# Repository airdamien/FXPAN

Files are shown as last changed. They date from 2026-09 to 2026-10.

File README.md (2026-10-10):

# FXPAN

Two Nikon D800 bodies behind one Nikkor-W 180 mm f/5.6. A 50 × 75 mm
beamsplitter sends each body half of the field. The stitch is

**64.80 × 23.9 mm · 2.711:1 · 13248 × 4912 · 65.1 MP**

XPan is 65 × 24 mm at 2.708:1. It is shot from f/5.6 to f/22. The
Nikkor-W covers the stitch wide open. The 44 mm mouths fully clear the
extreme corners from f/8.4; at f/5.6 those corners still pass most of the
light, and the long axis stays clean. The iPhone is the viewfinder and the
stitcher, and it can release both bodies over USB. A Pi Zero and the trigger
board are optional. They pulse both 10-pin remotes together.

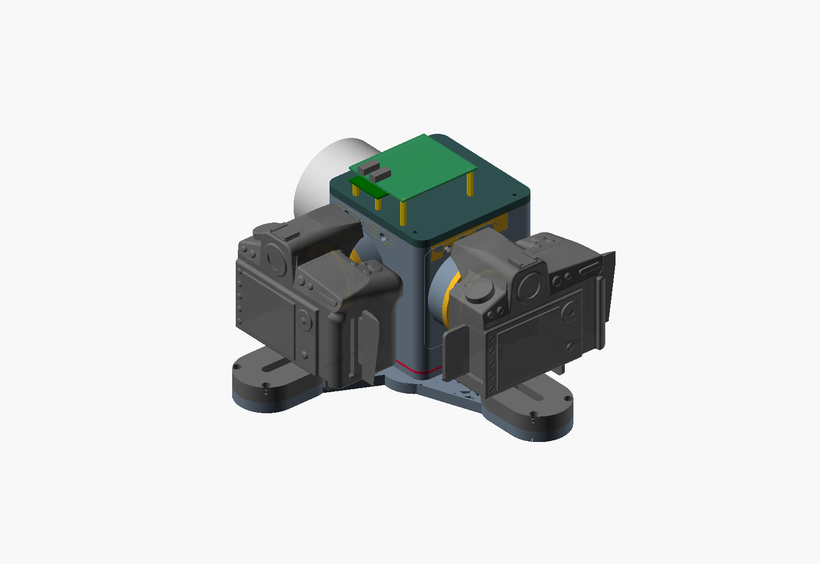
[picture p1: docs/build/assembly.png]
Assembled. Nikkor-W to the left, a D800 on each arm, trigger board on the lid.


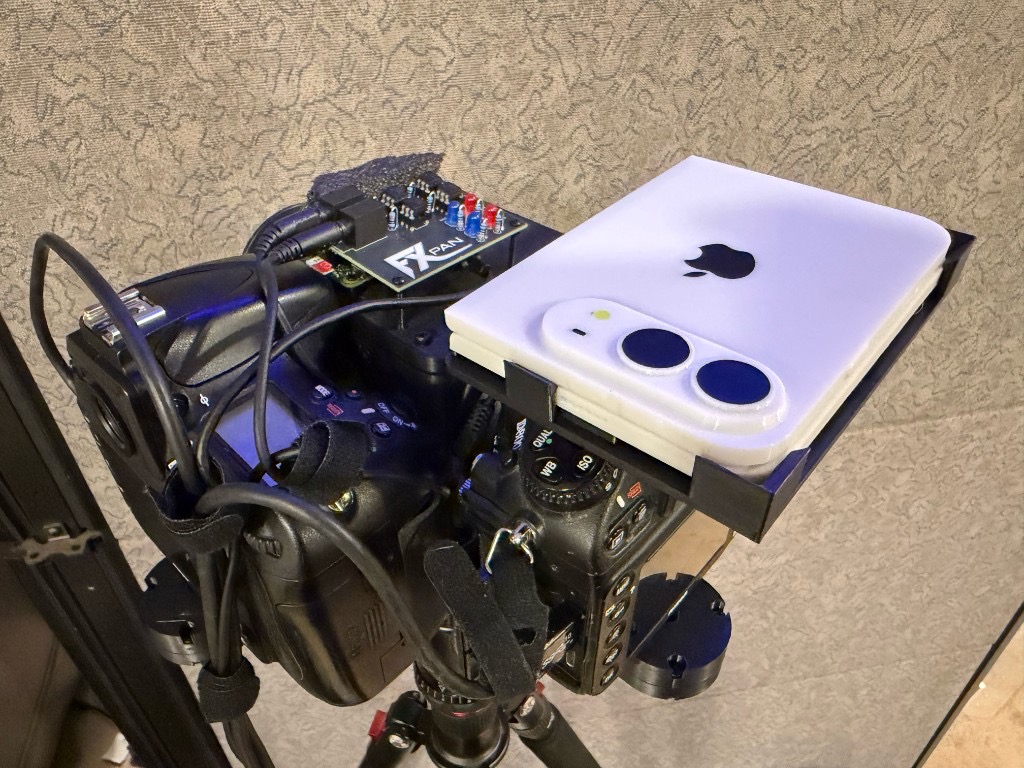
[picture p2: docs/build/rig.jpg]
The rig: two D800s, the trigger board, the iPhone


Buy list, print list, and assembly: [bom.md](bom.md).
The model, the measured focus numbers, and the long alignment notes:
[openscad/fxpan/README.md](openscad/fxpan/README.md).

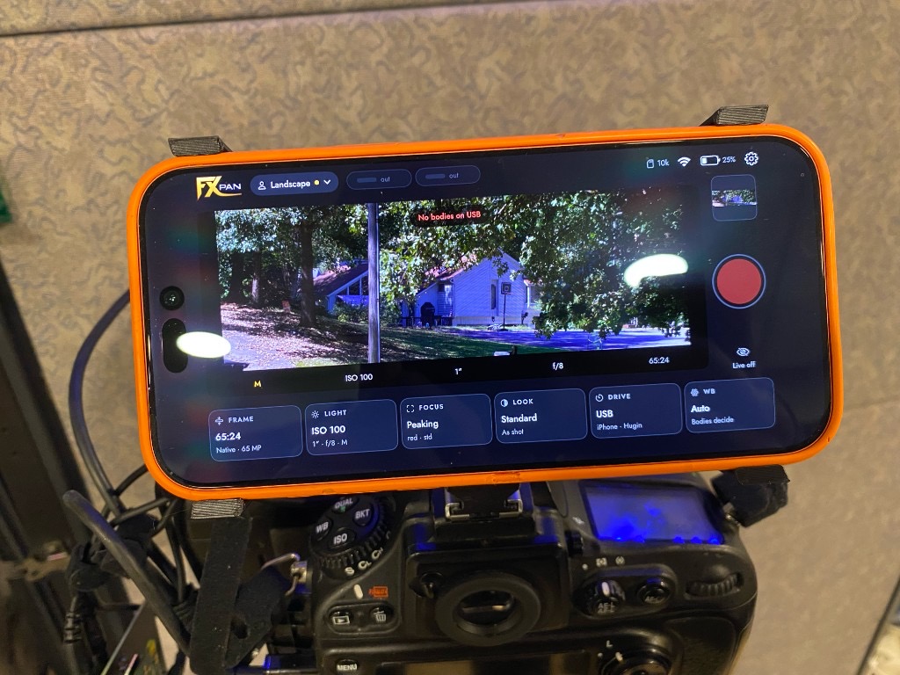
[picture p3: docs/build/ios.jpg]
The phone on the camera.


## On the phone

Landscape on an iPhone 17 Pro Max, in simulate mode.

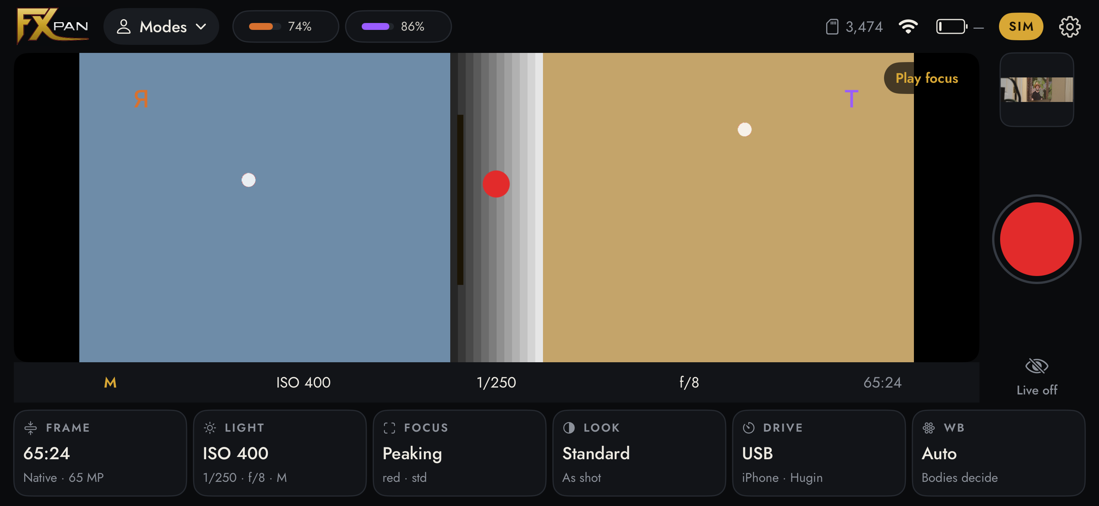
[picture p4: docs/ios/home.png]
Home. The stitch on the left, the shutter on the right, six controls along the bottom.


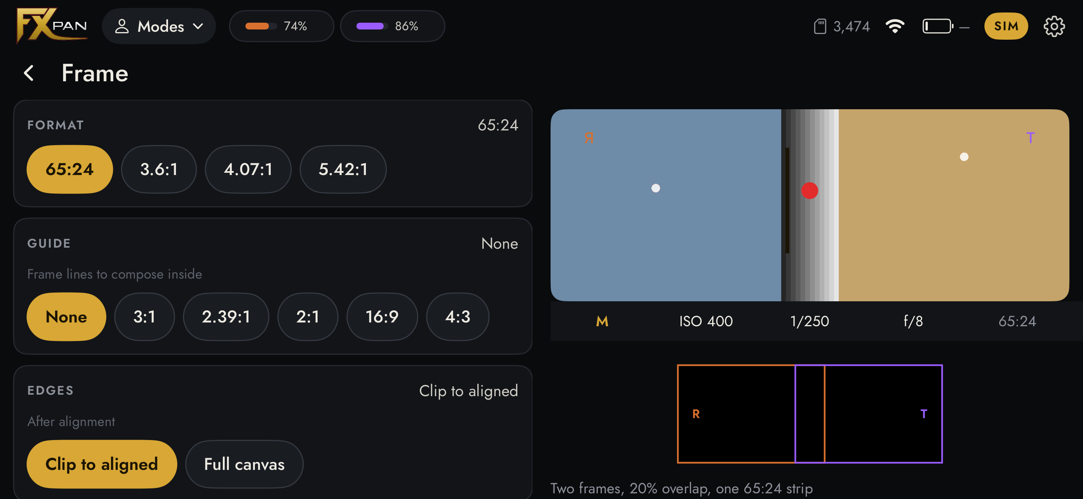
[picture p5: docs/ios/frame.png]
Frame. Format, guide lines, and whether the edges clip to the overlap.


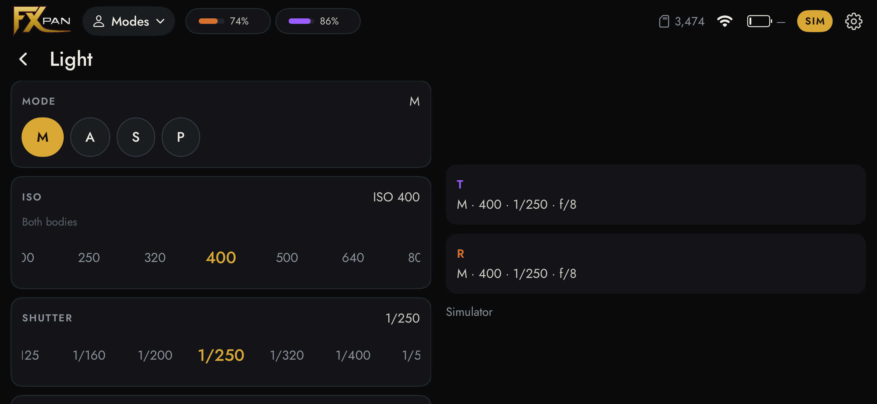
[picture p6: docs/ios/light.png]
Light. Mode, ISO, and shutter for both bodies.


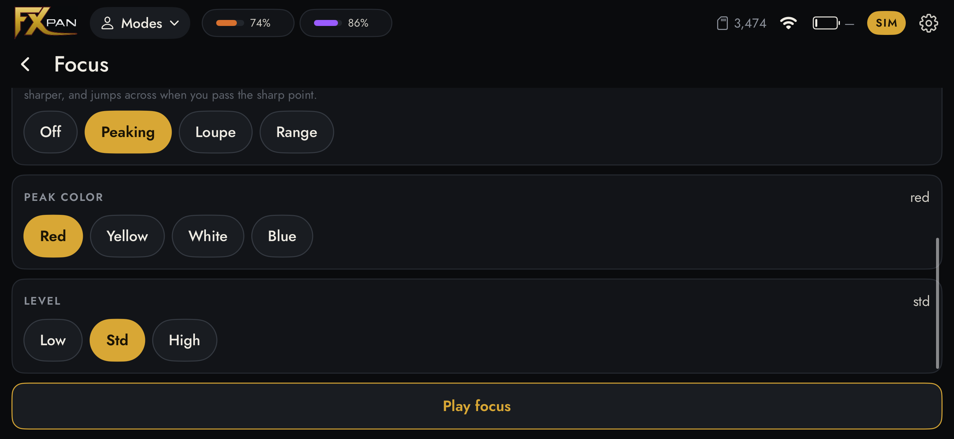
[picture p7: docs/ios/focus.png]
Focus. Peaking, loupe, or range.


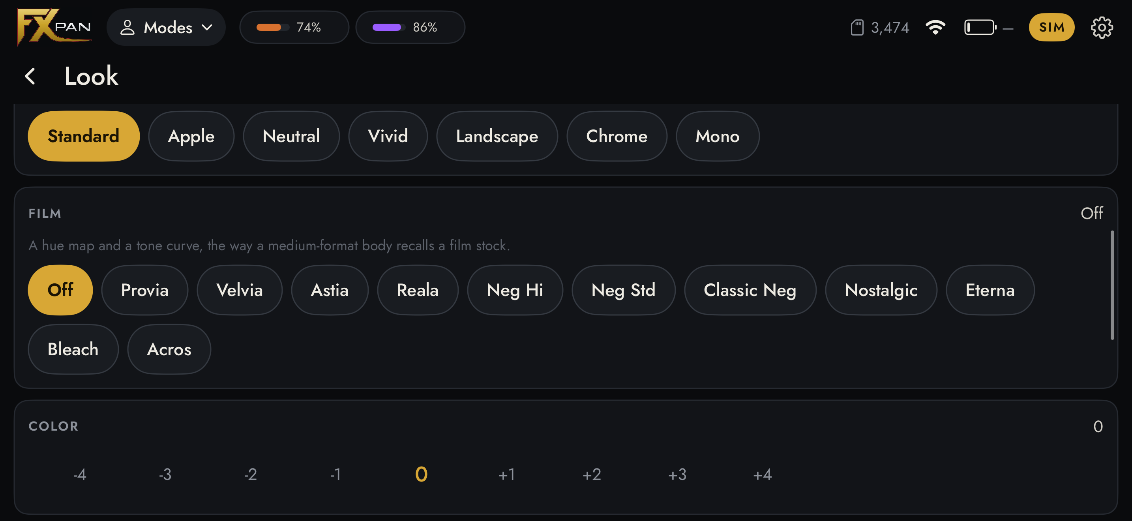
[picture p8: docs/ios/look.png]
Look. The base, the film stocks, and the color step.


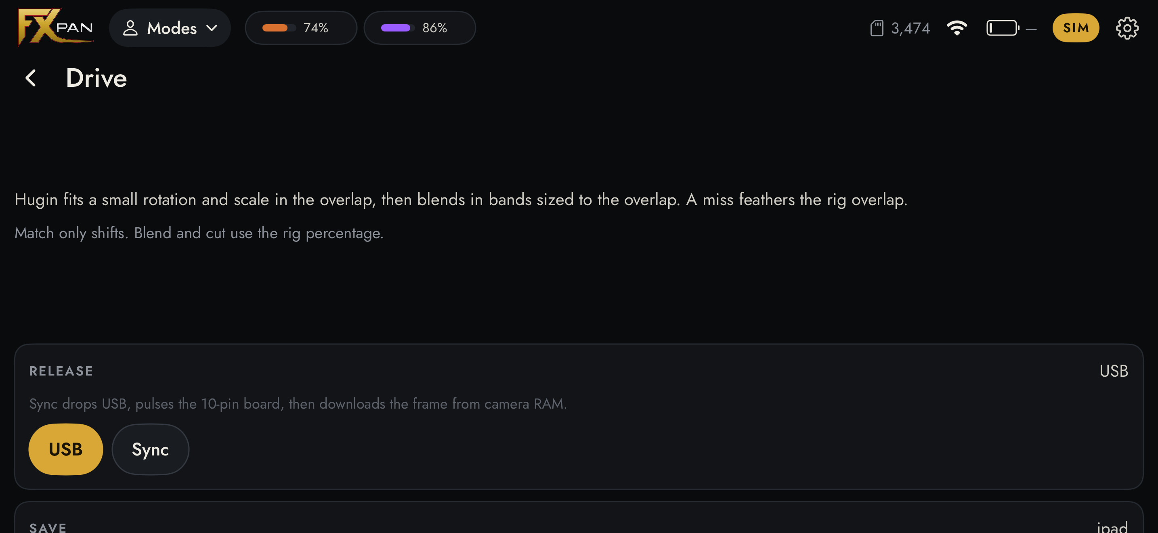
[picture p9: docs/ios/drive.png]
Drive. USB, or the 10-pin sync.


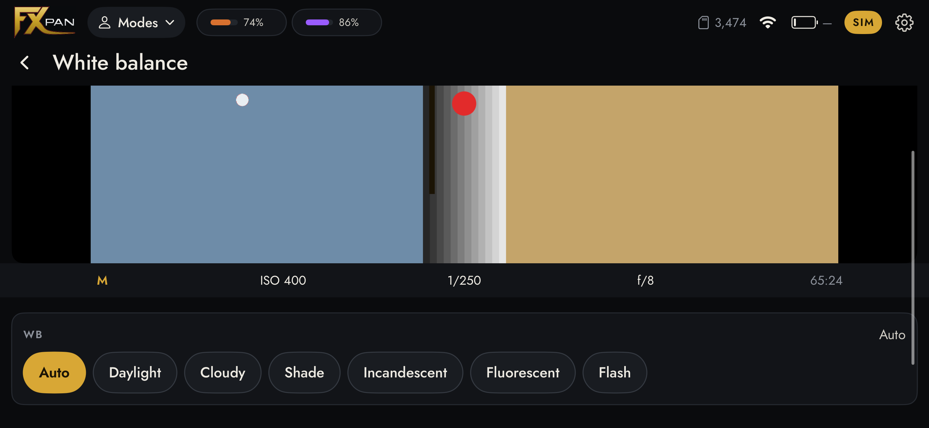
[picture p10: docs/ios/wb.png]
White balance.


Partly folded on an iPhone Duo. The picture and the last shots stay above the hinge. The controls and the shutter sit below it.

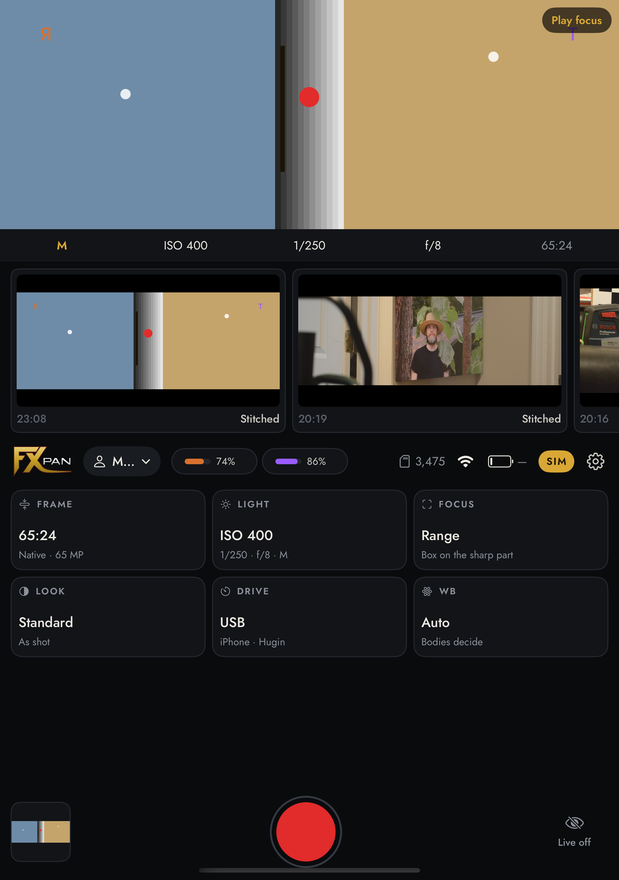
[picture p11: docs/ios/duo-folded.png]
Half open.


## Panoramic video

Drive chooses Still or Video. Video records both D800s, copies both clips
to the phone, lines the frames up, and stitches a panorama movie. The
shutter starts the recording and stops it. Each body writes a MOV on its
card, and that copy stays.

Both bodies are set up together. The record command then goes to both at
once, and the stop does the same. The phone keeps the few milliseconds
between the two starts, matches how the picture moves in each clip, and
drops the leading frames from the body that started first. Stitch again
runs that match and the stitch a second time.

Exposure is manual and shared: ISO, shutter, and aperture. Aperture is
written with live view down, which is when a D800 will take it. The bodies
are back on stills before the next frame.

One pair of frames sets the overlap, the warp, the crop, and the tone.
Every later frame uses that fit, with a multiband blend. A weak overlap
fit uses the rig's feather for the whole clip.

Playback plays the panorama, and each body's clip on its own. Share,
protect, delete, and Stitch again are there.

## A Canon, as a try

System has a Canon switch. It stays off until you turn it on. One body, not the pair, and not the stitch.

The camera's USB connection is photo import / remote control. Live view, the shutter, and the copy use that body. The JPEG shows in the roll. A CR3 is saved beside it. The file stays on the card. Turn the switch off and the Nikon pair is back.

## How it goes together

The plate is in the tray, coating toward the lens, 75 mm across the fold.
The two arms leave the box at a right angle. The base carries both bodies.
The mouths are printed F. The lens is the Nikkor-W.

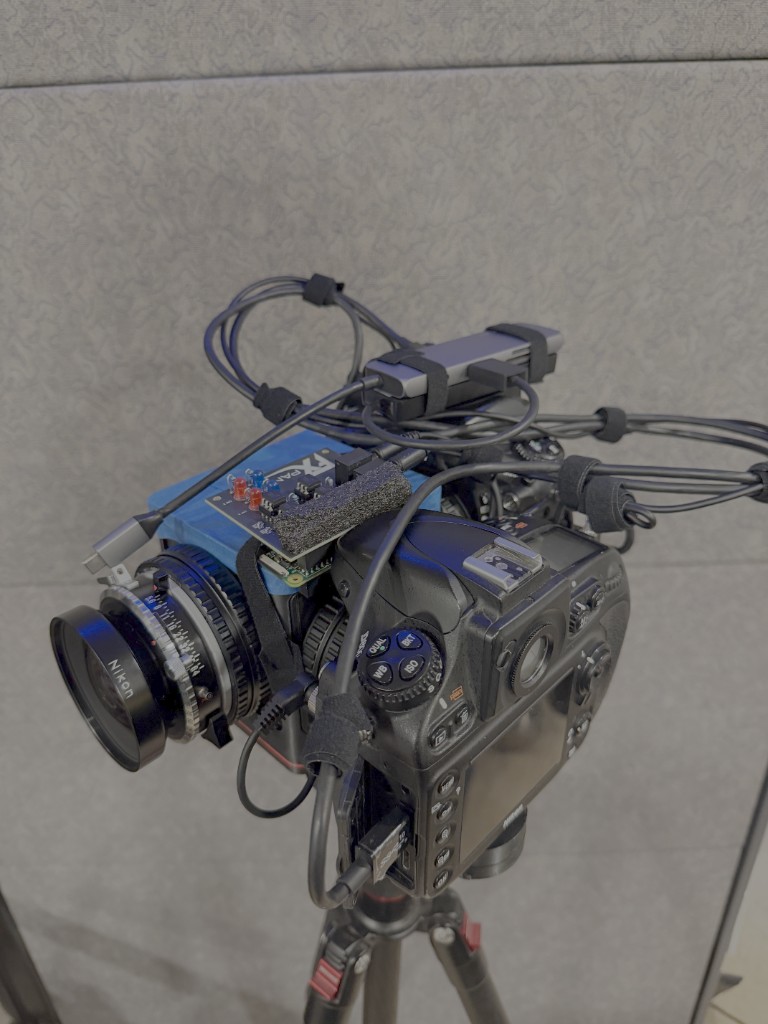
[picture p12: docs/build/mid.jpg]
Mid-build. One body on, the Nikkor-W in the stem, the trigger board on the lid.


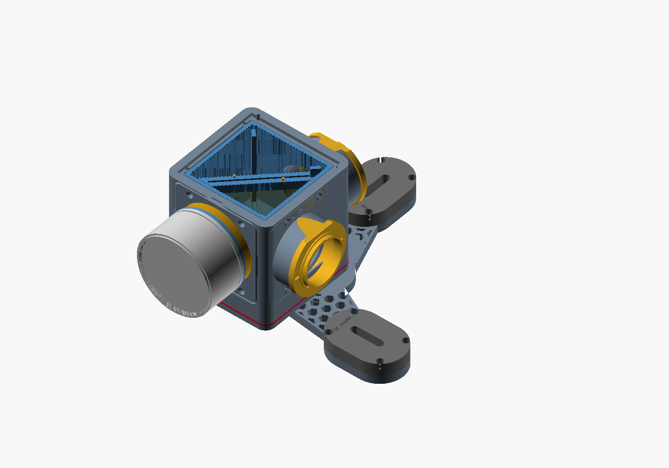
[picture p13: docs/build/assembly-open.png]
Lid off. The blue plate is the 50 × 75 mm splitter.


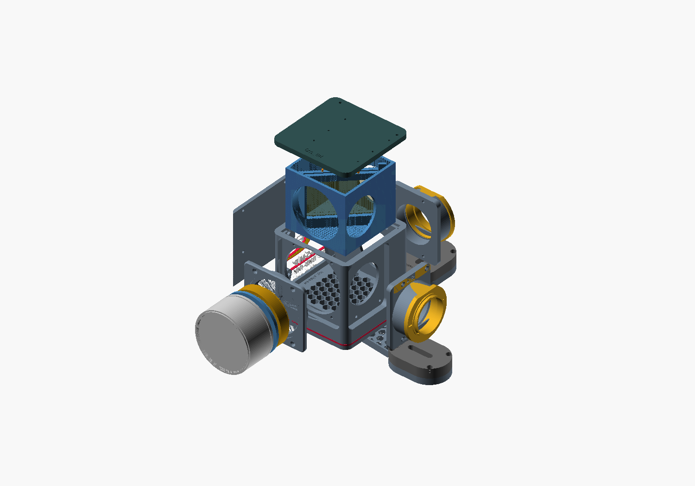
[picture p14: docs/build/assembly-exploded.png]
Pulled apart: lens, stem, arms, tray, lid, base.


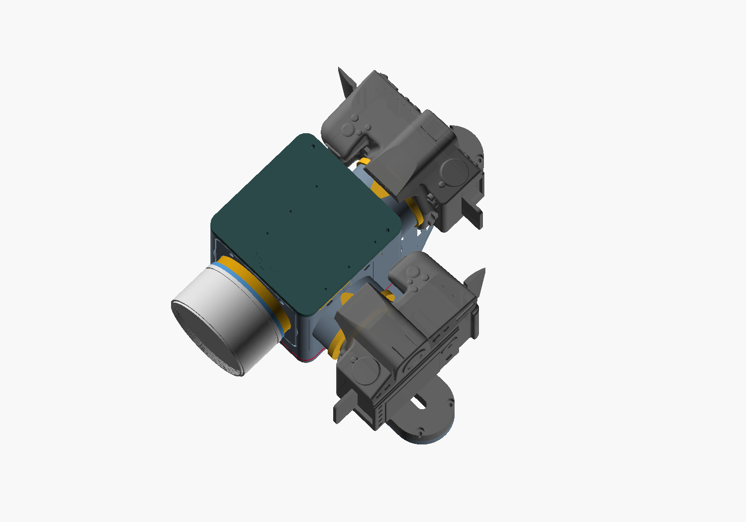
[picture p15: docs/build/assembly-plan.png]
From above. One lens, two bodies.


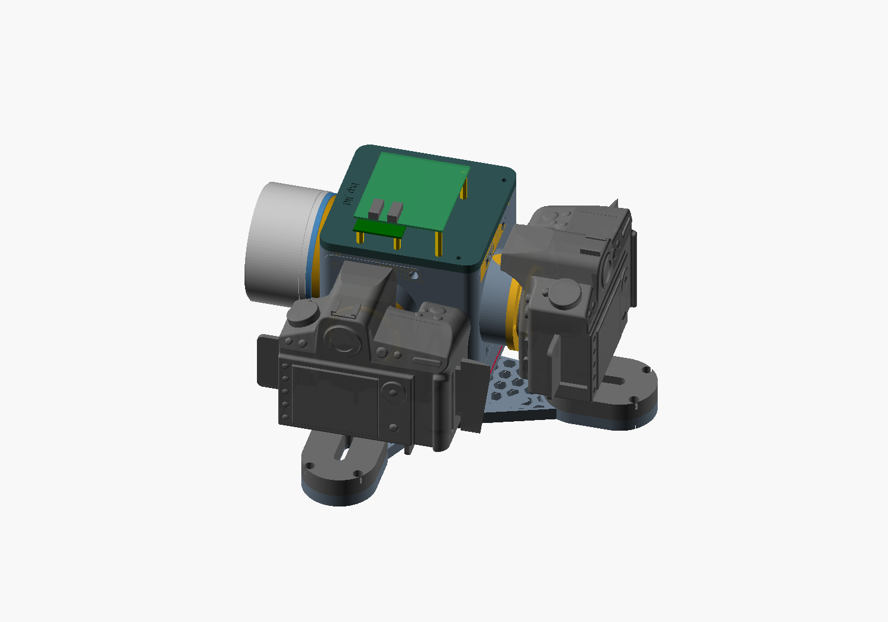
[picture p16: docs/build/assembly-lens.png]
The Nikkor-W and the trigger board, from the lens side.


The board is optional. USB release fires both bodies and brings the frames back. The board is the 10-pin path: blue is focus, red is shutter, one pair for each body.

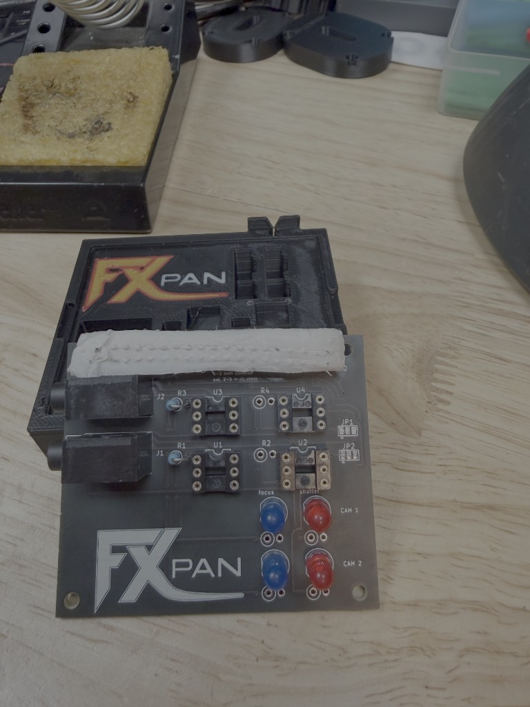
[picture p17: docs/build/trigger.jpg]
The built trigger board. Blue is focus, red is shutter, one pair for each body. USB release does not need it.


## What the two frames become

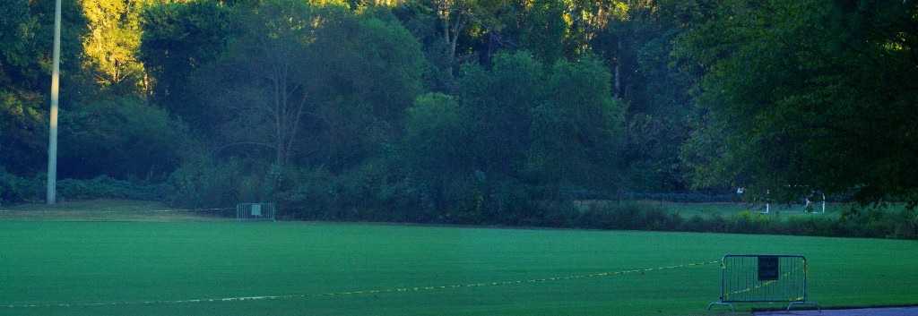
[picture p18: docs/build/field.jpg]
Field, stitched


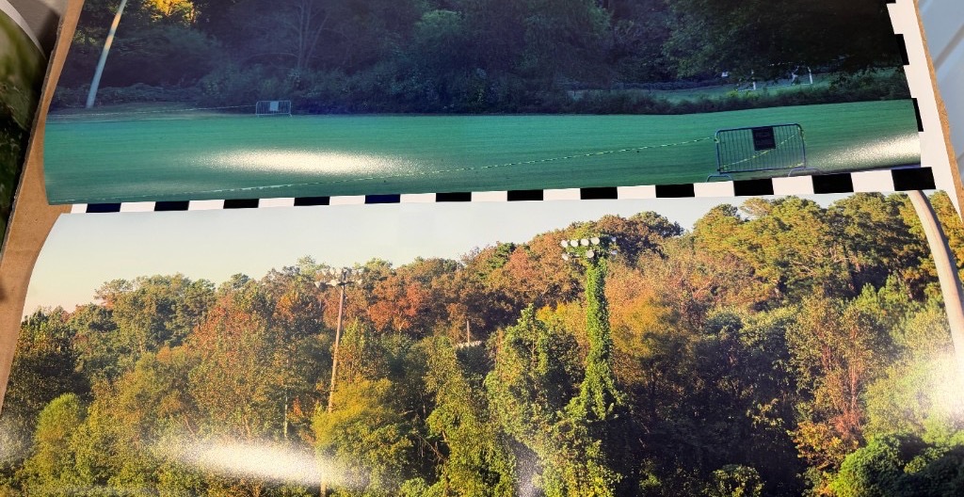
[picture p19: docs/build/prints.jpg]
Prints: the field, and the tree line


## The ray trace

The plate is 75 mm across the fold. At 45° that presents 53 mm, against the
44 mm the stitch needs at f/5.6.

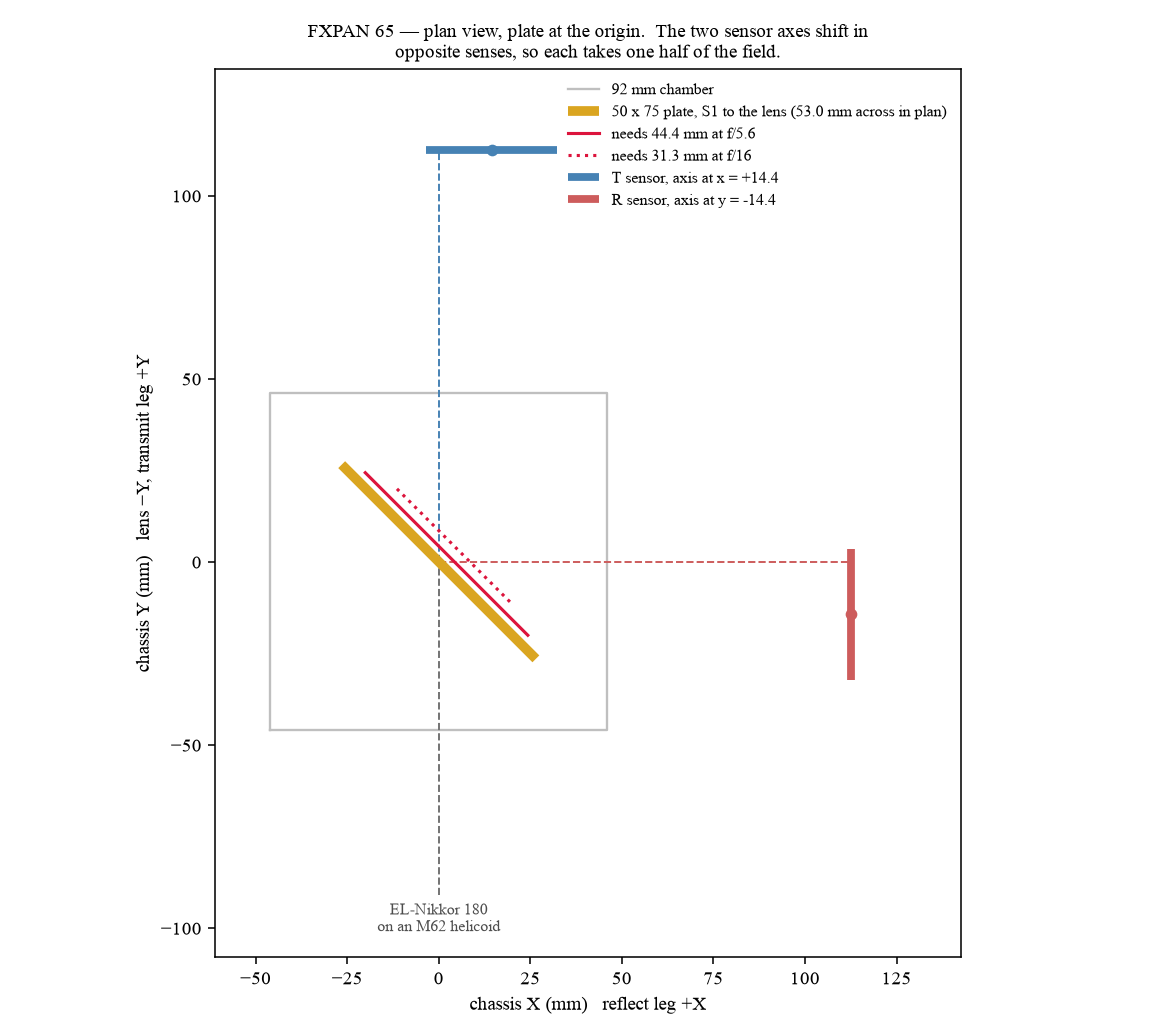
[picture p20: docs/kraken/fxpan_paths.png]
Plan of the fold


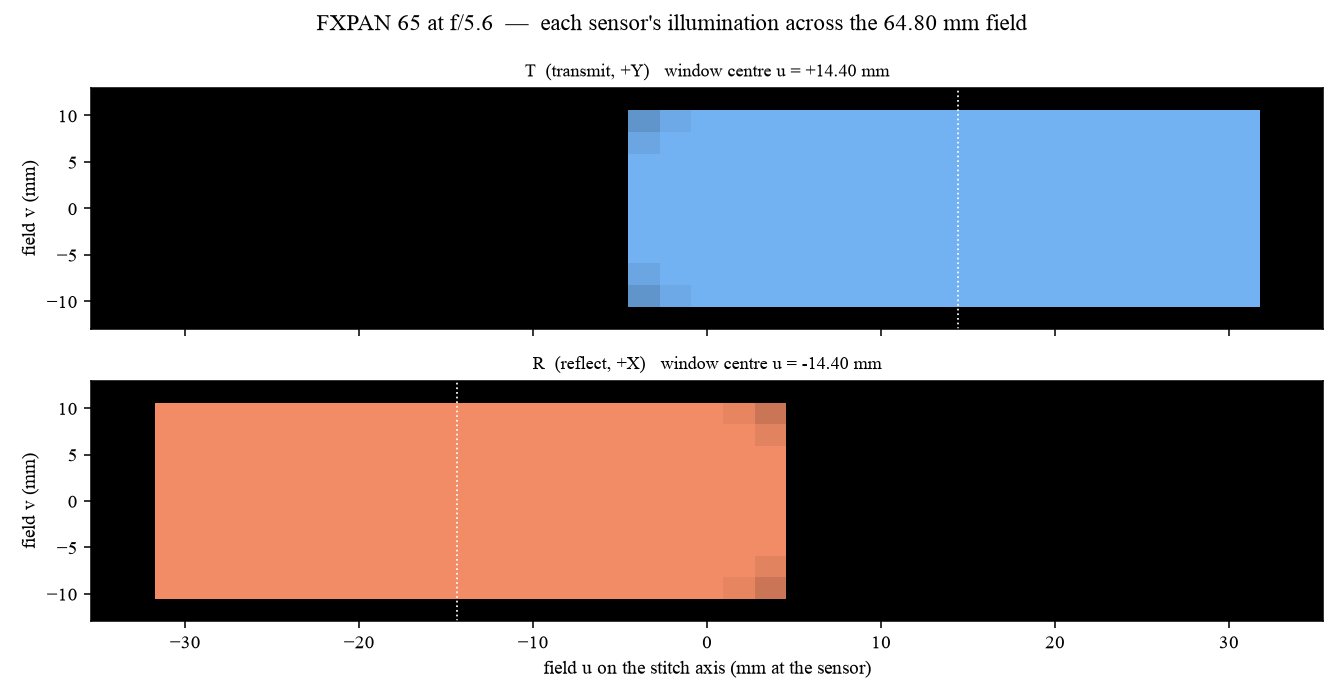
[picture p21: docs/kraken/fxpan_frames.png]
Each sensor at f/5.6


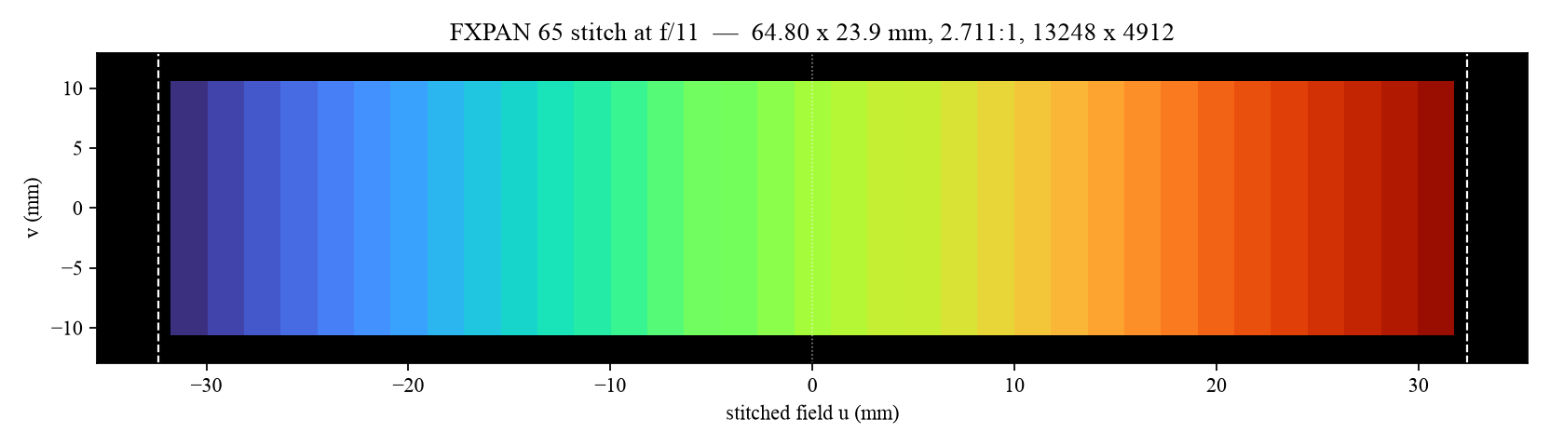
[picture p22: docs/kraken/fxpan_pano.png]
The stitch at f/11


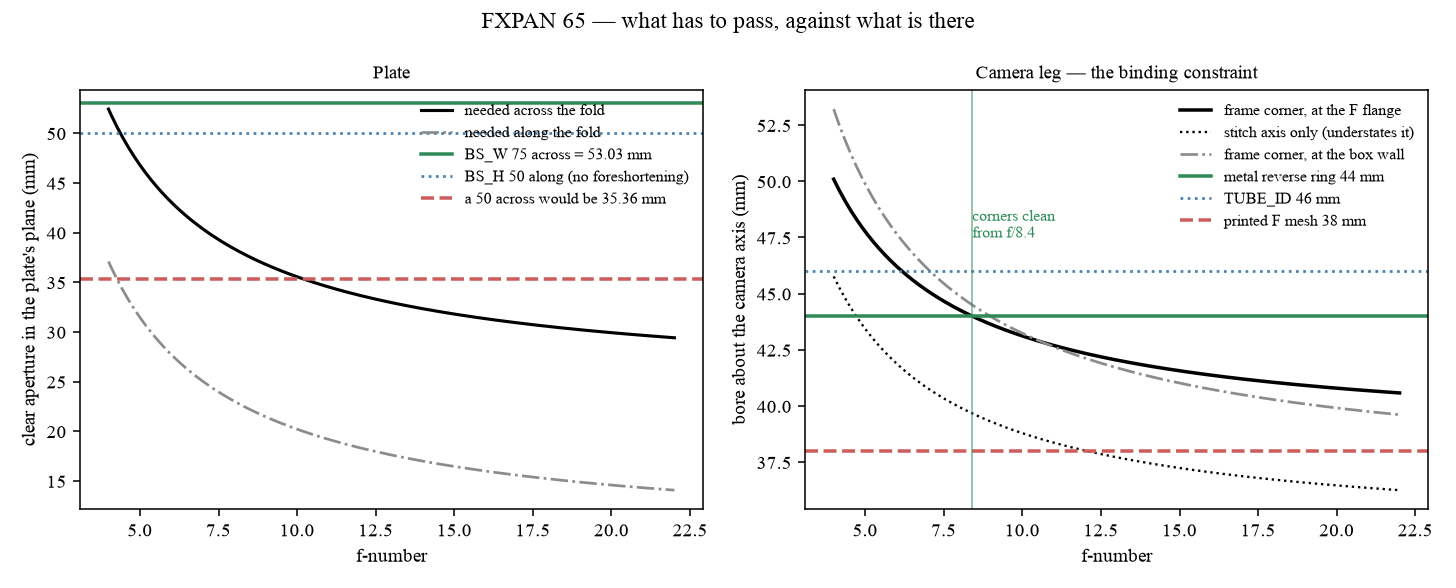
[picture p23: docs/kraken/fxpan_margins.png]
What has to pass, and what is there


A 2× anamorphic on the front of the 180 is drawn, not fitted on this rig.
Spherical is 20.3° at 50 m. 1.5× is 30.1°. 2× is 39.5°.

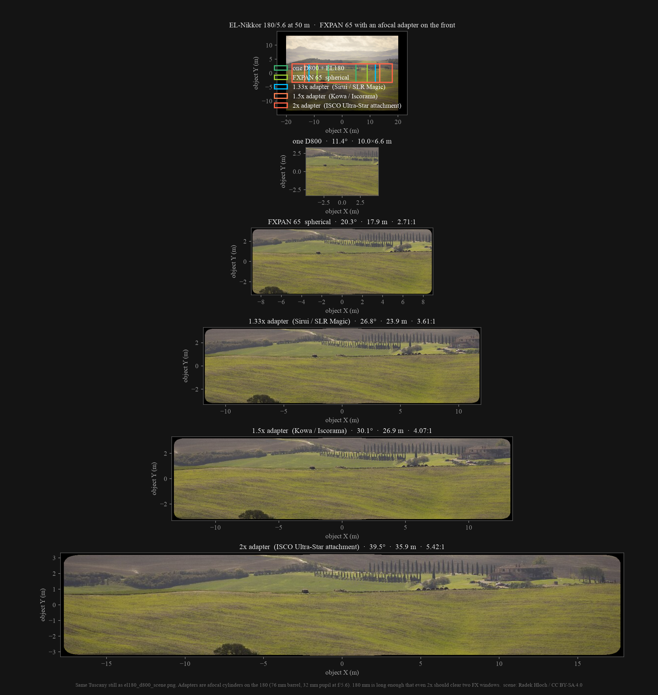
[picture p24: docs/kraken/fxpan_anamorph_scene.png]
Spherical against 1.33×, 1.5×, and 2×


```
python kraken/fxpan_paths.py    # exits non-zero if the body and the numbers disagree
python kraken/fxpan_scene.py    # the countryside above
```

## Where the rest went

The D7000 hybrid, the V, the shifted kits, the 5D and α7 forks, and their
export scripts are in [archive/](archive/EARLIER.md). They are not this camera.

## Credits

The D800s in the assembly pictures are mariusimv's approximate model,
[Thingiverse #4815092](https://www.thingiverse.com/thing:4815092).

The printed F mouths start from Archive-663's Nikon mount,
[CC BY-NC-SA 4.0](https://github.com/Archive-663/lensMounts).

The metric threads are Ryan A. Colyer's `threads.scad`,
[CC0](https://www.thingiverse.com/thing:1686322).

The earlier D7000 ghost and the stand-in lens barrel are José Pedro's
Nikon DSLR,
[Printables #1733741](https://www.printables.com/model/1733741-nikon-dslr-camera-model-3d-printable),
CC BY-NC-SA 4.0.

The monitor case is Wormfingers' HAMTYSAN 10.1 enclosure,
[Printables #1041827](https://www.printables.com/model/1041827-hamtysan-101-touchscreen-enclosure),
CC BY 4.0.

The Pi 4 in those older pictures is a Printables mesh, lined up to
[Raspberry Pi's mechanical drawing](https://datasheets.raspberrypi.com/rpi4/raspberry-pi-4-mechanical-drawing.pdf).

The countryside in the anamorphic figure is
[Radek Hloch, CC BY-SA 4.0](https://commons.wikimedia.org/wiki/File:Landscape_of_Tuscany_3.jpg).

The app is set in Jost, SIL Open Font License 1.1,
[The Jost Project Authors](https://github.com/indestructible-type/Jost).

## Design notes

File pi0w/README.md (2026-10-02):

# Pi Zero W GPIO trigger

The trigger board plugs onto the Zero W. The iPad is the USB host and powers the Zero through the data port. The Zero appears as a USB ethernet gadget. FXPAN will send one line to `10.55.0.1` port `2323`, and the Zero pulses the 10-pin jacks.

A D800 ignores the 10-pin remote while USB is claimed. The iPad has to end live view and close both camera sessions, wait, send `FIRE`, wait for `OK`, then open the sessions again and download.

This directory is the Zero side only. In the iPad app, set Release to Sync. The shutter then sends `FIRE` here.

## Hardware

The Zero W pinout matches the trigger board.

| BCM | Physical pin | Net |
|-----|---|-----|
| 20 | 38 | Focus, J1 and J2 while JP1 pads 1–2 are bridged |
| 21 | 40 | Shutter, J1 and J2 while JP2 pads 1–2 are bridged |
| 26 | 37 | J2 focus, only after JP1 is cut and pads 2–3 are bridged |
| 19 | 35 | J2 shutter, only after JP2 is cut and pads 2–3 are bridged |

If the Zero shows bare holes, solder a 2×20 male header with the pins pointing up. The board’s socket plugs onto that header. The board is Pi 4 sized, so it overhangs the Zero and the four screw holes do not line up. Leave it on the header. Do not force those screws.

Use the micro-USB port labeled **USB**, the data port next to the HDMI jack. The port marked **PWR** is power only. The iPad supplies power on the data port. Cable is USB-C to micro-USB, and it has to carry data.

## Flash

Use Raspberry Pi Imager and **Raspberry Pi OS Lite, 32-bit**. The Zero W is ARMv6. A 64-bit image will not boot.

In Imager’s settings, set the hostname to `fxpan-gpio`, create the user, and enable SSH. Join Wi-Fi for setup. Leave it on until the USB gadget answers. The install used to block Wi-Fi while you were still logged in over it, which dropped the session before the script finished. It does not do that now.

Boot, SSH in, and copy this directory onto the Zero:

```bash
scp -r pi0w fxpan-gpio.local:
ssh fxpan-gpio.local
cd pi0w
sudo ./install.sh
sudo reboot
```

`install.sh` adds `dtoverlay=dwc2,dr_mode=peripheral` and `modules-load=dwc2`, installs the gadget and the shutter service, and leaves Wi-Fi up. On a 512 MB Zero it also adds a swap file so `apt` does not run the board out of memory and reboot it. The stock `dnsmasq` service is masked so it cannot bind Wi-Fi. The gadget DHCP server is a separate unit and only listens on `usb0`.

## After reboot

The USB data port is now a network gadget, address `10.55.0.1/24`. The Zero hands the host `10.55.0.10`–`10.55.0.20` by DHCP. Plug it into a Mac first and check:

```bash
ping 10.55.0.1
nc 10.55.0.1 2323
```

Then type:

```text
PING
FIRE
FIRE 1000
```

`PING` answers `OK`. `FIRE` is the normal release: focus for 100 ms, then shutter for 300 ms. `FIRE 1000` holds the shutter for 1000 ms, which is the bulb path. The hold is capped at 120 seconds. Pins drop before the reply, including when the client hangs up mid-pulse.

```text
OK
OK focus_ms=100 shutter_ms=300
OK focus_ms=100 shutter_ms=1000
```

Then move the same cable to the iPad. The iPad should get a `10.55.0.x` address from the Zero, and Wi-Fi stays up. The lease has no gateway and no DNS, so only `10.55.0.1` goes over the cable. With Release set to Sync, the shutter sends `FIRE` to `10.55.0.1:2323`.

If the iPad already took a lease that named this board as the router, unplug the cable and plug it back in after this config is on the Zero.

## What got installed

| On the Zero | Source |
|---|---|
| `/usr/local/sbin/fxpan-gadget` | `fxpan-gadget.sh` |
| `/usr/local/sbin/fxpan-gpio` | `fxpan-gpio.py` |
| `/etc/systemd/system/fxpan-gadget.service` | `fxpan-gadget.service` |
| `/etc/systemd/system/fxpan-dhcp.service` | `fxpan-dhcp.service` |
| `/etc/systemd/system/fxpan-gpio.service` | `fxpan-gpio.service` |
| `/etc/fxpan/dnsmasq.conf` | `dnsmasq.conf` |
| `/etc/NetworkManager/conf.d/fxpan-usb.conf` | `nm-unmanaged.conf` |
| `dtoverlay=dwc2,dr_mode=peripheral` | appended to `config.txt` |
| `modules-load=dwc2` | appended to `cmdline.txt` |

Logs: `journalctl -u fxpan-gadget -u fxpan-dhcp -u fxpan-gpio`

The socket listens on `10.55.0.1` only, so it is not open on Wi-Fi. There is no password. The link is the USB cable.

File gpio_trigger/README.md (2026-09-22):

# Dual-GPIO Nikon trigger — Pi + 2× synced TRS

Breadboard building block based on [Building Block - Arduino Nano Remote Camera
Trigger](https://www.instructables.com/Building-Block-Arduino-Nano-Remote-Camera-Trigger/)
(Captive Image Photography, 2021): **two 4N35 optocouplers** (focus + shutter),
optical isolation, focus-before-shutter in software.

Adapted for this project:

| Instructables (Nano) | This build (Pi) |
|---|---|
| Arduino 5 V + battery/USB | **Pi 3.3 V GPIO only** — no separate supply, no battery |
| `camFocus` / `camShutter` on D2/D3 | **BCM 20** (focus), **BCM 21** (shutter) |
| One camera output | **Two TRS jacks**, same GPIO timing → both cameras fire together |
| Tactile test switches | `gpio_seq.py` (or `cam/gpio.py` later) |

Replaces the single-channel Corona clip path for D800 10-pin bodies that require
half-press before release.

## What the Instructables circuit does

Each camera line is a **switch to ground**, not a voltage source:

1. **Focus** opto pulls **Ring → Sleeve**.
2. **Shutter** opto pulls **Tip → Sleeve** while focus stays closed.

The Nano never ties its GND to the camera. Same rule here: Pi GND only returns the
opto **LED** current; camera ground is only on the **transistor** side (TRS sleeve).

## Dual synced outputs

One Pi fires **two identical TRS jacks** in parallel — one cable per D800 (no Y-lead
required on the trigger box). Each jack gets its **own** focus + shutter opto so load
and wiring stay independent; both opto LEDs on a channel share one GPIO through
**separate** series resistors (do not daisy-chain one resistor into two LEDs).

```
                         ┌── 330Ω ── 4N35 U1 ── J1 Ring (focus)
  Pi BCM 20 (focus) ─────┤
                         └── 330Ω ── 4N35 U3 ── J2 Ring (focus)

                         ┌── 330Ω ── 4N35 U2 ── J1 Tip (shutter)
  Pi BCM 21 (shutter) ───┤
                         └── 330Ω ── 4N35 U4 ── J2 Tip (shutter)

  J1 Sleeve ── U1 E + U2 E ── (camera A ground)
  J2 Sleeve ── U3 E + U4 E ── (camera B ground)

  Pi GND ── cathodes of all four LED sides (pins 2 on 4N35)
```

GPIO HIGH → LED on → phototransistor on → that TRS contact shorted to sleeve.

## 4N35 pinout (DIP)

```
     (pin 1) LED anode  ─── GPIO via 330Ω
     (pin 2) LED cathode ─── Pi GND
     (pin 3) NC (base)   ─── leave open
     (pin 4) emitter     ─── TRS sleeve (per jack)
     (pin 5) collector   ─── TRS ring or tip
     (pin 6) collector   ─── same as pin 5 (tie together) OR use pin 5 only
```

On **4N35**, pins 5 and 6 are both collector — either works. **PC817** is pin 1 anode,
2 cathode, 3 NC, 4 emitter, 5 collector.

## TRS → Nikon

| TRS | Function | Nikon 10-pin |
|-----|---|---|
| Sleeve | Ground | Pin 6 |
| Ring | Focus / half-press | Pin 9 |
| Tip | Shutter / full-press | Pin 4 |

**Sequence:** Ring→Sleeve, hold ~50–200 ms, Tip→Sleeve, pulse, release Tip, release Ring.

Cheap cables sometimes swap Tip and Ring — swap the two GPIO dupont wires at the Pi,
not the camera grounds.

**Connector:** **3.5 mm TRS** (3-pole stereo: tip / ring / sleeve). Same as the Corona
clip output and standard 3.5→10-pin Nikon cables. Not 2.5 mm, not 4-pole TRRS.

## Pi wiring

| Signal | BCM | Physical pin |
|---|-----|---|
| Focus | 20 | 38 |
| Shutter | 21 | 40 |
| GND | — | 39 (or any Pi GND) |

**Resistors:** Instructables uses ~220 Ω on 5 V Nano. On **3.3 V Pi use 330 Ω** per
opto LED (one resistor per LED, four total). Do not go below ~150 Ω.

**Do not** connect Pi GND to TRS sleeve.

## Software timing (from Instructables logic)

```text
digitalWrite(focus, HIGH);
delay(focusLead);
digitalWrite(shutter, HIGH);
delay(shutterPulse);
digitalWrite(shutter, LOW);
digitalWrite(focus, LOW);
```

Defaults in `gpio_seq.py`: focus lead **100 ms**, shutter pulse **300 ms**.

```bash
cd ~/nikonduals/gpio_trigger
python3 gpio_seq.py
python3 gpio_seq.py --focus 0.15 --shutter 0.3
python3 gpio_seq.py --hold-focus    # half-press only, for cable check
```

## Build steps (mirrors Instructables Step 1)

1. Fit **four 4N35** (or two per jack) and **two 3.5 mm TRS jacks** on perfboard.
2. **Input side:** each LED gets its own 330 Ω from the correct GPIO; all cathodes → Pi GND.
3. **Output side:** U1/U2 emitters → J1 sleeve; U3/U4 emitters → J2 sleeve.
4. U1 collector → J1 ring; U2 collector → J1 tip; U3 → J2 ring; U4 → J2 tip.
5. PCB: solder a **2×20 female socket** and plug the board onto the Pi GPIO header (pin 1 to pin 1). Only pins **38** (focus), **39** (GND), and **40** (shutter) are connected. Perfboard builds can use three dupont wires to those same pins.
6. Run `gpio_seq.py` with USB unplugged or released (D800 ignores 10-pin while USB is claimed).

Optional indicators, grouped on the board and labeled **focus** / **shutter** under **CAM 1** and **CAM 2**. Each is a 5 mm LED plus its own 330 Ω on the Pi side of the optos. **D1** / **D2** are camera 1 focus / shutter (pin 38 / pin 40). **D3** / **D4** are camera 2 focus / shutter: they follow pin 38/40 while JP1/JP2 are bridged, and pin 37/35 after you cut and bridge 2–3. Leave an LED and its resistor off together if you don't want that lamp.

## Enclosure / rig

- Both 3.5 mm jacks sit together on the **pin-1** end of the GPIO socket and face out that edge, away from the Pi's Ethernet port
- **J1** (upper jack) → D800 top (T). **J2** (lower jack) → D800 right (R)
- The 2×20 socket is soldered on the **bottom** and plugs onto the Pi. Square pad is pin 1
- Same electrical event on both jacks within opto + GPIO skew (sub-ms).

Your existing FlashZebra **Y-lead is optional** if this box already has two outputs.

## Schematics & layout

| File | Description |
|---|---|
| [schematic.svg](schematic.svg) | Electrical schematic (Pi → 4× 4N35 → 2× TRS) |
| [layout-perf.svg](layout-perf.svg) | Perfboard + Hammond 1591TBK placement |
| [layout-pcb.svg](layout-pcb.svg) | PCB: both jacks on the pin-1 end |
| [fab/pcbway/](fab/pcbway/) | PCBWay gerber zip |
| [netlist.csv](netlist.csv) | Wire-by-wire connection list |
| [BOARD.md](BOARD.md) | Assembly notes |
| [kicad/](kicad/) | KiCad project — full schematic + placed PCB footprints |

Regenerate: `python3 gen_cad.py`

## Parts list

See [bom.md](bom.md).

## Safety

- 4N35 isolation is mandatory — same rationale as the Instructables article.
- No battery: Pi powers only the opto LEDs; cameras bias their own remote lines.
- Unplug or USB-release before trusting 10-pin fire during bring-up.

## Reference

- [Instructables: Building Block - Arduino Nano Remote Camera Trigger](https://www.instructables.com/Building-Block-Arduino-Nano-Remote-Camera-Trigger/)

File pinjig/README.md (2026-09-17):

# pinjig

Browser tool that sits a color-coded print over a pin header so a HAT or clip can only go on the right pins.

Example: the **Corona Designs SLR shutter clip** on Raspberry Pi header pins **39 (GND)** and **40 (BCM 21)** — same pair `cam/gpio.py` pulses.

```
cd pinjig
python3 -m http.server 8766
# open http://127.0.0.1:8766/
```

Print a **0.5 mm** washer. Every hole is pin-tight (~0.95 mm). **Cap unused** is a shared cavity over neighboring unused pins (walls + roof), not a chimney per pin. Assigned pins stay open for the clip. Each device is a flush inlay in its 2.54 mm cells with a gap, so neighbors do not collide.

Load `body` + device STLs as **parts of one object** (keep original coordinates — do not auto-arrange). Files are binary STL in **millimeters** (`UNITS=mm` in the header). Notch = pin 1.

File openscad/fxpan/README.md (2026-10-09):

# FXPAN 65

The camera as built is a **Nikkor-W 180/5.6** in a Copal No. 1, on `stem_m65`
plus the M65×1 helicoid and `stem_nw_m65`, with printed F-mounts on
`arm_r_wl` / `arm_t_wl`. The bodies bolt to the cradles. The bayonet only
takes the twist. Buy list and assembly order: [../../bom.md](../../bom.md).

Two D800 bodies sit behind a 50 × 75 × 1 mm 50/50 plate at 45°. Each sensor
takes one half of the field and the two frames stitch to

**64.80 × 23.9 mm · 2.711:1 · 13248 × 4912 · 65.1 MP**

XPan is 65 × 24 mm at 2.708:1, so the aspect is within 0.1%.

**Shot from f/5.6 to f/22.** The Nikkor-W covers the stitch wide open.
f/8.4 is the stop where a 44 mm mouth passes the last corner ray. At f/5.6
that corner still gets most of the pupil and the long axis gets all of it,
which is a mild shade, not a dark corner. The printed mouths are bored to
the same 44 mm. The plate is not what limits the frame.

Open [`WATCH_ME.scad`](WATCH_ME.scad) and read the console. It echoes the
optical budget, marks anything that clips, and tells you how many baffle
rings are worth printing at the aperture you picked. To check it, run
[`../../kraken/fxpan_paths.py`](../../kraken/fxpan_paths.py) — it ray traces
the body and exits non-zero if the geometry and the numbers stop agreeing.

| | |
| --- | --- |
| Plan view and the fold | [`fxpan_paths.png`](../../docs/kraken/fxpan_paths.png) |
| Body ghosts against the chassis face | [`fxpan_body_fit.png`](../../docs/fxpan_body_fit.png) |
| Each sensor's falloff at f/5.6 | [`fxpan_frames.png`](../../docs/kraken/fxpan_frames.png) |
| The stitch at f/11 | [`fxpan_pano.png`](../../docs/kraken/fxpan_pano.png) |
| What has to pass vs what is there | [`fxpan_margins.png`](../../docs/kraken/fxpan_margins.png) |

Shares no printed part with the earlier bodies. Everything is stamped
`fxp_*`. [`PLAN.md`](PLAN.md) has the derivations. [`bom.md`](bom.md) is the
longer parts list, including stems this camera does not use.

## Before you print

**Buy the 50 × 75 × 1.0 mm plate, and put the 75 across the fold.** A plate
at 45° presents only `size/√2` in its plane of incidence, and that is the
direction the 64.80 mm stitch has to cross: the frame needs 44.4 mm there at
f/5.6 and 75 mm gives 53.03. Along the fold there is no foreshortening and
nothing to carry but the 23.9 mm sensor height, so 50 mm is already plenty,
and that is the direction that sets chassis height. Fitted the other way
round the stitch crosses 35.36 mm and clips the long axis of the panorama.
The tray slot is keyed. The black dot (S1) faces the lens.

**The arms are printed F, at the registers this rig measured.** `arm_r_wl`
is 23.00 mm, `arm_t_wl` is 22.62 mm, so both bodies peak at the same setting
of the lens helicoid, about 1 mm out from collapsed. The cradles carry the
weight. Reprint `arm_r_wl` if a later pair does not meet; the alignment
section has the three numbers that move.

**The body's front panel has to clear the tube when you twist it on.** Lay a
straight edge across the D800's front and measure back to the bayonet
register. The default `D800_PROUD` is 13 mm. These arms clear by 3.12 mm (T)
and 3.50 mm (R). If a different body measures past that, change
`D800_PROUD` and reprint. The console says when the chassis can no longer
reach infinity.

## Print list

```
./export_fxpan.sh
```

STLs land in `stls/fxpan/`. This camera uses the rows below. PETG or ABS,
not PLA. The mouths and the cookie screws carry the bodies.

**Print `full`, one material.** Flock the chamber. The arms and the stem
should come off the same spool: the two legs have to agree to a fraction of
a millimetre.

| part | quantity | bed orientation |
| --- | --- | --- |
| `chassis` | 1 | floor down. The lens face is relieved to an 83.7 mm circle so the M65 helicoid seats on the cookie. On the logo side a 3 mm post rises from the logo window's sill to 6 mm over the floor, so the tray cannot slide into the window |
| `lid` | 1 | outer face down. Two screw holes, at the +Y corners, match the chassis. Six 2.2 mm blind holes, 5 deep, take the trigger stack's M2.5 standoffs |
| `fxp_tray` | 1 | floor down |
| `stem_m65` | 1 | cookie flange on the bed, boss up. Thread start turned 90° counter-clockwise facing the cookie (`STEM_W_CLOCK`), so the bottomed Nikkor-W has its shutter controls on top |
| `stem_nw_m65` | 1 | Copal board up, male down on a raft |
| `arm_r_wl`, `arm_t_wl` | 1 each | cookie flange on the bed, printed F up. Fixed registers 23.00 (R) and 22.62 (T). No camera helicoids |
| `base` | 1 | flat. Tripod insert and screw heads enter from the bed. 176 × 190 mm. Each camera slot runs along that camera's lens axis |
| `cradle_r`, `cradle_t` | 1 each | flat. 12 mm tall so the body sits on the plinth before the tripod screw is tightened |
| `baffle` | 2 sheets | flat. One arm's rings per sheet, four rings at the f/11 default |

Colour inlays, if you want the badge in filament rather than paint:

| STL | suggested |
| --- | --- |
| `chassis_logo_fx` | gold |
| `chassis_logo_word` | off-white |
| `chassis_logo_outline` | red |
| `chassis_logo_mp` | red (65MP) |
| `chassis_logo_rule` | any accent |
| `chassis_logo_spec` | grey (`NATIVE  13248×4912 · 2.71:1`) |
| `chassis_logo_ana_mp` | gold or a second red (130MP) |
| `chassis_logo_ana_rule` | any accent |
| `chassis_logo_ana` | grey or gold |
| `chassis_logo_stripe` | Nikon pro red |

The plugs overrun the pocket — 0.08 mm into the walls and floor, 0.06 mm
proud of the face — so the slicer resolves each colour. `chassis_logo` is
the lot merged if you would rather paint one part. The stripe is a 1.6 mm
groove 5 mm up from the floor.

**The cookies go down flat.** R6 corners, a 1.2 mm chamfer on the outer
edge, and the outer face clipped to the chassis profile, all of that on the
top. The bed face is the full flat plate. No supports. Each cookie is a
rectangle centred on its bore: **77.8 × 62 for an arm, 77.8 × 74 for the
stem**.

## Assembly

1. **Inserts.** Press a 1/4-20 insert into the `base` tripod pad from the
   underside, and one into the chassis floor pad.
2. **Flock** the chamber, the tray's inner faces, both arm bores, and both
   printed F throats. The tray's ribs and the arms' baffle ribs do most of
   the work. The throat has no liner on purpose; a liner there vignettes.
3. **Baffle rings**, if you printed them. One set per arm, pushed down the
   bore from the camera mouth: `fxp_bf1` first and deepest. Each ring is
   sized to its station, so they must not be shuffled. Four at the f/11
   default, five at f/16, none at f/5.6. Reprint the set if you change
   `FSTOP`.
4. **Plate into the tray.** The black dot faces the lens. The plate is
   **75 mm across, 50 mm up**. The slot is keyed for both. Two 2 mm holes on
   the cheeks take a scrap of 1.75 mm filament so the plate cannot lift.

   **Centring ribs.** Opposite ribs leave 1.10 mm for the 1.0 mm glass, so
   it sits on the slot centre. Off-centre glass moves R's focus and rolls
   the reflected image. Press it straight down. If it will not go, scrape
   the same amount off each rib.

5. **Lid nuts, then the tray.** Push an M3 nut into each of the two slots
   under the rim in the +Y corners, until it stops on the screw axis. Then
   the tray goes in, floor down, and its wall closes both slots. The
   retention posts go up into the lid.
6. **Cookies into their rebates.** Four M3 × 12 countersunk per cookie. The
   screws are the only thing holding a cookie in. The arm cookies read
   **▲ R FXP** and **▲ T FXP**; the chassis carries the same mark beside
   each pocket. The stem cookie is stamped `fxp_stem`.
7. **Lid** with two M3 × 20 into the +Y corner nuts. Edges flush with the
   chassis. The trigger stack goes on top, jacks toward R. Bottom up it is
   the Zero W with its header in from underneath, then the trigger board on
   the header. Four 10 mm M2.5 male-female standoffs into the inner four
   blind holes.
8. **Base.** Chassis onto the origin pad with a 1/4-20 thumbscrew. Each
   cradle gets four M3 × 16, heads in the plinth, nuts under the base.
9. **Bodies.** Start the 1/4-20 × 25 up through the slot and leave it loose.
   Bayonet the body onto the printed F, then tighten the screw where the
   body landed. Do not pull the body onto the mount with the screw. The
   plinth takes the weight. The bayonet takes the twist.
10. **Lens.** M65 helicoid into `stem_m65` until its body sits on the cookie.
    `stem_nw_m65` into the front. The helicoid body is 82.67 mm across, wider
    than the cookie's 80 mm rebate, which is why the chassis face is opened
    to 83.7 mm. Copal controls on top. Both bodies need a card before a
    synced release.

Before the bodies go on, check `D800_AXIS_BASE` (lens axis above the
baseplate, default 52.0 mm) and `D800_TRIPOD_IN` (along the base, default
44 mm) against your own cameras, then reprint `base` and the cradles if
they differ. The chassis skirt is solved from `D800_AXIS_BASE`. If it is
wrong, both cameras sit off the optical axis by the same amount.

## Alignment

Focus, then roll, then the overlap. These numbers are from this rig.

**Focus.** The field test with the lens seated straight in `stem_m65` put R's
camera-side focus at the end of its travel and T past it, so focus moved to
the M65 on the lens and the arms were shortened to meet it. The lens helicoid
lifts the lens 16.58 mm. T's arm is 22.62 mm. On the first prints the lens
helicoid (cookie face to lens face) peaked T at 17.81 and R at 20.38, so R
was reprinted 2.57 mm longer, at 23.00, and both peak together.

1. Collapse the helicoid, then open it until a distant target peaks on T.
   That is about a millimetre.
2. Check R on the Focus screen at the same setting.
3. If R peaks somewhere else, the difference in helicoid height is how far
   R's arm moves. Set `W_LENS_FOCUS_T` and `W_LENS_FOCUS_R` to the two
   heights, `W_WL_PRINTED_R` to the R arm you measured, and reprint
   `arm_r_wl`.

**Roll.** Shoot a level horizon on both. The seam is horizontal, so relative
roll is a wedge. `STEM_W_CLOCK` is 90°, which puts the Copal controls on
top. Body roll is the printed F. Set `F_MOUNT_CLOCK` and reprint that arm
if a body comes up on its side.

**Field.** Shoot something with detail across the frame and stitch it on the
phone. Overlap starts at 20%. Far from that means a cookie is in the wrong
port.

## Apertures

Stopping down shrinks the bundle, so the body does not start vignetting
again on the way to f/22. The corners are the place to read it: a
36 × 23.9 mm window's corner sits 21.6 mm from centre.

| f-stop | plate across the fold (53.03) | plate along it (50) | 44 mm bore | traced corner |
| --- | --- | --- | --- | --- |
| 5.6 | 44.4 mm · +19.5% | 29.1 mm · +72% | 46.8 mm · clips | 0.836 |
| 8 | 38.4 mm · +38.2% | 23.0 mm · +117% | 44.3 mm · clips | 0.951 |
| 11 | 34.5 mm · +53.6% | 19.2 mm · +161% | 42.7 mm · clears | 1.000 |
| 16 | 31.3 mm · +69.3% | 16.0 mm · +213% | 41.4 mm · clears | 1.000 |

The plate is never the constraint. The long axis of the panorama is clean at
every stop, including f/5.6. Only the corners shade, and they clear as the
lens stops down. The along-the-fold column is why the plate is 50 mm there
and not 75: that margin was never going to be spent, and buying it cost
25 mm of chassis height.

Set `FSTOP` in the customizer to see any aperture. Falloff maps:
[`fxpan_frames.png`](../../docs/kraken/fxpan_frames.png) and
[`fxpan_margins.png`](../../docs/kraken/fxpan_margins.png).

## What this body is not

It is a **20.4° horizontal** field. 65 mm of frame at 180 mm compresses
distant landscape. The aspect matches XPan. The angle of view does not.
Going wider means a shorter lens, and the path has to equal the focal
length, so that is a new body.

The two 50 mm first-surface mirrors are not used here. Coplanar folds cannot
make the two bodies parallel. They stay with the V body.

## Other parts the model still exports

`./export_fxpan.sh` also writes the earlier stems and mouths. They are not
on this camera. The longer list is [bom.md](bom.md). The derivations are in
[PLAN.md](PLAN.md).

| part | what it was |
| --- | --- |
| `stem`, `stem_el180_inf`, `el180_adapter`, `m65_ring` | EL-Nikkor 180/5.6N on an M62 helicoid. A different lens and a different flange. |
| `arm_r`, `arm_t` | M52 × 0.75 female for a metal 52 mm F reverse ring. `ringgauge` fits that thread. |
| `arm_r_f`, `arm_t_f`, `arm_r_fw`, `arm_t_fw`, `arm_r_focus` | Earlier printed-F lengths, before the measured `wl` registers. |
| `arm_r_hw`, `arm_t_hw` | Bought M52-female / M42-male camera helicoids and a metal F ring, if focus is on the cameras instead of the lens. |
| `stem_nw_direct` | Nikkor-W straight into `stem_m65`, no lens helicoid. The male is 0.8 mm fatter so it threads snug. This is the nose the field test was shot on, before focus moved to the M65. |
| `shims` | 0.2 / 0.5 / 1.0 mm, for a reverse-ring mouth. The `wl` arms are fixed; a miss there is a reprinted `arm_r_wl`. |

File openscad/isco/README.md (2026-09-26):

# ISCO / EL-Nikkor 180/5.6N

Measured models for the taking lens and the ISCO Ultra-Star HD Cinemascope
attachment used on the FXPAN 65 anamorphic build.

Open [`WATCH_ME.scad`](WATCH_ME.scad). Solids to include elsewhere:

- [`el_nikkor_180n.scad`](el_nikkor_180n.scad)
- [`isco_ultrastar_attachment.scad`](isco_ultrastar_attachment.scad)

Exported envelopes live under [`../../stls/isco/`](../../stls/isco/).

**Clamps** that mount the ISCO on the taking lens (EL-Nikkor M62 or
Nikkor-W Ø73 land): [`clamps.md`](clamps.md) and [`bom.md`](bom.md).

## EL-Nikkor 180/5.6N

Origin is the seating face, the back of the Ø76 body where the M62 thread
starts. +Z is the front of the lens. −Z runs through the thread toward the
focal plane.

| | mm | |
| --- | ---: | --- |
| Barrel | 76 | straight down to the mount thread |
| Rear barrel | 60 | continues through the mount thread |
| Mount thread | M62×1 × 8 | starts at the seating face |
| Past the thread | 9.2 | this lens, Ø60 |
| Front rim | 53.1 | ahead of the seating face |

See the existing notes in this file's git history for register and optical
stations. `SHOW_GLASS` draws pupils and vertices; they are not in the STL.

## ISCO Ultra-Star HD Cinemascope attachment

2× afocal front adapter (the gold/orange cylinder from the HD Plus turret).
Origin is the **rear face** — the plane that faces the taking lens / clamp.
+Z is the front, toward the subject.

| | mm | source |
| --- | ---: | --- |
| Rear thread OD | **67.0** | measured |
| Rear tube OD | **70.6** | measured — US turret; RafCamera **71 mm** clamp |
| Front tube OD | 90.0 | KuSeRa / community — **caliper** |
| Input barrel | **90** | front, light in |
| Overall | **~165** | barrel rear face to front rim |
| Thread past the face | **5** | Ø67, measured; pitch not measured |
| Rear face to first step | **70** | the Ø70.6 clamp land |

The photos are a stepped barrel, not a cone: black Ø67 rear ring, long
Ø70.6 gold tube, two focus-scale collars, a knurl, then the front lip.
Those in-between diameters are read off the photos. Caliper them if a
clamp or a collar has to land on one.

Clamp onto the **70.6 mm rear tube**, not the thread. Printed clamps:
[`clamps.md`](clamps.md). FXPAN anamorphic options:
[`../fxpan/bom.md`](../fxpan/bom.md).

### Still to measure

The `L_*` stack in `isco_ultrastar_attachment.scad` sums to `L_OAL`.
Replace a length or a diameter when you caliper that land.

### Stack preview

`PART=stack` puts the attachment rear face at the EL-180 front rim
(`z = 53.1`). Set `CLAMP_GAP` if a collar sits between them.

Export:

```bash
./export_stls.sh --isco el_nikkor_180n isco_ultrastar isco_clamp isco_clamp_nw isco_stand
```

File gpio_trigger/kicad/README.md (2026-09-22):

# KiCad project

1. Open `gpio_trigger.kicad_pro` in KiCad 9.
2. Schematic and PCB are generated by `python3 ../gen_cad.py` — parts placed, traces routed, bottom GND pour filled.
3. Both 3.5 mm jacks are on the pin-1 end of the header (away from the Pi Ethernet jack). Solder the 2×20 socket on the bottom.
4. Fabrication zip: `../fab/pcbway/gpio_trigger-pcbway.zip`.

Reference drawings: `../schematic.svg`, `../layout-pcb.svg`, `../layout-perf.svg`.

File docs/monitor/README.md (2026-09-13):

# HAMTYSAN 10.1″ HCIK101V.CC

[Amazon B0B9M5SCG4](https://www.amazon.com/dp/B0B9M5SCG4) — 10.1″ IPS capacitive, **1024×600**, HDMI + micro-USB (5 V / 2 A, touch). No rear case. Four backside holes. OpenSCAD ghost: [`openscad/monitor/`](../../openscad/monitor/WATCH_ME.scad).

HAMTYSAN does not publish a STEP. The numbers below are the OEM outline plus the same 1024×600 glass / HDMI+CTP family.

## Published (this unit)

| | |
|---|---|
| P/N | HCIK101V.CC (Heng Cheng / WETECH / HAMTYSAN) |
| Outline | **235 × 143 × 7.3 mm** (UK listing 235×143×7; Heng Cheng CTP stack **10.4**) |
| Active area | **222.72 × 125.28 mm** |
| Pixel pitch | 0.2175 × 0.2088 mm |
| Brightness | 200–250 cd/m² (OEM vs listing) |
| Contrast | 800:1 |
| Touch | 5-point capacitive, USB HID, driver-free |
| Input | HDMI (accepts up to 1920×1080, panel is 1024×600) |
| DDC/CI | Yes — VCP 0x10 backlight on HDMI-A-2 (`/dev/i2c-21`). This scaler’s scale is inverted; SET **Screen** maps 100% to brightest. No `/sys/class/backlight`. |
| Power | 5 V × 2 A on the micro-USB |
| Weight | ~770 g boxed (Ubuy) |

Thingiverse case for this ASIN measured the **board + jacks at 20 mm** deep and the glass about **235 × 145**. Use 20 mm behind the glass until you caliper yours.

## Drawings in this folder

| File | What it is |
|---|---|
| [waveshare-10.1-panel.pdf](waveshare-10.1-panel.pdf) | Waveshare 10.1″ 1024×600 **glass** (235×143×5.10, AA 222.72×125.28, side M2 holes). Same outline family, **not** the HDMI board. |
| [AM-1024600-101E.pdf](AM-1024600-101E.pdf) | Amson 10.1″ 1024×600 LVDS module, same AA / outline. Page 16 is the outline. |
| [MDT1010AC-HDMI.pdf](MDT1010AC-HDMI.pdf) | Midas **HDMI + capacitive** sibling, 235×143×**14.70**. Page 9 is the only hole drawing in this class (corner locators, ~3.7 / 4.9 mm insets). Jacks and PCB will not match HAMTYSAN exactly. |

Heng Cheng table: [sz-htc product list](https://www.sz-htc.com/products_list/p-120-20.html) (HCIK101V.CC). Same outline on [Himfr](https://www.himfr.com/product-uuetkz-1gyxd6-10-1-inch-hdmi-lcd-displays-1024-600.html).

## Lid mount (Wormfingers case)

The Pi already sits on the 90 mm lid (HAT holes, USB toward −X). The 10.1″ case cannot bolt through that footprint.

[`display_mount.scad`](../../openscad/monitor/display_mount.scad) is a bridge: four feet in the free ±Y strips, 28 mm posts over the Pi, top plate with **AMPS 38×30.5** (the car-arm pattern Wormfingers built around) and a **48 mm square** (clone case-back spacing). Notch on −X for HDMI / micro-USB down to the Pi.

Lid gets four **12 mm bosses** (not through-holes — chamber stays dark). Drop an M3 nut in each boss. `display_mount` bolts down with 4× M3×10. Print the [Wormfingers enclosure](https://www.printables.com/model/1041827-hamtysan-101-touchscreen-enclosure) (4× M3×25 sandwich) and bolt its back / wall plate to the AMPS or 48 mm holes. Measure before you commit — their wall mount is a slide; the 3MF lets you resize holes.

Print `lid` outer-face up. Print `display_mount` feet down. `./export_stls.sh --hybrid lid display_mount`

Customizer: `SHOW_MONITOR=1` on the hybrid watch file.

## Printed cases (measure first)

Hole pitch **varies by batch**. Printables says so on the driver-board box.

- [Wormfingers enclosure](https://www.printables.com/model/1041827-hamtysan-101-touchscreen-enclosure) — **this is the case the lid mount is built for**, 4× M3×25 + nuts
- [prusader3D HDMI board box](https://www.printables.com/model/1118987-hdmi-driver-board-enclosure-for-wetech-hcik101vcc) — WETECH HCIK101V.CC PCB only
- [scottneumann Thingiverse #6621767](https://www.thingiverse.com/thing:6621767) — OpenSCAD case, 235×145×20

## What to caliper when it arrives

1. Glass W×H×T (expect 235×143×7–10).
2. Four hole centers (and whether they are M2 side-bezel or M3 through the back).
3. Driver-board outline and which edge HDMI / micro-USB sit on.
4. Max depth including the HDMI plug.

`openscad/monitor/params.scad` `HOLE_INSET_*` is a 5 mm placeholder until those numbers exist.

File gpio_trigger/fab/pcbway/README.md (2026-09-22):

# gpio_trigger — PCBWay upload

Upload **gpio_trigger-pcbway.zip**. It contains the Gerbers and the Excellon drill file.

| Setting | Value |
|---|---|
| Layers | 2 |
| Thickness | 1.6 mm |
| Material | FR-4 |
| Copper | 1 oz |
| Surface | Lead-free HASL |
| Mask | Green |
| Silk | White |
| Outline | Edge_Cuts.gm1, 65.2 × 55.45 mm rectangle |

Both 3.5 mm jacks are on the pin-1 end of the 40-pin socket. Solder that socket on the bottom so the board plugs onto the Pi, square pad to pin 1. That end of the header is the end away from the Pi Ethernet jack.

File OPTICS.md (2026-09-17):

# Optical path budget — Nikon Dual T

## Register math

| Segment | Symbol | Default (mm) |
|---|---|---|
| Helicoid/lens register → knife edge | `D_LENS_TO_KNIFE` | 55 |
| Knife edge → camera F-mount face | `D_KNIFE_TO_MOUNT` | 72 |
| Fold subtotal | `PATH_FOLD` | 127 |
| Inside each D7000 (mount → sensor) | `FLANGE_F` | **46.5** (fixed) |
| **Total flange → sensor** | `PATH_TOTAL` | **173.5** |

The taking lens must form infinity at **`PATH_TOTAL`**, not at 46.5 mm. That is why the stem is an **M42/M39 focusing helicoid + enlarger/LF lens**, not an F-Nikkor.

Edit distances in [`openscad/params.scad`](openscad/params.scad). Keep **L and R arms identical** except for shim stacks.

## Field split (panorama)

- One-piece **V cartridge** joins at the **middle** (knife at origin); arms run toward the blank **back wall** (+Y).
- Coatings face **out from the V**. Cartridge stays inside the chamber; floor pockets locate it; lid forks slot over two posts (`SHOW_LID=1`).
- Right blade → +X camera; left blade → −X camera.
- **Stitch overlap** (`OVERLAP_FRAC`, default **0.20**): arm cookies stay **flat** on the cube faces; each tube is toed toward the lens by `arm_toe()` so the camera looks across the knife. Each glass is shifted inward by `overlap_cross()/2` so there is coating on that line of sight. That is ~4.7 mm / ~1000 px on a D7000. A hard V still cannot put the *same* full-brightness rays on both sensors — the extra strip is the crossed-glass + pupil-split seam, not a 50/50 cube. Stitch is **1.6×** one DX (~37.8 mm / 12.4°). Countryside: [`docs/kraken/el135_v_scene.png`](docs/kraken/el135_v_scene.png) · vs hybrid: [`docs/kraken/el135_v_hybrid.png`](docs/kraken/el135_v_hybrid.png). Tune `OVERLAP_FRAC` in [`openscad/params.scad`](openscad/params.scad).

## Equal-path rule

L and R geometric paths must match within **~0.1 mm**. Use printed shim rings (`SHIM_STEPS`) between arm tube and F-mount until both live-views are sharp on a **distant** chart without refocusing the helicoid between bodies.

## Alignment procedure

1. Flock or matte-black the chamber interior; install FSM glass coating-side toward the light.
2. Mount both D7000s; MC-DC2 Y-remote for sync.
3. Helicoid → infinity on a distant target using **one** body.
4. If the other body is soft, add/remove shims on that arm only; recheck.
5. Tip/tilt set-screws on mirror trays until the seam is centered and vertical.
6. Shoot overlap chart; stitch; note vignetting — stop down or swap to larger-circle lens if needed.

## Why not a 50/50 plate beamsplitter

The panorama T uses a **hard V** because it splits the *field*. Each camera gets a different half of the taking lens’s image (plus a crossed-seam overlap) so you can stitch a wider frame. A [50×50 mm 50R/50T plate](https://www.edmundoptics.com/p/50-x-50mm-50r50t-plate-beamsplitter/4985/) (Edmund #43-359) splits *amplitude*: both bodies see the **same** full frame at ~half the light. That is a different camera — dual-ISO / dual-exposure / redundant record — not a panorama.

Other reasons the V stayed:

- One 45° plate reflects to **+X** and transmits to **+Y**. It cannot feed two opposite (±X) cameras without a second fold.
- Each body loses a stop. The V does not.
- Transmit goes through 1 mm float at 45° (~0.3 mm extra OPL). The two arms are no longer the same length.
- #43-359 is **uncoated on S2** — ghosts. The matching AR-backed 50×50 is TECHSPEC [**#45-854**](https://www.edmundoptics.com/p/50-x-50mm-50r50t-vis-plate-beamsplitter/6281/) (~$263, S2 Ravg ≤1% 400–700 nm) but it is **3 mm** thick, so it does not fit the 1 mm tray. Dielectric 50/50 at 45° is also not 50/50 for both polarizations.

The amplitude-split fork is [`openscad/bsplit/`](openscad/bsplit/WATCH_ME.scad): lens −Y, reflect +X, transmit +Y. The T tube is shortened by `bs_t_comp()`. Open that file, not `WATCH_ME.scad`. Export with `./export_stls.sh --bsplit`.

## Hybrid (pano L: toed DX + one 50/50 plate)

A knife in the converging beam splits the **pupil**, not the picture — both bodies still see one DX frame. The panorama is each camera looking at a **different half** of a wider taking-lens image.

`sensor_shift() = SENSOR_W/2 × (1 − OVERLAP_FRAC)` ≈ **9.4 mm**. Each arm is toed by `field_toe()` so its DX window is that offset. Stitch width is `SENSOR_W × (2 − OVERLAP_FRAC)` ≈ **42.5 mm / 1.8×** one frame. The taking lens must cover that (~45 mm diagonal).

One uncut 50×50 plate at the origin (same seat as bsplit): reflect → +X, transmit → +Y. Both unique halves are ~1 stop down.

Taking lens: **EL-Nikkor 135 mm f/5.6** (L39, 4×5 coverage, ~$80–150 used). On `PATH_TOTAL=173.5` it focuses at **~608 mm** (m≈0.29). Stitch is ~149 mm of object / 42.5 mm on the sensors (~1.7× one DX). The 50/2.8 you have is close-up only (~73 mm). Infinity on this chassis is an **EL-Nikkor / Componon / Rodagon 180** (helicoid out ~6.5 mm; **+7.2 mm** at 50 m so path is **180.7 mm**). The 135 cannot get there — the 90 mm box plus the D7000 register already exceed 135 mm. 180 at 50 m is the same ~13.4° stitch on **~12 m** of object. See [`docs/kraken/el135_frames.png`](docs/kraken/el135_frames.png), [`docs/kraken/el135_pano.png`](docs/kraken/el135_pano.png), [`docs/kraken/el180_frames.png`](docs/kraken/el180_frames.png), and [`docs/kraken/el180_scene.png`](docs/kraken/el180_scene.png).

Open [`openscad/hybrid/WATCH_ME.scad`](openscad/hybrid/WATCH_ME.scad). Verify with [`kraken/hybrid_paths.py`](kraken/hybrid_paths.py) (`ratio` must be ≥ 1.6). Export with `./export_stls.sh --hybrid`.

## Hybrid shift (pano L: shifted DX, no tube toe)

Toeing each tube by `field_toe` (~4.6°) tilts the sensors relative to the taking-lens image plane. Image-side sag to the DX edge is ~0.9 mm vs ~0.22 mm depth of focus at f/5.6 — Scheimpflug. This fork keeps `field_toe() = 0` and **translates** the R/T bores by `sensor_shift()` (~9.4 mm) so each tube stays centered on its chip. Cookies and M3s stay on the 90 mm face centers. Same 42.5 mm stitch, same 50/50 plate, same `PATH_TOTAL`. Inner 1.6 mm of box/tube/lid walls export as `*_inner.stl` for PETG; `*_outer.stl` is the PCTG shell.

Open [`openscad/hybrid_shift/WATCH_ME.scad`](openscad/hybrid_shift/WATCH_ME.scad). Export with `./export_stls.sh --hybrid-shift`.

## Hybrid shadowgraph (same-image DX + one 50/50 plate)

Same L and plate, but `field_toe() = 0`: both bodies see the same DX frame. T is the conjugate tube (`▲ T shadowgraph`). R is the longer razor-slot tube — 0.6 mm extra (~7.4 mm object-side defocus), `▲ R shadowgraph`. Not a stitch. Bright card at ~0.61 m. Export with `./export_stls.sh --shadowgraph`. Setup, what works, and the Kraken plates: [README — Shadowgraph](README.md#shadowgraph).

## EF hybrid (pano L: toed 5D Mark III + one 50/50 plate)

Same L and the same uncut 50×50 plate. Bodies are Canon **5D Mark III** (36×24 mm, EF, **44.0 mm** register). `sensor_shift()` ≈ **14.4 mm**, stitch ≈ **64.8 mm / 1.8×** one FF frame. `PATH_TOTAL` ≈ **171 mm**. Tube mouth is **58×0.75** for an EF reversing ring, or `ARM_MOUNT=1` for a printed male EF. Open [`openscad/EFhybrid/WATCH_ME.scad`](openscad/EFhybrid/WATCH_ME.scad). Export with `./export_stls.sh --efhybrid`. Countryside compare: [`docs/kraken/el135_d7000_5d3.png`](docs/kraken/el135_d7000_5d3.png) (D7000 stitch ~14° / 8.9k px vs 5D Mk III ~21.5° / 10.4k px).

## E hybrid (pano L: toed α7 + one 50/50 plate)

Same L, Sony **α7** (35.8×23.9 mm, E, **18.0 mm** register). `PATH_TOTAL` ≈ **145 mm**, so the 135/5.6 focuses at **~2 m** (not 0.61 m). Stitch ≈ **64.4 mm / 1.8×** one FF frame, ~**25°**. Open [`openscad/Ehybrid/WATCH_ME.scad`](openscad/Ehybrid/WATCH_ME.scad). Export with `./export_stls.sh --ehybrid`. Countryside: [`docs/kraken/el135_d7000_a7.png`](docs/kraken/el135_d7000_a7.png).

## What will not work

- Native F-mount Nikkor on the stem for infinity (path already spent 46.5 mm inside each body). The F 50 kit is a 1.6 mm `stem_f50` cookie that *is* the female-F back (no 3 mm stack) plus 54 mm / 2 mm-cookie camera tubes (`arm_*_s`). A 50/1.8 is still close-up (~75 mm, ~1.9×). Do not put those tubes on the 135 / 180.
- El-Nikkor **50 mm** f/2.8 on this path (close-up only). Print `elnikkor_adapter` (L39×26 TPI) and use the **135 mm f/5.6** for a ~0.6 m subject. Infinity needs path ≈ f: that is a **180 mm** enlarger lens on this box (see [bom.md](bom.md)), not a shorter 135 stem.
- Second-surface (household) mirrors — ghost images.
- Fixed mirrors with no shims — one side will miss focus (see Hackaday A7 T-rig).

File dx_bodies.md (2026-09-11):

# DX bodies for this build

Drop-in **F-mount DX** only — same 46.5 mm register, same ~23.5×15.6 mm window, so the printed arms / toe / Kraken stitch still match. The taking-lens iris stays on the enlarger; AF and the OVF do not matter. What does: **pixels on the stitch**, **no AA filter**, **high ISO** (hybrid 50/50 is −1 stop), **MC-DC2** (keep the Y-lead), **USB PTP** for `cam/web.py` live view, and a screen you can still see when the body is on +X / +Y.

Nikon DX **never went past 24.2 MP**. The ceiling is the 2013 D7100/D7200 / D5300-family chip (6000×4000). After that Nikon *dropped* to **20.9 MP** (D500, D7500, every Z DX including Z50 II) for readout and high ISO. The 26 / 32 / 40 MP APS-C numbers are Canon, Sony, and Fuji — not Nikon. A Z7/Z8 DX *crop* is ~19 MP off a 45.7 MP FX sensor, not a native DX body.

Prices are **2026 US used-body guesses** (private sale / mid KEH), not mint-boxed. Buy two that match (same model, similar shutter count).

## F-mount, cheapest first

| Body | Used $ | Pair ×2 | Sensor | Pitch | AA | Native ISO | Remote | Why it is better here |
|---|---|---|---|---|----|---|---|---|
| **D5200** | $150 | **$300** | 24.1 MP · 6000×4000 | 3.9 µm | yes | 100–6400 | MC-DC2 | +49% pixels vs D7000; flip screen for chassis LV. Same ISO ceiling, worse build. |
| **D7000** | $180 | **$360** | 16.2 MP · 4928×3264 | 4.8 µm | yes | 100–6400 | MC-DC2 | What you have. Dual SD, weather, gphoto2. The stitch is ~8.9k px wide. |
| **D5300** | $190 | **$380** | 24.2 MP · 6000×4000 | 3.9 µm | **no** | 100–12800 | MC-DC2 | First cheap **no-AA** 24 MP. Enlarger glass can use the extra acuity. Flip screen. |
| **D5500** | $240 | **$480** | 24.2 MP · 6000×4000 | 3.9 µm | **no** | 100–25600 | MC-DC2 | Same 24 MP / no AA, touch flip screen, lighter. |
| **D7100** | $270 | **$540** | 24.1 MP · 6000×4000 | 3.9 µm | **no** | 100–6400 | MC-DC2 | D7000-shaped: weather, dual SD, grip. 24 MP no AA. Best “same chassis feel” upgrade. |
| **D5600** | $280 | **$560** | 24.2 MP · 6000×4000 | 3.9 µm | **no** | 100–25600 | MC-DC2 | Same sensor family as D5500. SnapBridge is unused here. |
| **D7200** | $400 | **$800** | 24.2 MP · 6000×4000 | 3.9 µm | **no** | 100–25600 | MC-DC2 | 24 MP no AA **and** two extra ISO stops vs D7000. Dual SD. The value pick if the pair budget is ~$800. |
| **D7500** | $550 | **$1,100** | 20.9 MP · 5568×3712 | 4.2 µm | yes | 100–51200 | MC-DC2 | D500 sensor: fewer pixels than a D7200, much cleaner at the ISO the 50/50 forces. USB 3, 4K, tilt. One SD slot. |
| **D500** | $800 | **$1,600** | 20.9 MP · 5568×3712 | 4.2 µm | yes | 100–51200 | **10-pin** | Same 20.9 MP / high-ISO win. Pro body, USB 3. **New remote** (not MC-DC2). Bigger / heavier on the arms. |

Skip **D3xxx** (D3300–D3500): 24 MP, but no MC-DC2 — the Y-lead you already have will not fire them. Skip **D300 / D300S / D90**: fewer pixels than the D7000.

## What the extra resolution does

Hybrid stitch width is `SENSOR_W × (2 − OVERLAP_FRAC)` ≈ **42.5 mm** at the default 0.20 overlap ([`openscad/hybrid/params.scad`](openscad/hybrid/params.scad)).

| Body | Stitch px (wide) | vs D7000 |
|---|---|---|
| D7000 16.2 MP | ~8.9k | — |
| D7500 / D500 20.9 MP | ~10.1k | +13% |
| D5300–D7200 24.2 MP | ~10.8k | +22% |

The 135/5.6 circle already covers that 42.5 mm. 24 MP no-AA is the resolution upgrade; D7500/D500 is the **light-starved** upgrade (hybrid plate). On the hard-V pano both sensors get full brightness, so 24 MP wins.

Field is the same DX window. Compare native photosites on that stitch: [`docs/kraken/el135_d7200.png`](docs/kraken/el135_d7200.png).

## Same path, not the same plug: Z DX + FTZ

FTZ keeps F-register **46.5 mm**, so the optical path does not change. The stack hangs farther behind each arm. Sensor is the 20.9 MP D500 chip (not 24 MP). Live view is native (no mirror). Need **two FTZ** (~$150–200 used each) on top of the pair.

| Body | Used $ | Pair ×2 | + 2× FTZ | Sensor | Why |
|---|---|---|---|---|-----|
| **Z30** | $400 | **$800** | ~$1,100 | 20.9 MP · 5568×3712 | Cheap Z DX, no EVF, USB-C. Fine as a pair of rear screens. |
| **Z50** | $550 | **$1,100** | ~$1,400 | 20.9 MP | EVF + better LV than any F-mount PTP preview. |
| **Zfc** | $650 | **$1,300** | ~$1,600 | 20.9 MP | Same chip, worse grip on a box. |
| **Z50 II** | $850 | **$1,700** | ~$2,000 | 20.9 MP | EXPEED 7, USB-C, best tether of the DX Zs. Still 20.9 MP. |

## Practical pick

- **Cheap stitch upgrade:** two **D5300** (~$380). 24 MP, no AA, flip screen, MC-DC2.
- **Same-body-as-now upgrade:** two **D7100** (~$540) or two **D7200** (~$800) if you want the ISO as well.
- **Hybrid 50/50:** two **D7500** (~$1,100) — spend the money on high ISO, not megapixels.
- Keep the D7000s until the chassis is proven. The mount does not care.

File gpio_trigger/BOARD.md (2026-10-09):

# Board assembly

## Files

| File | Purpose |
|---|---|
| [schematic.svg](schematic.svg) | Full electrical schematic |
| [layout-perf.svg](layout-perf.svg) | Perfboard + Hammond 1591TBK placement |
| [layout-pcb.svg](layout-pcb.svg) | PCB: both jacks on the pin-1 end, socket on the bottom |
| [netlist.csv](netlist.csv) | Connection list for wiring / KiCad |
| [kicad/](kicad/) | KiCad schematic + placed footprints |

Regenerate everything: `python3 gen_cad.py`

## PCB

The built trigger board. Blue is focus, red is shutter, one pair for each body. USB release does not need it.

The board is optional. USB release on the phone fires both bodies and downloads the frames. This board is the 10-pin path, when both shutters should open from the remotes.

The KiCad board is routed and stays inside the Raspberry Pi 4 outline. Both TRS jacks face out the **pin-1** end, away from Ethernet, with the plug mouth at that edge so a chassis wall can meet them. The right edge stops short of the USB and Ethernet jacks. Four 2.7 mm holes (H1–H4) match the Pi’s M2.5 standoffs. Solder the 2×20 female socket on the **bottom**. Pin 1 (square pad) meets Pi pin 1. Gerbers are in `fab/pcbway/`.

JP1 (focus) and JP2 (shutter) ship with pads 1–2 bridged, so both cameras follow pin 38 and pin 40. To drive camera B on its own pins, cut that bridge and solder pad 2 to pad 3. J1 stays on pin 38 / pin 40.

## Perfboard build (alternate)

1. **Board:** 50×70 mm veroboard, 2.54 mm pitch ([BOM](bom.md)).
2. **Enclosure:** drill one **6 mm** hole on each side wall — **J1** plug exits the right side, **J2** the left side (see `layout-perf.svg`).
3. **Mount** perfboard on standoffs; jacks on panel, wired to board edge.
4. **Orientation:** Input (resistors + LED side of 4N35) faces **left** toward Pi harness; output (transistor side) faces **right** toward jacks.
5. **Solder order:** jacks and 4N35 sockets first, resistors, then bus wires (focus, shutter, GND).

## 4N35 orientation

```
      ┌─────────┐
  1 ──┤ ●     ● ├── 6  (collector, tie to 5 or use 5 only)
  2 ──┤       ● ├── 5  → ring or tip
  3 ──┤       ● ├── 4  → sleeve (per jack)
      └─────────┘
   cathode ↑ anode
```

Pin 1 faces **left** (toward resistors) on the layout drawing.

## Pi connection

The PCB uses a **2×20 female socket** and plugs onto the Pi's 40-pin GPIO header.

| Pi physical pin | BCM | Net |
|---|-----|-----|
| 35 | 19 | J2 shutter, only if JP2 pad 2–3 is bridged |
| 37 | 26 | J2 focus, only if JP1 pad 2–3 is bridged |
| 38 | 20 | FOCUS (J1, and J2 while JP1 pads 1–2 are bridged) |
| 39 | — | GND (opto LED cathodes and optional indicator LEDs only) |
| 40 | 21 | SHUTTER (J1, and J2 while JP2 pads 1–2 are bridged) |

Pin 1 of the socket is the square pad and must meet pin 1 on the Pi.

## Optional trigger LEDs

Four 5 mm LEDs, each with its own 330 Ω, on the **Pi side** of the optos. **D1** / **R5** is camera 1 focus (pin 38). **D2** / **R6** is camera 1 shutter (pin 40). **D3** / **R7** is camera 2 focus and **D4** / **R8** is camera 2 shutter: they follow pin 38/40 while the jumpers are bridged, and pin 37/35 after you cut and bridge 2–3. Marked DNP in the schematic. Leave an LED and its resistor off together to omit that lamp. Do not put these LEDs on the camera side of the 4N35.

## Test

```bash
python3 gpio_seq.py --hold-focus   # meter: ring→sleeve on both jacks
python3 gpio_seq.py                # full sequence
```

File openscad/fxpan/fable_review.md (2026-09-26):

# FXPAN 65 — design review (Fable, 2026-09-26)

Configuration reviewed: **two D800 on printed F-mount tubes** (`arm_r_fw` /
`arm_t_fw`, `ARM_MOUNT = 1`) behind the **Nikkor-W 180 mm f/5.6 in Copal 1**
on the M62 helicoid (`STEM = 2`: `stem_w` + `stem_nw180`), chassis at
`5281288`. Printer: Bambu Lab H2C, 0.4 mm nozzle, PETG (or ASA/ABS; the H2C
chamber heats to 65 °C so either is fine).

Everything below was checked against the code, not the README. The numbers
come from `WATCH_ME.scad`'s own functions, evaluated with OpenSCAD
2026.06.12 (`-D ARM_MOUNT=1 -D STEM=2`), plus a few things the diagnostics
do not currently print. Where I estimate a camera dimension I say so; the
D800 mesh in the preview is known to be rough and I did not trust it.

Contents

1. Verdict
2. Numbers as built
3. Blocking issues (fix before printing a chassis)
4. Functional improvements
5. Printability on the H2C at 0.4 mm
6. Nice to have
7. Measure-first checklist
8. Documentation drift
9. How to verify each fix

---

## 1. Verdict

**The optics and the path are self-consistent for the Nikkor-W build.**
The lens flange lands at 178.8 mm from the sensor with the helicoid at
17.5 mm, the T leg is shortened for the glass, the plate has 50 % margin
across the fold at f/11, and the tube bore is never the limit. The chassis,
tray, lid, base and cookies are a coherent, printable set of parts. As a
proof of concept it will form two images that stitch.

**It will not deliver the advertised f/8–f/11, 65 MP result with printed
F-mount tubes**, and there are three mechanical problems that will stop the
first build regardless of mount:

| # | Issue | Severity |
| --- | --- | --- |
| A | Printed F mouth is 40 mm; the frame corners are only clean from **f/30** | blocks the optical goal |
| B | Camera R's grip almost certainly hits camera T's front corner (both bodies upright) | blocks assembly |
| C | Base camera pads are 8 mm off for the W arms; the 1/4-20 sits at the end of its slot | blocks assembly |
| D | Nikkor-W infinity has 0.5 mm of helicoid margin and the nose leaves 2 mm of thread for the Copal ring | likely no infinity |

A and B are the ones to think about before anything else. A is a limit of
putting a 14.4 mm shifted full-frame bundle through a printed F barrel —
the fix is a different mouth. B is a property of two upright D800 bodies at
90° with registers 71.5 mm from the fold; the fix is buying separation with
the Nikkor-W's extra 20.3 mm of path, which the current W design spends on
a helicoid stack instead.

---

## 2. Numbers as built (`ARM_MOUNT=1`, `STEM=2`)

```
BOX_XY 92, BOX_Z 83, outer 100 × 100 × 103.5, plinth 20.5
ARM_TUBE 8, W_ARM_EXTRA 8, F_FMOUNT_STACK 3
reflect_tube_len 21.0, transmit_tube_len 20.697 (T shorter by bs_t_comp 0.303)
register from plate: d_plate_to_mount + arm_extra = 63.5 + 8 = 71.5
sensor from plate: 71.5 + 46.5 = 118.0
Nikkor-W flange: nw_flange_z 14.8 (stem frame) → plate→flange 60.8
PATH = 60.8 + 118.0 = 178.8 = NW_FFD          ✓ infinity at helicoid 17.5 of 17–31
nose rise (helicoid front → Copal flange) 3.3 mm, NW_BOARD 3.0
standoff skin→register: 21.5 mm with W arms (13.5 mm without)
base_cam_d 107.5  vs  register 71.5 + D800_TRIPOD_IN 44 = 115.5   ✗ 8 mm short
mouth: printed F lip 40 mm → corner-to-corner clean from f/30.3
need_bore at the flange: f/8 44.28, f/11 42.69, f/16 41.37, f/22 40.58, f/∞ 38.47
floor honeycomb: cells z −60 … −35.1, chamber floor −35.5 (cells open into the chamber under the tray)
logo cookie: −X skin, z −53.8 … 41.5 (95.3 × 100 × 4 mm), 4× M3 CSK
```

The diagnostics echo **does not know about `STEM=2` or the W arms**: it
reports the EL-Nikkor path (158.5) and the non-W standoff (13.5 mm, 0.5 mm
to twist the body on). See §4.6.

---

## 3. Blocking issues

### 3.A — The printed F mouth vignettes the frame corners until f/30

`mouth_clear()` returns `F_STL_THROAT = 40` for `printed_f()`. The corner
of a 36 × 23.9 frame shifted 14.4 mm needs, at the flange,

```
need_bore(N, 46.5) = 38.47 + 46.5 / N      (mm; from params.scad need_bore())
```

so the aperture at which a given mouth passes the whole frame is
`N = 46.5 / (D − 38.47)`:

| mouth clear D | corners clean from | note |
| --- | --- | --- |
| 40.0 (Archive-663 lip as shipped, `F_STL_THROAT`) | **f/30** | what `arm_*_fw` prints today |
| 41.0 | f/18 | 1.25 mm barrel wall left if the barrel OD is 43.5 |
| 41.5 | f/15 | 1.0 mm wall |
| 42.0 | f/13 | probably what a real metal reverse ring measures |
| 43.5 | f/9.2 | what README/PLAN claim for the printed mouth; not what the code does |
| 44.0 (`F_THROAT`, camera-side throat) | f/8.4 | no lens-side part can be this — it has to have a wall |

Rough corner illumination with the 40 mm lip (circular-cap estimate, extreme
corner only): ~0.67 at f/8, ~0.73 at f/11, ~0.82 at f/16, ~0.92 at f/22.
That is hard mechanical vignetting with a steep edge, not the gentle
cos⁴ roll-off a flat-field correction handles gracefully.

At the apertures where the 40 mm lip is clean, diffraction on a 4.88 µm
pixel has already taken the 65 MP away: Airy diameter 2.2 px at f/8,
3.0 px at f/11, 4.4 px at f/16, 6 px at f/22.

**Fix options, in order of preference**

1. **Use the metal reverse rings (`ARM_MOUNT = 0`) and caliper their clear
   aperture.** Put the measured value into `F_THROAT` (it is currently
   assumed equal to the camera throat, 44.0, which is not physically
   possible for a lens-side part). Expect ~42 → f/13. This is the
   configuration the whole body was designed around.
2. **If printed F is a must:** re-bore the Archive-663 lip. In
   `fxp_f_mount.scad`, `f_mount_stl_raw()` is imported whole; add a
   `difference()` with a cylinder of `F_STL_THROAT_BORED` (41.0–41.5) over
   the lip's height only. Keep ≥1.0 mm of wall under the bayonet barrel
   (the comment in that file says the barrel is 43.5; verify by measuring
   the mesh, not by reading the comment). Set `F_STL_THROAT` to the bored
   value so `mouth_fstop()` tells the truth. This is an f/15–f/18 body.
3. **Longer term:** replace the mesh with a parametric F bayonet whose
   barrel is 43.8 OD / 42.0 ID with no lip. Then printed and metal mouths
   are equivalent (~f/13).

Also: with an integral printed bayonet there is **no shim interface**. The
`shims` part only works between the arm mouth and a reverse ring. If the
two printed legs disagree in register by 0.2 mm (easy at 0.16 mm layers),
the only fix is a reprint. Add `ARM_TRIM_R` / `ARM_TRIM_T` customizer
numbers that add to `reflect_tube_len()` / `transmit_tube_len()` so a
0.2 mm correction is one parameter, not a redesign.

### 3.B — Camera R's grip collides with camera T's front-left corner

Both bodies are upright (`body_roll_r = 90`, `body_roll_t = 180`, both
landscape, horizontal seam). R sits on +X facing −X; its right-hand grip is
therefore on **+Y**, toward camera T. T sits on +Y facing −Y; its grip is on
−X, away from R. The shift senses are forced by the fold (`cam_axis`: R
shifted −Y, T shifted +X), so R's axis is at world Y = −14.4 and T's front
panel is at world Y = 71.5 − (front-panel proud).

The ghost box in the model (`ghost_body_at`) is a symmetric 146 mm cube
centred on the tube axis; the two ghosts touch exactly at Y = 58.5/58.6.
The D800 is not symmetric about its mount. **Estimate** (measure this):
axis → non-grip edge ≈ 60 mm, axis → grip edge ≈ 86 mm, grip protrudes
≈ 15–20 mm past the flange, non-grip front panel ≈ 8–13 mm past it.

```
R grip edge, world Y:   −14.4 + 86  = 71.6
T front-left corner, Y:  71.5 − 13  = 58.5   (71.5 − 8 = 63.5 if the non-grip panel is shallower)
                                     → 8–13 mm of interference
R grip front, world X:   71.5 − 20  = 51.5
T non-grip edge, X:      14.4 + 60  = 74.4   → the overlap is real in X as well
```

Collision iff (axis → grip edge) > 72.9 mm with `D800_PROUD = 13`. Any
D800 I know of exceeds that. The EL-Nikkor build is worse (register at
63.5, T front at ~50.5).

Things that do **not** fix it: swapping shift senses (R would shift toward
T), rolling R upside down (the cradle holds the body by its tripod socket),
shrinking `BOX_XY` (path-locked).

**Fix:** move T's front panel past R's grip edge. T's front moves 1:1 with
the register distance; R's grip edge does not move. You need the register
at ≈ 71.5 + (71.6 − 58.5) ≈ **85 mm from the plate**, i.e. about 13 mm
more standoff on both legs. The Nikkor-W has exactly 20.3 mm more flange
focal distance than the EL-Nikkor, and the current W design spends 12.3 of
it on the lens side (helicoid + 3.3 mm nose) and 8 on the arms. Spend it
the other way round:

- `W_ARM_EXTRA` → 18–20 (params.scad line ~185). Standoff becomes
  31.5–33.5 mm, T's front lands at 76.5–78.5 mm, clear of a 71.6 mm grip
  edge by 5–7 mm.
- The lens side then has 0.3–2.3 mm left, which does not fit a 17 mm
  helicoid. Two ways out:
  - **Fixed-infinity W nose**: an M62 male screwed straight into `stem_w`
    (thread −6 … 2), board face at `flange_z(NW_FFD) − W_ARM_EXTRA`, no
    helicoid. Focus with the **camera helicoid arms** (`arm_r_hw` /
    `arm_t_hw`, M52 female / M42 male 17–31 units); they put the register
    at the same station (`cam_heli_register_z`) so they cost no path. This
    also gives each leg independent focus, which you want anyway (§4.1).
  - Or keep the lens helicoid and take `W_ARM_EXTRA` as high as the nose
    allows (≈ 12 with a 2 mm board and infinity at helicoid 17.5). That
    buys 4 mm, not 13; it only works if the measured grip edge comes in
    under ~77 mm. Measure before choosing.
- Add a **real asymmetric ghost**: replace the cube in `ghost_body_at()`
  with two boxes (grip block and body block) parameterised by
  `D800_GRIP_HALF`, `D800_BODY_HALF`, `D800_GRIP_PROUD`, `D800_PANEL_PROUD`,
  rolled the same way as the real body, and echo the R-grip-vs-T-front gap
  in `diagnostics()`. Do not use `d800_body.stl` for this.

Also check the 10-pin remote and PC-sync terminals: they are on the **front,
non-grip side** of the D800 (~40 mm from the axis). For both cameras that
lands ~4 mm outside the chassis face edge with the plug body straddling the
R9 corner. Use a right-angle or slim 10-pin plug, or verify with the plug in
hand before printing.

### 3.C — Base pads ignore `W_ARM_EXTRA`

`base_cam_d()` (WATCH_ME.scad ~1639) is `d_plate_to_mount() +
d800_tripod_in()` = 107.5. With W arms the register is at 71.5, so the
tripod socket wants to be at 115.5. `BASE_SLOT_L = 18` gives ±9 mm, so the
screw sits 1 mm from the end of the slot with no float left — and the slot
exists precisely so the screw follows the bayonet in.

```scad
function base_cam_d() = d_plate_to_mount() + arm_extra() + d800_tripod_in();
```

Also carry `arm_extra()` into `base_r_xy()`/`base_t_xy()` (they read
`base_cam_d()` so they follow), and re-export `base`, `cradle_r`,
`cradle_t` for the W build. Add `arm_extra()` to the tripod-socket centre of
mass too (`base_tripod_xy()` uses the pad positions, so it follows).

### 3.D — Nikkor-W infinity margin and the Copal ring

`heli_at_infinity()` is **17.5 mm** on a 17–31 helicoid: **0.5 mm** past
the collapsed stop (`HELI_SHORT`). That number is the EL-Nikkor path. The
W build inherits it. `nw_flange_z()` subtracts `W_ARM_EXTRA` and the W
arms add the same 8 mm, so the flange stays at 178.8 mm **at that same
17.5 mm mark**. A bought helicoid whose collapsed length is 17.6 mm
cannot reach infinity. Shims only add path.

**Do not drop `W_ARM_EXTRA` to buy margin.** Arms and nose move together:

```
nw_rise() = flange_z(NW_FFD) − W_ARM_EXTRA − (−WALL + heli_at_infinity())
          = 11.3 − W_ARM_EXTRA
```

`W_ARM_EXTRA` 8 → 6 lengthens the nose by 2 mm and shortens the arms by
2 mm. Path stays 178.8 mm. Infinity stays at helicoid 17.5. `NW_BOARD`
does not move the flange either: the Copal face is the far end of
`nw_rise()`, and the board is only how much of that length stays solid.

The nose is the only place left to steal margin, and there is almost
none. Rise is **3.3 mm** with a **3.0 mm** board. Shorten the nose
*without* shortening the arms (break the cancel: keep `W_ARM_EXTRA`,
reduce `nw_rise()` only) and each millimetre moves infinity 1 mm into
the travel. A 2.0 mm board leaves about 1.3 mm to give, so infinity
lands near **18.8 mm**, not 19.5. That also pulls the lens 1.3 mm closer
to the cameras, which is the opposite of §3.B.

The clean margin is the §3.B fixed nose plus the camera helicoids. Then
infinity is a printed length, and each body has 14 mm of travel.

**Copal ring.** The neck behind the flange is 5.1 mm. The M39×0.75
thread is the first **4 mm** of that (`NW_THREAD`). The Ø54 cell starts
at 5.1 mm. Board and ring share that 5.1 mm:

| board | thread left (4 − board) | room for the ring before the Ø54 cell |
| --- | --- | --- |
| 3.0 (now) | **1.0 mm** | 2.1 mm |
| 2.0 | 2.0 mm | 3.1 mm |

A ~2.5 mm ring on a 3 mm board runs into the cell before it clamps, and
it only has 1 mm of thread. Use `NW_BOARD = 2.0` and confirm the real
ring is ≤ 3 mm thick and ≤ `NW_CLEAR` 56 mm across. That change is for
the ring. It does not fix infinity.

**Rear cell and the bought helicoid.** The Ø54 cell reaches 22.3 mm
behind the flange: through the nose, through the helicoid, and **1.5 mm
past the stem inner face** (z = −6) into the chamber. Measure before
printing `stem_w`:

- clear inside diameter ≥ 55 mm, or the cell stops in the helicoid
- body OD ≤ `heli_pass_d()` = 70 mm, or it cannot sit in the recess and
  lands on the skin ~2 mm further out, which deletes infinity

M62 17–31 bodies are often 72–78 mm. `HELI_NUT_OD` / `heli_pass_d()` are
the knobs; the clamp screws cap the pass at about 75 mm.

---

## 4. Functional improvements

### 4.1 Per-leg focus

Two legs, one lens helicoid: the legs have to agree in register to within
the depth of focus (0.3 mm at f/8) with no adjustment other than shims —
and with printed F there is no shim interface (§3.A). The camera helicoid
arms (`arm_*_hw` + `fmount_h_*`) give each leg 14 mm of travel. That
removes the need for the lens helicoid entirely on the W build and lets
§3.B spend the path on body clearance. Recommend making `arm_*_hw` the W
default and documenting `stem_w` + fixed nose as the W stem.

### 4.2 Field stop for the Nikkor-W

The Nikkor-W covers 70° (Ø253 mm image circle at f/22). The chassis passes
it through a Ø74.8 hole into a 92 mm chamber whose walls are 40 mm from the
axis. Everything outside the 65 × 24 field lights up the chamber, the tray
ribs, and the back of the plate, and comes back as veiling flare on both
sensors. The EL-Nikkor has the same problem to a lesser degree (5×7
coverage).

The bundle the sensors actually need at the stem inner face (158 mm from
the sensor with W arms, P ≈ 180):

| f-stop | across the fold (X) | along it (Z) |
| --- | --- | --- |
| 5.6 | 36.1 mm | 31.2 mm |
| 8 | 27.6 mm | 22.6 mm |
| 11 | 22.3 mm | 17.3 mm |

The W's rear cell protrudes 1.5 mm past the stem inner face, so the stop
cannot sit in the stem's Ø61.2 relief. Put it on the **inside face of the
tray's −Y wall** (`fxp_tray.scad`, `chamber_ports()` lens window,
currently a Ø61.2 round): for `STEM = 2` make that window a rounded
rectangle ≈ **41 × 35 mm (X × Z)** in a 1.5 mm plate at Y ≈ −36 (station
≈ 153 mm; bundle there 37 × 31 at f/5.6). Flock it. Keep the round window
for the EL-Nikkor, whose barrel passes through.

### 4.3 Beamsplitter polarization and colour

A 45° plate 50/50 is polarization dependent: Rs and Rp typically differ by
10–20 % for a "50/50 average of s and p" coating. Skylight at 90° from the
sun and water/glass reflections are strongly polarized, so **R and T will
differ in brightness by up to a stop in exactly the places a landscape
panorama has sky** — a scene-dependent seam that no flat-field or gain
fixes. The 7.2 mm overlap gives `cam/pano.py` something to blend across,
but blending hides, it does not remove.

- Pull the s/p curves for Edmund #37201 and put the worst-case split in
  `bom.md`.
- If it is bad, look at Edmund's **non-polarizing** plate beamsplitters
  (they exist in 50 × 50 and larger; check for 50 × 75 × 1 or accept the
  f/11 50 mm fallback already documented).
- Test early: shoot a polarized sky through the finished body and look at
  the seam before flocking anything.

Related: the 50/50 split costs each camera one stop (f/11 marked ≈ T/16 per
sensor), and the ±10 % over 400–700 nm becomes a colour cast difference
between halves. Shoot a grey card once, store per-camera channel gains in
`pano.py`.

### 4.4 The D800 mirror box is not in the ray trace

`kraken/fxpan_paths.py` stops at the flange. Behind it the D800 has a
rectangular mirror-box throat, a mirror at 45°, and the sensor's own
rectangular light shield, all designed for an on-axis pupil. The shifted
bundle enters up to ~11° off-axis at the far corner and its centroid is
displaced ~4 mm toward the shift at the flange plane. Before printing
anything final, mount one D800 on one printed arm and cookie (no chassis
needed, just hold it in front of the lens on a rail) and shoot a flat wall
at f/8 and f/11; look for straight-edged shading on the shifted side.

### 4.5 Light-tightness of the −X wall

The −X wall over the chamber is the 4 mm cookie (`PORT_PATCH_T`). Behind
it `logo_frame_window()` removes the old 6 mm wall: about **76 × 89 mm**
through the nut rail (`win_y` 76, z −50.8 … 38.5), and 79 mm wide from the
chamber floor up. The tray’s −X wall (3.4 mm, outer face 0.4 mm in from
the chamber) is what still stands between that opening and the plate.
This is veiling glare, not a hole onto the glass.

The pockets are the part that glows. `fxpan_inlay` cuts
`MARK_DEPTH + 0.10` = **2.5 mm**, so **1.5 mm** of cookie remains behind
every glyph. `MARK_DEPTH = 2.4` was chosen when this pocket was in a
10 mm wall (“1.2 mm plugs came out as skins”). That wall is gone. Do not
set `MARK_DEPTH` to 1.2 to fix the cookie: the plinth stripe uses the
same number.

Give the cookie its own depth, about **1.0–1.2 mm**, and leave
`MARK_DEPTH` on the stripe. Paint the pockets, or print the colour as the
outer layers of a dark cookie in the slicer. Do not export 1.2 mm
`chassis_logo_*` parts and print them loose — that is the skin-plug
failure the 2.4 mm depth was meant to avoid. White and gold filament
will pipe light through 1.5 mm of “black” PETG; a flashlight on the
finished cookie is the test. Felt on the cookie’s inside face, over the
window, covers the letter backs.

The 0.3 mm cookie-edge gap is not a path into that window. The rebate is
the skin plus 0.35 mm (`at_logo_face_cuts`), and the window is inset
about 3 mm from the cookie’s top and bottom and about 12 mm from each
side. The rim slot is blind. The open route is through the letter
plastic into the cavity, then over the tray: the tray wall and the
window both stop at z = 38.5, so the cavity meets the lid gap. Felt or
a dark cookie closes that. A perimeter gasket does not.

### 4.6 Diagnostics do not cover the W build

`diagnostics()` echoes the EL path, the non-W standoff (13.5 mm, "0.5 mm
to twist it on" — the README says 16/3), and nothing about the nose or the
W infinity margin. Add, gated on `nw_stem()`:

```
NW path: plate→flange (BOX_XY/2 + nw_flange_z()) + plate→mount (d_plate_to_mount() + arm_extra()) + 46.5 = … vs NW_FFD
NW infinity at helicoid heli_at_infinity() of EL180_HELI_MIN..MAX, margin heli_at_infinity() − EL180_HELI_MIN
nose rise nw_rise(), board NW_BOARD, neck left for the Copal ring 5.1 − NW_BOARD
standoff with arm_extra(): patch_t() + mount_standoff() + arm_extra() − skin_z()   vs d800_proud()
base pad vs register: base_cam_d() − (d_plate_to_mount() + arm_extra() + d800_tripod_in())   (must be 0)
R grip edge vs T front (from §3.B ghost parameters)
```

And make `body fit:` use `arm_extra()`.

### 4.7 Non-CPU lens on the D800

The printed F bayonet has no CPU contacts and no AI ridge. Both bodies must
be in **M** (or A with "Non-CPU lens data" set to 180 mm f/5.6). Confirm
the Archive-663 mesh has the lock-pin notch; without it the body can rotate
on the mount and roll alignment walks.

---

## 5. Printability — H2C, 0.4 mm nozzle

General: PETG or ASA, 0.16 mm layers for everything with a thread or a
register (arms, stems, nose), 0.20 mm for chassis/lid/tray/base. Walls
0.42 mm line width, ≥3 perimeters on the arms. Chamber heat on for ASA.

### 5.1 Chassis (`chassis`, floor down, 100 × 100 × 103.5)

- **Three round wall holes need support or a redesign.** The camera pass
  holes are Ø47 (`TUBE_ID + 1`) and the stem hole Ø74.8, printed as
  vertical-wall circles: the crown is a horizontal bridge. On the Ø47 holes
  a 1 mm droop lands **in the optical path** (the arm bore is Ø46, so the
  margin is 0.5 mm). Options: paint supports inside all three holes (they
  are hidden behind cookies), or open the pass holes to `TUBE_ID + 4` —
  the cookies cover them and the rebate is blind — or give them a pointed
  arch top. The tray's Ø46.6 windows have the same crown but the sag is at
  the top (along the fold), where the bundle has 20 mm of margin; harmless
  optically, still worth a support.
- **Honeycomb floor.** `FLOOR_HEX_WALL = 1.0` is two perimeters over a
  25 mm tall web — prints, but set "detect thin walls" on or use 1.2.
  `FLOOR_HEX_SKIN = 2.0` on the bed: at 0.2 mm layers Bambu's default
  3 bottom + 3 top shell layers is 0.6 + 0.6 mm of solid, so the middle
  0.8 mm of that skin is sparse infill under every cell. Set bottom shell
  layers to 10 for the chassis, or raise the skin to 2.4 and set 6/6.
- **Tripod insert wall is ~1 mm.** `floor_hex_cut()` fills cells with
  `norm([x, y]) < TRIPOD_INSERT_D/2 + hx` (8.67 mm). The six neighbouring
  cells sit at 9.0 mm and stay hollow; the closest hex edge is 5.0 mm from
  the axis against a 4.05 mm insert radius, so a heat-set insert goes in
  with ~1 mm of PETG around it (`TRIPOD_KEEP` intended 1.2 *above* it, not
  beside it). Change the test to `norm([x, y]) < TRIPOD_INSERT_D / 2 + hx
  + 2.5` — that fills exactly the centre plus its six neighbours and leaves
  the next ring hollow.
- The honeycomb opens into the chamber floor by 0.4 mm and the tray covers
  it. Fine, but say so in the README; it will surprise whoever slices it.
- Lid nut pockets and port nut traps are fed from the chamber side — good,
  no supports. The blind cookie rebates are 6.85 mm bridges — fine.
- Logo frame gussets are 45° — fine.

### 5.2 Arms with printed F (`arm_r_fw`, `arm_t_fw`)

- `cookie_print_flat()` chamfers one long edge at 45° on the chassis side
  so the part can be laid on that face and printed at 45°, layers running
  diagonally through the plate. That works and needs no support, but the
  README still says "flange on the bed, camera mouth up". Pick one and
  document it. **My recommendation: print flat, cookie down**, because the
  register distance is then a pure Z dimension (±0.05 mm) rather than a
  45° mix; the chamfer becomes a 45° overhang, which prints. Paint supports
  under the Ø62 collar (2 mm × 90° step over the Ø58 tube) and under the
  bayonet tabs.
- The chamfer leaves a knife edge along one side of the outer face; expect
  chipping. Consider stopping the chamfer 0.8 mm short of the outer face.
- Bayonet: 0.12–0.16 mm layers, slow outer wall, no elephant foot
  compensation surprises — the tabs are ~1.5 mm and the lock notch is
  small. Test-fit on a body before printing the second arm.
- The rear peg (`F_PEG_OD 52`, bore 44, 10.5 mm deep) merges into the tube
  wall cleanly.

### 5.3 Stems (`stem_w`, `stem_nw180`)

- `stem_w` has an M62×1 female (−6 … 2) under a Ø70 pocket (2 … 6). Printed
  skin-down that pocket floor is a 4.7 mm-wide horizontal ring overhang
  over the thread. Either print at the intended 45° (`stem_bed_chamfer`
  face on the bed — the code's plan), or print skin-down and support the
  ring, or chamfer the pocket floor 45° from Ø70 to Ø61. Female threads at
  45° print acceptably at `EL180_M62_TOL = 0.45`.
- `stem_nw180`: print **board face down** (Ø72 disc on the bed, M62 male
  up). Thread-down would leave a 5 mm × 90° disc overhang. The Ø41.8 board
  hole narrowing to Ø56 is an upward step, no support.
- M62×1 male: 0.12 mm layers, `tip_height`/lead-in already there.

### 5.4 Logo cookie (`logo_cookie`, 100 × 95 × 4)

Flat, outer face up so the inlays are top surfaces (import
`chassis_logo_*.stl` as parts of the same object in Bambu Studio — they are
generated in the same world frame). Brim; PETG will want to lift a plate
this size. The 45° bottom chamfer is on the bed side — a 45° overhang,
fine.

### 5.5 Fits at 0.4 mm

| feature | value | comment |
| --- | --- | --- |
| `PORT_SCREW_D` 3.2 | M3 clearance | prints ~3.0–3.1; use 3.4 for a true clearance hole |
| `PORT_NUT_AF` 5.7 | M3 nut trap | 5.5 nominal nut, prints tight; 5.8–5.9 |
| `PORT_SLOT_CLEAR` 0.6 | cookie in rebate | fine |
| `TRIPOD_INSERT_D` 8.1 | 1/4-20 heat-set | fine for CNC Kitchen short |
| `EL180_M62_TOL` 0.45 | M62×1 | fine |
| `CAM_HELI_TOL` 0.30 | M42/M52×1 | fine, verify with `cam_helicoid` gauge first |
| `LOGO_FIT` / `LOGO_PROUD` 0.08 / 0.06 | inlay interference | correct, keep |

### 5.6 Print order

1. `ringgauge` only if you go metal ring (recommended).
2. `cam_helicoid` gauge if you go camera helicoids.
3. One `arm_*_fw` (or `_hw`) + one cookie; test-fit a D800 and shoot the
   flat-field test in §4.4.
4. `stem_nw180` / fixed nose; test-fit the Copal ring.
5. Only then chassis, tray, lid, base, cradles.

---

## 6. Nice to have

- **Asymmetric D800 ghost** driven by four measured numbers (§3.B) and a
  collision echo. This is the single most valuable model improvement.
- **`ARM_TRIM_R/T`** register trims (§3.A).
- **Field stop** on the tray for the W (§4.2).
- **Thermal note**: 180 mm of PETG at ~6×10⁻⁵/K moves 0.2 mm over 20 °C —
  about the depth of focus at f/5.6. Camera helicoids make this a
  non-issue; a fixed build should refocus after the body warms.
- **Cable release / shutter**: leave the Copal on T (or B with a locking
  release) and fire both D800s from the 10-pin Y-lead. Note it in the
  README so nobody tries to sync three shutters.
- **Anamorphic**: unchanged; the ISCO hangs off the chassis 1/4-20 not the
  nose, as `bom.md` already says.
- Make `export_fxpan.sh`'s header stop saying "75×75×1" and "F_BORE 43.5".

---

## 7. Measure-first checklist (D800 in hand)

| what | where it goes | why |
| --- | --- | --- |
| axis → grip edge, axis → non-grip edge | new ghost params | §3.B collision |
| grip front and non-grip panel front, both past the flange | `D800_PROUD` → split into two | §3.B; standoff echo |
| lens axis above the baseplate | `D800_AXIS_BASE` | cradle height, both legs on axis |
| axis → tripod socket along the base | `D800_TRIPOD_IN` | base slot centre |
| 10-pin terminal position and plug length | — | corner clearance |
| reverse ring clear aperture (if metal) | `F_THROAT` | §3.A honest f-stop |
| M62 helicoid: collapsed length, body OD, clear ID | `EL180_HELI_MIN`, `HELI_NUT_OD`/`heli_pass_d`, new `EL180_HELI_ID` | §3.D |
| Copal 1 ring OD and thickness | `NW_CLEAR`, `NW_BOARD` | §3.D |
| Nikkor-W barrel OD at the clamp land (73?) | `NW_D_TUBE` | ISCO clamp |

---

## 8. Documentation drift (README / PLAN / bom vs code)

| doc says | code does |
| --- | --- |
| PATH 179.5–193.5, infinity at helicoid 17.5 against 180 | `EL_FFD = 158.5`; PATH 158–172; seats recessed |
| standoff 16 mm, 3 mm to twist on | 13.5 mm, 0.5 mm (non-W); 21.5 mm (W) |
| printed F 43.5 mm / f/9.2 | `F_STL_THROAT = 40`, f/30; mesh not bored |
| "cookies flange on the bed, camera mouth up" | printed-F cookies have a 45° bed face (`cookie_print_flat`) |
| stem "cookie flange on the bed, M62 boss up" | `stem_bed_chamfer` intends a 45° print |
| badge inlays in the chassis wall, 10 mm wall, 7 mm behind the pocket | badge on a 4 mm screw-in cookie, 1.5 mm behind the pocket, open frame behind |
| chassis floor "solid slab" (code comment) | honeycomb open to the chamber |
| `export_fxpan.sh`: 75×75 plate, F_BORE 43.5 | 50×75, F_BORE 44 |
| bom: "M62 helicoid … do not substitute a longer one" | true, and also do not accept a wider one (§3.D) |
| Nikkor-W not mentioned in README/PLAN at all | `STEM=2`, `stem_w`, `stem_nw180`, `arm_*_w/fw/hw`, `W_ARM_EXTRA` |

---

## 9. How to verify each fix

```sh
O=/Applications/OpenSCAD.app/Contents/MacOS/OpenSCAD
cd openscad/fxpan

# Echo the W build's numbers (after adding the §4.6 echoes)
$O -o /tmp/x.echo -D 'PART="shims"' -D ARM_MOUNT=1 -D STEM=2 WATCH_ME.scad; cat /tmp/x.echo

# Top view with the (new) asymmetric ghosts — look at the +X+Y corner
$O --preview -o /tmp/top.png --projection=o --imgsize=1600,1600 \
   --camera=40,40,0,0,0,0,560 -D ARM_MOUNT=1 -D STEM=2 -D SHOW_GHOSTS=1 -D SHOW_LID=0 WATCH_ME.scad

# Base pad vs register: must print 0 after the §3.C fix
#   echo(base_cam_d() - (d_plate_to_mount() + arm_extra() + d800_tripod_in()));

# Mouth f-stop after re-boring or setting F_THROAT from a measured ring
#   look for "mouth: ... corner-to-corner from f/…" in the echo

# Ray trace still agrees (update FSTOP claims in fxpan_paths.py if F_THROAT changes)
python ../../kraken/fxpan_paths.py

# Export just the W parts
./export_fxpan.sh stem_w stem_nw180 arm_r_fw arm_t_fw base cradle_r cradle_t
```

Acceptance for "will it work": a D800 twists onto each arm with the other
body in place (§3.B), the 1/4-20 sits mid-slot (§3.C), the Copal ring runs
down ≥ 2.5 mm of thread (§3.D), the echo says infinity margin ≥ 1.5 mm, and
a flat wall at f/11 shows no straight-edged corner shading on either sensor
(§3.A, §4.4).

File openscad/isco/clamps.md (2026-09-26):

# ISCO clamps

Printed (or CNC) collars that hang the ISCO Ultra-Star HD Cinemascope
attachment on the taking lens. There are three variants:

| Clamp | Taking lens | STL | SendCutSend STEP |
| --- | --- | --- | --- |
| **M62** | EL-Nikkor 180/5.6N (external M62 on the front barrel) | [`isco_clamp.stl`](../../stls/isco/isco_clamp.stl) | [`sendcutsend/isco_clamp.step`](sendcutsend/isco_clamp.step) |
| **Nikkor-W** | Nikkor-W 180/5.6 in Copal No. 1 (Ø73 barrel land) | [`isco_clamp_nw.stl`](../../stls/isco/isco_clamp_nw.stl) | [`sendcutsend/isco_clamp_nw.step`](sendcutsend/isco_clamp_nw.step) |
| **EF 100L** | Canon EF 100mm f/2.8L Macro IS USM (female 67 mm filter) | [`isco_clamp_ef100.stl`](../../stls/isco/isco_clamp_ef100.stl) | — |

Parts list and fasteners: [`bom.md`](bom.md).

Source: [`isco_mount.scad`](isco_mount.scad). Preview in
[`WATCH_ME.scad`](WATCH_ME.scad) — set `PART` to **M62 clamp**,
**Nikkor-W clamp**, **Nikkor-W + ISCO**, **EF 100L clamp**,
**EF 100L + ISCO**, or **Full assembly section**.

## What each clamp does

Both clamps grip the ISCO attachment on its **Ø70.6 mm rear tube**, not on
the Ø67 rear thread. A shoulder inside the front pocket stops that face.
The Ø67 thread sits in a deeper pocket on the lens side of the shoulder and
cannot reach the taking lens.

### M62 clamp (`isco_clamp`)

One piece for the EL-Nikkor:

1. **Female M62×1** (9 mm engagement) screws onto the lens's external
   front thread and seats on the Ø76 shoulder behind it. The bore through
   the seat flange is the same **Ø62** as the thread, so there is no
   smaller step for the male to bottom on.
2. **Split collar** (ID 71 mm) closes on the ISCO's Ø70.6 land.
3. **Two M3 screws** through the ears pinch the ISCO collar only — the slot
   does not cut the M62 thread.

### EF 100L clamp (`isco_clamp_ef100`)

Male **M67×0.75**, 3.5 mm, screws into the Canon's filter thread and
seats on the front rim. Hood ET-73 comes off first. A **Ø64** barrel
carries the thread; the light hole through it is **Ø56**. The ISCO collar in front is the same pocket as the
M62 clamp. Four M3×4×5 inserts, two screws on the ISCO collar.

### Nikkor-W clamp (`isco_clamp_nw`)

One piece for the Nikkor-W 180/5.6:

1. **Rear collar** (ID 73.4 mm) grips the Ø73 barrel land. A **0.9 mm lip**
   drops into the 1.1 mm groove at the shutter junction so the clamp cannot
   slide along the barrel.
2. **M67 filter bore** stays open through the front flange so the taking
   beam is not blocked.
3. **Front collar** (same ISCO pocket as the M62 clamp) grips the Ø70.6
   land and stops the attachment shoulder.
4. **Four M3 screws** — two on the lens collar, two on the ISCO collar.

The W clamp is longer (~64 mm vs ~38 mm) because the ISCO pocket sits
forward of the Nikkor-W's front rim, not on the lens thread.

## Assembly

### EL-Nikkor + ISCO

```
[180 barrel] ← M62 female ← [isco_clamp] → ISCO Ø70.6 land ← [attachment]
```

1. Thread the clamp's M62 female onto the 180's external front thread until
   the back face seats on the Ø76 shoulder.
2. Slide the ISCO attachment in from the front. The Ø67 rear thread nests
   in the pocket; the Ø70.6 face stops on the shoulder.
3. Rotate the attachment for horizontal (theatre focus is forgiving).
4. Tighten both M3 screws into the heat-set inserts.

### Nikkor-W + ISCO

```
[Nikkor-W Ø73 land] ← rear collar ← [isco_clamp_nw] → ISCO Ø70.6 ← [attachment]
```

1. Seat the clamp on the Ø73 land with the lip in the groove
   (`z = NW_SHUTTER + NW_GROOVE` in the model).
2. Tighten the two **rear** M3 screws (lens collar).
3. Install the ISCO attachment as above.
4. Tighten the two **front** M3 screws (ISCO collar).

Preview with `PART = "nw"` in `WATCH_ME.scad`.

## Print

| Part | Orientation | Notes |
| --- | --- | --- |
| `isco_clamp` | M62 bore vertical, ears up | **M3 × 4 × 5 mm** inserts press in from the **+Y** ear face. The clamp bore is **through**; screw heads sit on the −Y face. |
| `isco_clamp_nw` | Lens end down, ears up | Same insert and through-bore rule. The lip goes toward the lens. |

**Material:** PETG, ABS, or PCTG. Not PLA — you are pinching a kilo of
glass on a split collar.

**Infill:** 40%+ on the collar walls; the ears see the screw load.

**Threads:** the STLs model M62 as a helix for preview. A real printed M62
female is unreliable at this scale — chase the bore or use the metal STEP
from SendCutSend and tap M62×1 yourself.

## CNC (SendCutSend)

Upload the STEP from [`sendcutsend/`](sendcutsend/). Bores are plain
cylinders (no helix). Regenerate the Nikkor-W file after model changes:

```bash
/tmp/cqvenv/bin/python openscad/isco/sendcutsend/export_nw_clamp.py
```

The EL clamp STEP was exported the same way (see git history). Instant
quotes on SendCutSend are for flat sheet; these parts change thickness, so
expect a custom quote.

| Part | Bounding box | Volume |
| --- | --- | ---: |
| `isco_clamp.step` | 115 × 84 × 38 mm | ~45 cm³ |
| `isco_clamp_nw.step` | 117 × 84 × 64 mm | ~100 cm³ |

## Bench stand

[`isco_stand.stl`](../../stls/isco/isco_stand.stl) is optional — a cradle
under the Ø90 ISCO barrel at **70 mm** axis height (FXPAN optical axis).
One **1/4-20 × 6.4 mm** heat-set insert in the foot, opening downward.
Preview with `PART = "stand"` or **Full assembly**.

## FXPAN body

On the FXPAN 65 chassis, preview the EL stack with `PART = "isco"` in
[`../fxpan/WATCH_ME.scad`](../fxpan/WATCH_ME.scad). The Nikkor-W stack uses
the helicoid nose on the stem, not this clamp on the taking lens — the W
clamp is for bench testing or a fixed lensboard mount outside the body.

## Export

```bash
./export_stls.sh --isco isco_clamp isco_clamp_nw isco_stand
```

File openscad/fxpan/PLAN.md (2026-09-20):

# FXPAN 65 — design plan

Read this before changing anything in `openscad/fxpan/`. It records the
numbers, where each one comes from, and which ones you are not free to move.
The body is a clean sheet: it shares no printed part with `hybrid_shift/`,
`hybrid/` or `v/`, and its bore is deliberately wider than theirs.

**What it is.** Two D800 bodies behind one EL-Nikkor 180/5.6N and a
50 × 75 × 1 mm 50/50 plate beamsplitter at 45°. Each sensor takes one half
of the field; the two frames stitch to **64.80 × 23.9 mm, 2.711:1,
13248 × 4912 = 65.1 MP**. XPan is 65 × 24 mm and 2.708:1, so the aspect is
within 0.1%. Horizontal field is **20.4°** — read the honest limits below
before you get excited about that.

The frame is corner-to-corner clean from **f/8.4**, limited by the 44 mm
Nikon F throat. Verify it yourself with `kraken/fxpan_paths.py`, which ray
traces the thing and exits non-zero if the geometry stops agreeing with
`params.scad`.

## The constraints that set everything

Every number in `params.scad` falls out of these pulling against each other.
The first four are optical and mechanical and are load-bearing; 5 and 6 are
things the build got wrong and how. If you change one, re-derive the others.

### 1. The plate has to pass the whole frame

A plate tilted 45° presents only `size/√2` across its plane of incidence.
`cam/pano.py` requires landscape sensors with a horizontal seam, so the wide
stitch axis is forced onto exactly that foreshortened dimension — there is no
orientation trick available.

The exit pupil sits at the lens, `EL_FOCAL` from the sensor. At a station `d`
ahead of the sensor, a field half-width `ym` fills

```
ym·(P−d)/P + (P/2N)·(d/P)          P = EL_FOCAL = 180, N = f-number
```

That is largest at the sensor and smallest at the lens, so **the plate wants
to be as far forward as it will go, and stopping down only ever helps.** With
the plate at `d = 112.5 mm`:

| f-stop | across the fold (`ym` = 32.4) | `BS_W` = 75 → 53.03 | `BS_W` = 50 → 35.36 | along the fold (`ym` = 11.95) | `BS_H` = 50 |
| --- | --- | --- | --- | --- | --- |
| 5.6 | 44.39 mm | +19.5% | clips | 29.05 mm | +72.1% |
| 8 | 38.36 mm | +38.2% | clips | 23.03 mm | +117.1% |
| 11 | 34.53 mm | +53.6% | +2.4% | 19.19 mm | +160.6% |
| 16 | 31.33 mm | +69.3% | +12.9% | 15.99 mm | +212.7% |

So: **75 mm across the fold, clean from f/3.9. 50 mm there only works from
f/11.** This is the whole reason the body is not just a rebore of
`hybrid_shift`.

### 1a. But only one of the plate's two directions is doing that job

The foreshortening is in the plane of incidence and nowhere else. Across the
fold the plate carries the 64.80 mm stitch through a √2 squeeze; along it
there is no squeeze and nothing to carry but the 23.9 mm sensor height, which
wants 29.05 mm at f/5.6. A square plate therefore buys margin in the one
direction that never needed any — and pays for it in chassis height, because
`BOX_Z` is set by the along-the-fold dimension and nothing else.

`BS_SIZE` is split into **`BS_W` = 75 across and `BS_H` = 50 along**, which is
Edmund **#37201**, a stock part. `BOX_Z` follows `BS_H` and falls from 108 to
**83**, which is 25 mm of chamber that was holding a 4.5× margin on the easy
axis. It buys nothing in the path budget — `BOX_XY` is the direction that
costs path — but it is 25 mm less print, and the tray, lid and chamber all
shrink with it.

Two consequences worth knowing before you move either number:

- **`BOX_Z` no longer sets how high the cameras sit.** It used to be close
  enough to the right height that the cradles could be read off it. See the
  load path section: the datum is now `d800_axis_base()`, and
  `chassis_plinth()` makes up the difference.
- **`bs_in_plane()` reads `BS_W`, `frame_top_z()` reads `BS_H`.** They are not
  interchangeable. If you fit a plate the other way round, the stitch crosses
  50/√2 = 35.36 mm and clips until f/11 while the chamber grows 25 mm. The
  tray slot is keyed to the right orientation, but the slot will not stop you
  putting a square plate in sideways.

### 2. The F throat has to pass the frame corners, and mostly can't

This is the constraint that actually limits the body, and the one that is
easiest to get wrong — I got it wrong first time round and the ray trace
caught it.

A bore is round, so what matters is **distance from the bore axis**, and the
corner of a 36 × 23.9 mm window is 21.6 mm from its centre against the 18 mm
the stitch axis alone suggests. Working the bore along the stitch axis
understates it by 3.4 to 4.3 mm. So `need_bore()` is evaluated at the corner:

```
c  = corner·(P−b)/P + shift·(b/P)        corner = (18, 11.95)
r  = |c| + (P/2N)·(b/P)
```

At the F flange (`b = 46.5`) that gives **46.77 mm at f/5.6**, against the
**44.0 mm** a real Nikon F throat provides. So:

| f-stop | corner needs | 44 mm throat | traced corner illumination |
| --- | --- | --- | --- |
| 5.6 | 46.77 mm | clips | 0.836 |
| 8 | 44.28 mm | clips | 0.951 |
| 11 | 42.69 mm | clears | 1.000 |
| 16 | 41.37 mm | clears | 1.000 |

**The frame is fully lit from f/8.4.** Wide of that the corners lose light
while the stitch axis stays perfectly clean, so it shows up as corner
shading, not as a broken stitch.

Three things follow. The first two are mount physics; the third is which mesh you print:

- **44 mm is a ceiling, not a choice.** `F_BORE` is set to 44.0 so the printed
  part is flush with the ring and the bought ring is the sole limit. It used
  to be 43.5, which cost a third of a stop for nothing.
- **An unshifted D800 needs 40.35 mm there at f/5.6.** The F throat only ever
  had 3.65 mm of margin; a 14.4 mm shift spends essentially all of it. This is
  a property of putting a shifted full-frame bundle through an F mount, not of
  this design.
- **The printed bayonet is 43.5 mm, not 44.** Archive-663 `f-mount_archive663.stl`
  (male lens-rear) is bored to the modelled bayonet ID. That is clean from
  **f/9.2**. The old scanned `f-mount_raw.stl` was 38.0 mm and never cleared
  the 38.47 mm corner term. Metal reverse ring stays the f/8.4 ceiling.

The only way to buy f/5.6 back is to shrink the shift to 8.29 mm, which drops
the stitch to 52.6 mm and 2.20:1 — it stops being an XPan frame. Not worth it.

### 3. The path has to land on 180 mm

`PATH` is lens flange to sensor along the fold, and it has to reach the
EL-Nikkor's flange focal distance for infinity. It is

```
PATH = BOX_XY + 2·PORT_PATCH_T + ARM_TUBE + F_REV_STACK + FLANGE_F
       + EL180_M62_LEN + (helicoid − EL180_HELI_MALE)
```

Note `BOX_XY` appears once but spans both legs — **every millimetre of
chassis costs two millimetres of budget.** That is the trap. Two earlier
attempts died here:

- **A cube chassis does not fit.** A cube tall enough to stand a 75 mm plate
  on its diagonal is 111 mm, which makes `PATH ≥ 207 mm`. Infinity is then
  unreachable at any helicoid setting. This is why `BOX_Z` and `BOX_XY` are
  separate: `BOX_Z` (83) carries `BS_H`, `BOX_XY` (92) comes out of the
  path budget and only has to clear the shifted port windows. The two are
  still separate now that `BS_H` is 50 and they happen to be close — do not
  re-merge them, because `BS_W` can go back up without touching the path and
  `BOX_XY` cannot move without re-solving infinity.
- **A 20 mm M62 nut does not fit.** `hybrid_shift` puts a 20 mm female nut on
  its stem. 20 mm of nut plus 17 mm of collapsed helicoid is 37 mm on the lens
  side and blows the budget on its own. The stem here is an **8 mm female boss
  on the cookie and nothing else**; the bought helicoid's male bottoms
  straight onto it.

Result: `BOX_XY = 92` gives **PATH 179.5 … 193.5 mm**, so 180 mm lands at
17.5 mm of the helicoid's 17–31 mm travel.

| helicoid | PATH | subject |
| --- | --- | --- |
| 17.5 mm | 180.0 mm | infinity |
| 20 mm | 182.5 mm | 13.1 m |
| 24 mm | 186.5 mm | 5.2 m |
| 31 mm | 193.5 mm | 2.6 m |

`BOX_XY` is rounded **down** to a whole mm on purpose. Shims can only add
length, so a chassis 1 mm too large can never reach infinity, while one 1 mm
too small is fixed with a 1.0 mm shim.

### 4. The camera has to be able to physically go on

A D800 is not flat at its flange. Its front panel stands `D800_PROUD` ≈ 13 mm
past the bayonet's register face, and the body goes on by pushing that panel
toward the chassis and twisting to lock. So the F register has to stand off
the chassis face by at least that much, and the body is 146 × 123 mm against
a 100 mm chassis face, so there is **nowhere to relieve locally** — the whole
face has to be behind the line.

Everything between the chassis face and the register is arm tube and reverse
ring, and the chassis half-width cancels out of both sides:

```
standoff = ARM_TUBE + F_REV_STACK − (shell outboard of the cookie)
```

`BOX_XY` does not appear. That is worth stating plainly, because the instinct
is to shrink the chassis and it does nothing: shrinking `BOX_XY` frees path
budget, which is only useful because it lets `ARM_TUBE` grow by the same
amount. The first cut of this body had `ARM_TUBE = 5`, a 4 mm retaining wall
outboard of each cookie, and therefore **9 mm of standoff** — a D800 would
have hit the chassis 4 mm before the bayonet seated. For comparison,
`hybrid_shift`'s long variant, which has actually been built, has 19 mm.

Two changes, neither of which touches an optical number:

- **The outboard retaining wall is gone** (`chassis_shell_t()` is now just
  `patch_t()`). On the camera faces that wall was precisely what the front
  panel landed on. The cookie is stopped inboard by the chamber wall it sits
  against, all the way round by its rebate, and outboard by four countersunk
  M3s — a better joint than the wall was, and worth 4 mm.
- **`ARM_TUBE` is solved from the camera rather than picked**, and `BOX_XY`
  takes what the path budget has left. 5 mm becomes 8 mm, 95 becomes 92, and
  `PATH` is unchanged at 179.5 mm because the two trade 1:1.

That gives **16 mm of standoff against 13 mm of camera**, 3 mm to twist it on.
The lever is nearly spent: the floor on `BOX_XY` is 91.4 mm, where the shifted
port bore starts to break into the adjacent chamber wall, so `ARM_TUBE` cannot
go much past 9 without the helicoid running out of travel. If your bodies
measure more than 16 mm proud, `WATCH_ME.scad` will tell you infinity has gone
out of range rather than quietly building something that cannot focus.

### 5. A 0.75 mm pitch female thread has to be truncated

The reverse-ring mouths on the earlier bodies never took a ring: too loose to
start, would not run down. That is a profile fault, not a clearance fault.

`lib/threads.scad` cuts a sharp full-height V unless `tooth_height` says
otherwise. At P = 0.75 that is 0.650 mm of radial depth, against the 0.406 mm
a real M52 × 0.75 female has. The printed crests stand a quarter of a
millimetre proud, into the ring's thread *roots*. The ring then rides on those
crests rather than its flanks — line contact on a knife edge — so it rocks,
starts crooked and never bites. It feels like a bore that is too big, which
is why it was read that way for so long.

`F_REV_TOOTH = 0.52` truncates the crest back to the real minor and
`F_REV_CLEAR` puts the clearance on the major where it belongs, plus a 0.9 mm
lead-in at the mouth. `F_REV_CLEAR` is the only number a builder should have
to touch, and `PART = ringgauge` exists so they can find it in ten minutes
instead of in a three-hour arm print.

The lock was working against the thread too. An M3 nut wants 2.8 mm of radial
depth; the wall over the M52 female is `(TUBE_OD − F_REV_MAJOR)/2` = 3.0 mm.
A pocket sunk into that wall has to come out the far side, and the original one
did — a 5.7 mm window straight through the thread, twice, over 7 of the 8 mm of
engagement. Two gaps for the ring to jump on every turn.

So the nut goes **outboard** of the thread, in a lug, and only the 3.2 mm screw
crosses it. `rev_lock_r_out()` is `F_COLLAR_OD / 2` — the reverse ring's own
OD — because that is the only clearance statement that can be made about the
camera's front panel without measuring it: whatever the lug is, it is never
proud of the metal ring that already has to live in that gap. Strength comes
from `REV_LOCK_FLARE` widening each lug down onto the cookie instead of from
standing it further out, which also makes it overhang-free printed arm-up.

`REV_LOCK_HOME = 180` with `REV_LOCK_SPREAD = 90` puts the pair at **135° and
225°** from camera-up, square about the azimuth directly opposite it. Two
azimuths are already spoken for, and on both faces they sit the same way
round: `TUBE_FLASH_KEEP` rakes the OD back at camera-up for the pentaprism
nose, and the cookie runs out of plate at the shift azimuth, which is +90°
from camera-up on R and on T alike. The old pair sat at camera-up itself and
120° off it, so the first screw of the two had 1.4 mm of raked wall to work
with; these two have 0.93 mm of wall left over a full-depth thread and full
tube section behind them.

An earlier pass had them at 190° and 260°, which is also clear of both claims
but is not symmetric about anything. That was fine while the cookie was a
90 mm square with room to spare on every side. It is not fine now the plate is
sized off its features: a lug swung toward the shift azimuth is plate the
cookie has to grow to cover, in the direction it is already widest. Sitting
the pair square about 180° costs the same in both directions and nothing
across — see section 6.

`rev_lock_ok()` also replaced a test for a whole `F_REV_LEN` of tube. What the
lock needs is room for the nut slot to floor above the cookie face, and the T
arm is `bs_t_comp()` shorter than the R arm for the glass path — 7.697 against
8 — so it lost both screws to a 0.3 mm rounding and had nothing holding its
ring's clock at all.
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

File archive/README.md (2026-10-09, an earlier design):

# Archive

Kits that are not the Nikkor-W FXPAN.

| | |
| --- | --- |
| [EARLIER.md](EARLIER.md) | The D7000 hybrid, the V, the shift kits, the 5D, the α7, and the shadowgraph. Pictures and the old buy list. |
| [bom.md](bom.md) | Buy list for those bodies. |
| [OPTICS.md](OPTICS.md) | Path budget for the 173.5 mm D7000 box. |
| [openscad/](openscad/) | Their models. |
| [stls/](stls/) | Their print files. |
| [export/](export/) | `export_hybrid.sh`, `export_hybrid_shift.sh`, `export_hybrid_shift_fx.sh`, `export_shadowgraph.sh`, `export_efhybrid.sh`, `export_ehybrid.sh`. |

From the repo root, `./export_stls.sh --hybrid` still builds the D7000 hybrid.
The current camera is `./export_fxpan.sh`.

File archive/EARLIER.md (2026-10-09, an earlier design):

# Earlier bodies

These are the kits from before the Nikkor-W FXPAN: the D7000 hybrid and V, the shifted D800, the 5D and α7 forks, and the shadowgraph. The camera as built is the [FXPAN](../README.md). OpenSCAD for these kits is in `openscad/` here, print files in `stls/`, and the export wrappers in `export/`. Commands such as `./export_stls.sh --hybrid` still run from the repo root.

---

One taking lens. Two bodies. A **1.8×** stitch.

Each camera is aimed at a different half of a wider image (20% overlap). The taking lens is an enlarger/LF optic on an M42 helicoid — never a native-mount still lens. Path is `fold + register`. Math: [OPTICS.md](OPTICS.md). Buy list and assembly: [bom.md](bom.md).

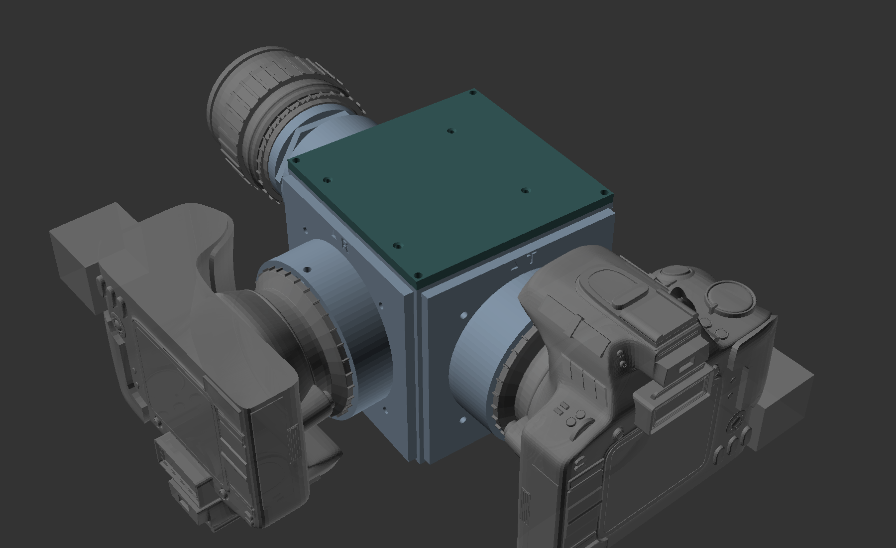
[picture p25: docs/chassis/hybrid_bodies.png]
Hybrid L with two D7000s


Hybrid L — D7000s on **▲ R** (+X) and **▲ T** (+Y), both **upright**. Stem is the EL-Nikkor. Bodies are preview ghosts; the print is the box, tubes, and `brace`. Tripod goes in the brace, not the box.

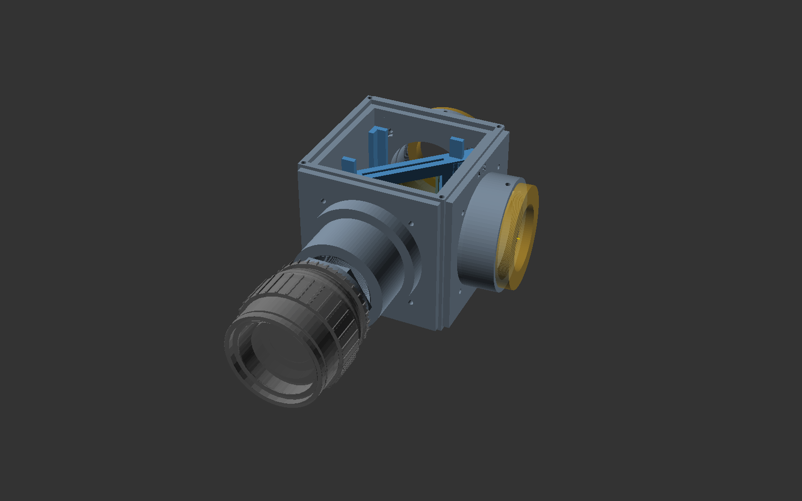
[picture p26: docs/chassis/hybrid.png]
Hybrid L, lid off

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

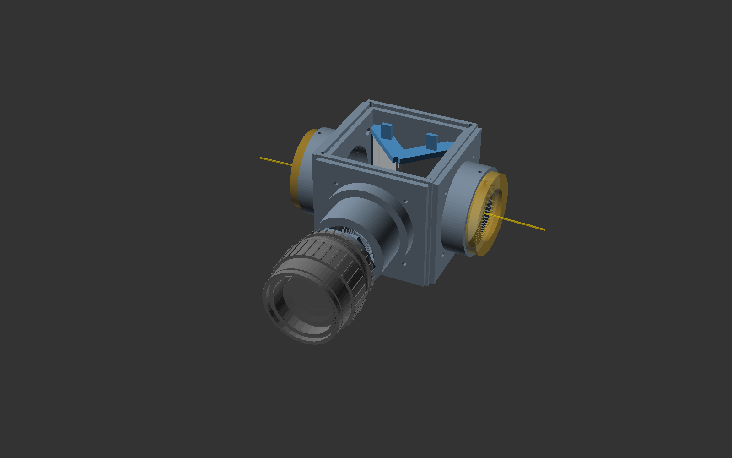
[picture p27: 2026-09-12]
docs/chassis/v.png

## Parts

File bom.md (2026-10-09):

# Bill of materials — FXPAN, Nikkor-W

This is the camera as built. Two D800 bodies, upright, behind a Nikkor-W
180 mm f/5.6 in a Copal No. 1. Focus is the M65 helicoid on the lens, not a
helicoid on each camera. The iPhone runs the app. The Pi Zero only fires
the shutters.

Rig

| | |
| --- | --- |
| Frame | 64.80 × 23.9 mm, 2.711:1, 13248 × 4912, 65.1 MP |
| Overlap | 20% |
| Taking lens | Nikkor-W 180/5.6, flange distance 178.8 mm on this stack |
| Plate | Edmund 50 × 75 × 1.0 mm, **75 across the fold** |
| Aperture | f/5.6 to f/22. The lens covers the stitch wide open. Extreme corners are fully lit from f/8.4; at f/5.6 they still pass most of the light |
| Viewfinder | iPhone, FXPAN app |
| Release | USB is enough. The trigger board is optional and pulses both 10-pin remotes together. Either way the frames come off USB from camera RAM |

Drawings and the measured arm lengths: [openscad/fxpan/README.md](openscad/fxpan/README.md).
Why the plate is this rectangle: [openscad/fxpan/PLAN.md](openscad/fxpan/PLAN.md).
Export: `./export_fxpan.sh`.

Earlier bodies, including the EL-Nikkor D7000 kits, are in
[archive/](archive/EARLIER.md).

## Optics

| Qty | Item | Why |
| --- | --- | --- |
| 1 | **Nikkor-W 180 mm f/5.6**, Copal No. 1 | The taking lens. 5×7 coverage, so the 64.80 mm stitch is inside the circle. Rear thread is the Copal ring, not M62. Used, search `nikkor-w 180mm f/5.6`. |
| 1 | **Pixco M65×1 helicoid, 17–31 mm** | Focus. Male into `stem_m65`, `stem_nw_m65` into the front. Infinity is about 1 mm out from collapsed. [Pixco 17–31](https://www.amazon.com/Pixco-Adjustable-Focusing-Helicoid-Shooting/dp/B01N1GOL39). |
| 1 | **Edmund #37201**, stock 35-947. 50 × 75 × **1.0 mm** 50R/50T, S2 broadband AR | 75 mm goes **across the fold**. At 45° that presents 53.03 mm; the frame needs 44.39 mm at f/5.6. The black dot is S1 and faces the lens. Do not cut it. [Edmund #37201](https://www.edmundoptics.com/p/50-x-75mm-50-50rt-vis-plate-beamsplitter/37201/). |
| 0 | Edmund **#17536**, the 50 × 75 × **3 mm** plate | Same page, same price, wrong thickness. It will not enter the slot, and the tilt astigmatism needs f/16. Check the thickness on the box. |

The EL-Nikkor 180/5.6N and its M62 helicoid are a different stem
(`stem` + `stem_el180_inf`). They are not on this camera. Their parts stay
listed in [openscad/fxpan/bom.md](openscad/fxpan/bom.md).

## Cameras, phone, sync

| Qty | Item | Why |
| --- | --- | --- |
| 2 | **Nikon D800**, no lens | 36 × 23.9 mm, 46.5 mm register. Both sit upright. |
| 2 | **Memory card**, CF or SD, any size that the body accepts | A D800 with Slot empty release lock set will ignore the 10-pin when the slot is empty. USB capture still works with no card, because that command writes to camera RAM directly. The 10-pin does not. Put a card in each body. The app still downloads the new frame from RAM. |
| 1 | **iPhone** running FXPAN | Live view, exposure, USB or 10-pin release, and the stitch. The screen replaces the Pi touch display. Build and install from [ios/](ios/). |
| 1 | Printed phone tray | [openscad/phone/WATCH_ME.scad](openscad/phone/WATCH_ME.scad). `./export_stls.sh --phone` writes `stls/phone/`. The 17 Pro Max cradle is `pm17_cradle` + `pm17_shoe`, one M3×16 and a nut. |
| 1 | **USB hub** the phone can see both bodies through | One session per D800. The phone has to drop both sessions before the 10-pin will fire, then open them again to download. |
| 1 | **Raspberry Pi Zero W** | USB gadget at 10.55.0.1. The phone sends `FIRE` to port 2323. Setup: [pi0w/README.md](pi0w/README.md). |
| 1 | **FXPAN trigger board** on the Zero's header | Four 4N35 optocouplers, two 3.5 mm jacks. Parts and the PCBWay zip: [gpio_trigger/bom.md](gpio_trigger/bom.md). |
| 2 | **3.5 mm TRS male to Nikon 10-pin male** | One per body. 3-pole, not TRRS. [Keabroir](https://www.amazon.com/dp/B0CYHL1B7F). |

The app

The app's Drive screen is where Release is set. **Sync** closes USB, pulses
the board (100 ms focus, then 300 ms shutter), and downloads both frames
from camera RAM. **USB** fires over PTP and does not use the 10-pin.

## Print

`./export_fxpan.sh` writes `stls/fxpan/`. This build uses these parts.
PETG or ABS, not PLA. The mouths and the cookie screws carry the bodies.

| Part | Qty | On the bed |
| --- | --- | --- |
| `chassis` | 1 | floor down. The lens face is opened to an 83.7 mm circle so the M65 helicoid can sit on the cookie. |
| `lid` | 1 | outer face down. Two M3 holes at the +Y corners. Six blind M2.5 holes on top take the Zero's standoffs. |
| `fxp_tray` | 1 | floor down. |
| `stem_m65` | 1 | cookie on the bed, boss up. Thread start is clocked so the Copal controls come out on top. |
| `stem_nw_m65` | 1 | Copal board up, male down on a raft. |
| `arm_r_wl`, `arm_t_wl` | 1 each | cookie on the bed, printed F up. Fixed registers 23.00 mm (R) and 22.62 mm (T), so both bodies peak at the same helicoid setting. |
| `base` | 1 | flat. Tripod insert and screw heads from the bed. |
| `cradle_r`, `cradle_t` | 1 each | flat. |
| `baffle` | 2 sheets | flat. One arm's rings per sheet. |

Logo inlays are optional. They drop into the chassis pocket as separate
filaments: gold FX, off-white PAN, red outline and 65MP, grey spec line.
The file names are `chassis_logo_*` in `stls/fxpan/`.

## Hardware

| Qty | Item |
| --- | --- |
| 12 | M3×12 countersunk, and 12 M3 nuts. Four per cookie, into the wall traps. |
| 2 | M3×20, and 2 M3 nuts. Lid to the chassis, +Y corners. Nuts go in before the tray. |
| 8 | M3×16, and 8 M3 nuts. Four per cradle, heads in the plinth, nuts under the base. |
| 2 | 1/4-20 heat-set insert, 6.4 mm long. One in the base, one in the chassis floor. Iron them in from the bed face. [CNC Kitchen 1/4-20×6.4](https://cnckitchenus.store/products/heat-set-insert-1-4-20x6-4-camera-thread-short-version-20-pieces). |
| 1 | 1/4-20 knurled thumbscrew. Chassis onto the base. |
| 2 | 1/4-20 × 25 mm. Up through the base and the cradle into each body. Check the socket depth before you tighten. |
| 1 | 1/4-20 tripod screw, into the base insert. The tripod is not in the chassis. |
| 4 | M2.5 × 10 mm male-female standoffs. Zero to the lid, header tails toward the lid. |
| 1 | Flocking, or flat black paint, in the chamber, the tray, both bores, and both F throats. The throats are unlined on purpose. A liner there vignettes. |

`arm_r_wl` and `arm_t_wl` are printed F-mounts. The cradles carry the
weight. The bayonet only takes the twist.

## Assembly

Lid off, plate in the tray.

The same parts pulled apart.

1. Heat-set the 1/4-20 insert into the base, and the other into the chassis floor, both from the bed face.
2. Flock the chamber, the tray, both bores, and both F throats.
3. Push the baffle rings in from the camera mouth, `fxp_bf1` first. They are numbered. Do not shuffle them. Reprint the set if you change `FSTOP`.
4. Plate into the tray. **Black dot toward the lens. 75 mm horizontal, 50 mm up.** The other way round, the stitch crosses 35 mm of glass and clips until f/11. Press it straight down between the centring ribs. A scrap of 1.75 mm filament through each 2 mm hole on the cheeks keeps it from lifting.
5. M3 nuts into the two lid slots, then the tray. The tray closes the slots.
6. Cookies into their pockets. **▲ R** with the R mark on the chassis, **▲ T** with T. Four M3×12 countersunk each. The stem cookie is stamped `fxp_stem`.
7. Lid on with two M3×20. The trigger stack sits on top, jacks toward R. Zero underneath, board on the 2×20 header, four standoffs into the lid.
8. Chassis onto the base with the thumbscrew. Cradles on with four M3×16 each.
9. Bodies. Start each 1/4-20 × 25 through the slot and leave it loose. Bayonet the body, then tighten the screw where the body landed. Do not pull the body onto the mount with the screw.
10. Lens. M65 helicoid into `stem_m65` until the body sits on the cookie. `stem_nw_m65` into the helicoid. Copal controls on top.

Both bodies need a card before the first synced release.

## Alignment

Focus, then roll, then the overlap. The numbers below are from this rig,
not from the drawing.

**Focus.** Collapse the M65 helicoid. Open it until a distant edge peaks on
T. That is about a millimetre. Check R on the Focus screen at that same
setting. The arms were reprinted so the two peaks meet: T at 17.81 mm of
helicoid (cookie face to lens face) and R at 20.38 mm on the first prints,
so R's arm is 23.00 mm and T's is 22.62 mm. If a later print does not meet,
the difference in helicoid height is how far to move R's arm. Set
`W_LENS_FOCUS_T`, `W_LENS_FOCUS_R`, and `W_WL_PRINTED_R`, and reprint
`arm_r_wl`.

**Roll.** A level horizon on both. The seam is horizontal, so relative roll
is a wedge. `STEM_W_CLOCK` is 90°, which puts the Copal controls on top.
Body roll is the printed F clock. `F_MOUNT_CLOCK` if a body comes up on its
side.

**Field.** Shoot something with detail across the frame and stitch it. The
app's overlap starts at 20%. Match will find the real overlap. Far from 20%
means a cookie is in the wrong port.

The measured arm lengths and the reprint numbers are in the
[FXPAN README](openscad/fxpan/README.md#alignment).

## What the simulation says

Fold

Frames at f/5.6. The corners fall off. The long axis does not.

Stitch at f/11

Margins

How wide a front anamorphic would make the same lens

`python kraken/fxpan_paths.py` ray-traces the body and fails if the geometry
drifts from these pictures.

## Pictures from the camera

Field

The same field, printed, and a second stitch of the tree line

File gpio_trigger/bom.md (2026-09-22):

# BOM — Pi dual TRS Nikon trigger

Based on [Building Block - Arduino Nano Remote Camera Trigger](https://www.instructables.com/Building-Block-Arduino-Nano-Remote-Camera-Trigger/).
**Raspberry Pi GPIO** replaces the Nano; **no battery**; **two synced 3.5 mm TRS outputs**.

**Amazon links:** Only listings that **Ship from Amazon** with **Prime 1–2 day** delivery (checked Sep 2026). Skip marketplace-only sellers and multi-week imports. If a direct link is out of stock, use the search link in that row and pick the same criteria.

## PCB version — order this

The bare board comes from PCBWay (upload [fab/pcbway/gpio_trigger-pcbway.zip](fab/pcbway/gpio_trigger-pcbway.zip)): **2-layer, 1.6 mm, FR-4, 1 oz, lead-free HASL, green mask, white silk**. These are the parts that go on that board. Perfboard, dupont jumpers, hookup wire, and a project box are not used. JP1 and JP2 are copper on the board. Pads 1–2 are already bridged, so both cameras follow pin 38 (focus) and pin 40 (shutter). Cut that bridge and solder pad 2 to pad 3 to put camera B alone on pin 37 (BCM 26, focus) and pin 35 (BCM 19, shutter).

| Qty | Item | Notes | Where |
|-----|---|---|---|
| 1 | **Fabricated PCB** | Stepped board, both jacks on the pin-1 end | [PCBWay zip](fab/pcbway/gpio_trigger-pcbway.zip) |
| 4 | **4N35** optocoupler, DIP-6 | Solder direct, or plug into optional sockets below. 2 per jack | [Search: 4N35 DIP-6, Prime](https://www.amazon.com/s?k=4N35+DIP-6+optocoupler&rh=p_90%3A8308921011) — pack ≥ 5, **Ships from Amazon** |
| 4 | **DIP-6 IC socket**, 7.62 mm row spacing | Optional. One per 4N35 (U1–U4). Tin-leaf or machine-pin — easier swap than soldering the chips | [Search: DIP 6 pin IC socket 7.62mm, Prime](https://www.amazon.com/s?k=DIP+6+pin+IC+socket+7.62mm&rh=p_90%3A8308921011) — **Ships from Amazon** |
| 8 | **330 Ω** resistor, ¼ W, axial | 4 required (R1–R4). R5–R8 only if you fit the matching LED. Mount standing up | [ELEGOO 525-piece 1/4 W kit](https://www.amazon.com/Elegoo-Values-Resistor-Assortment-Compliant/dp/B072BL2VX1) |
| 2 | **CUI SJ1-3535NG** 3.5 mm TRS jack, right-angle, PCB mount | Footprint on the board. **Not** a panel-mount jack — those will not fit the holes | [DigiKey SJ1-3535NG](https://www.digikey.com/en/products/detail/cui-devices/SJ1-3535NG/738699) — no matching Prime listing |
| 1 | **2×20 female pin socket**, 2.54 mm | Solder on the **bottom**. Square pad = Pi pin 1 | [Search: 2x20 female header, Prime](https://www.amazon.com/s?k=2x20+female+pin+header+2.54mm&rh=p_90%3A8308921011) — **Ships from Amazon** |
| 4 | **5 mm LED** | Optional. D1 camera 1 focus, D2 camera 1 shutter, D3 camera 2 focus, D4 camera 2 shutter (camera 2 follows the jumpers). Omit an LED and its 330 Ω together | Same ELEGOO kit — no extra order |
| 2 | **3.5 mm TRS male → Nikon 10-pin male** | One per D800. 3-pole only | [Keabroir 3.5 mm → N1 / 10-pin](https://www.amazon.com/dp/B0CYHL1B7F) — **order qty 2** |

## Perfboard version

Only if you are not ordering the PCB. Schematic: [schematic.svg](schematic.svg) · [layout-perf.svg](layout-perf.svg) · [BOARD.md](BOARD.md)

## Core board

| Qty | Item | Notes | Amazon (US) |
|-----|---|---|---|
| 4 | **4N35** optocoupler, DIP-6 | Solder direct, or use optional sockets below. 2 per camera jack | [Search: 4N35 DIP-6, Prime](https://www.amazon.com/s?k=4N35+DIP-6+optocoupler&rh=p_90%3A8308921011) — pick **pack ≥ 5**, **Ships from Amazon** |
| 4 | **DIP-6 IC socket**, 7.62 mm row spacing | Optional. One per 4N35 | [Search: DIP 6 pin IC socket 7.62mm, Prime](https://www.amazon.com/s?k=DIP+6+pin+IC+socket+7.62mm&rh=p_90%3A8308921011) — **Ships from Amazon** |
| 4 | **330 Ω** resistor, ¼ W | One per opto LED (Pi 3.3 V) | [ELEGOO 525-piece 1/4 W kit](https://www.amazon.com/Elegoo-Values-Resistor-Assortment-Compliant/dp/B072BL2VX1) (includes 330 Ω × 25) |
| 2 | **3.5 mm TRS jack**, panel mount | **3-pole stereo** (tip / ring / sleeve). Not TRRS | [Lsgoodcare 10-pack panel TRS](https://www.amazon.com/Lsgoodcare-Female-Headphone-Stereo-Connector/dp/B01CVGD4UI) |
| 1 | **Perfboard** | 2.54 mm pitch; 73×100 mm OK (layout shows 50×70) | [YUNGUI 10× 73×100 mm stripboard](https://www.amazon.com/YUNGUI-Prototype-perfboard-Sording-Electronic/dp/B088GSJM7G) |
| 1 | **2×20 female pin socket**, 2.54 mm | PCB plugs onto the Pi 40-pin GPIO header. Only pins 38, 39, 40 are wired | [Search: 2x20 female header, Prime](https://www.amazon.com/s?k=2x20+female+pin+header+2.54mm&rh=p_90%3A8308921011) — **Ships from Amazon** |
| 3 | **Dupont jumper**, female–male | Perfboard only, if you are not plugging the PCB onto the Pi | [ELEGOO 235-piece kit](https://www.amazon.com/dp/B077D2N4KT) (includes 20× F–M + spare 330 Ω / 1× 4N35 for bench) |
| 4 | **5 mm LED** + **330 Ω** | Optional. D1/D2 camera 1 focus/shutter, D3/D4 camera 2 focus/shutter. Omit an LED and its resistor together | Same ELEGOO kit — no extra order |
| 1 | **22 AWG silicone wire kit** | Camera-side runs to jacks | [BNTECHGO 10×30 ft](https://www.amazon.com/dp/B0881HCN37) |
| 1 | **Heat-shrink tubing kit** | Insulate solder joints | [Ginsco 580-piece](https://www.amazon.com/Ginsco-580-pcs-Assorted-Sleeving/dp/B01MFA3OFA) |
| 1 | **Project box** | ~200×120×75 mm ABS; drill for 2 jacks | [Pinfox ABS enclosure 200×120×75](https://www.amazon.com/Waterproof-Electronic-Plastic-Junction-Enclosure/dp/B06XSMK61Q) |

### Bench LEDs (optional — Pi side only)

Included in the [ELEGOO 235-piece kit](https://www.amazon.com/dp/B077D2N4KT) above (LEDs + 330 Ω / 1 kΩ resistors). No extra order needed.

## Cables to cameras (FXPAN)

| Qty | Item | Notes | Amazon (US) |
|-----|---|---|---|
| 2 | **3.5 mm TRS male → Nikon 10-pin male** | One per D800; 3-pole only | [Keabroir 3.5 mm → N1 / 10-pin](https://www.amazon.com/dp/B0CYHL1B7F) — **order qty 2** (listing is one cable) |

Vello RCCN135 and other coiled remotes are often **out of stock** on Amazon US; the Keabroir cable above is **Ships from Amazon** with Prime.

No Y-lead needed if both jacks are on this box.

## Not used (vs Instructables)

| Item | Why omitted |
|---|---|
| Arduino Nano | Pi BCM 20 / 21 |
| Battery / 5 V supply | Pi powers opto LEDs only |
| Tactile switches | `gpio_seq.py` |

## Pi / software

| Item | Notes |
|---|---|
| Raspberry Pi 5 (or 4) | User `gpio` group; `python3-libgpiod` |
| `gpio_trigger/gpio_seq.py` | Focus-then-shutter test |

## Optional — MC-22 instead of TRS jacks

| Qty | Item | Notes | Where to buy |
|-----|---|---|---|
| 1 | **Nikon MC-22** | Blue = focus, yellow = shutter, black = ground | [Nikon USA MC-22](https://www.nikonusa.com/p/mc-22-remote-cord-with-banana-plugs-394-in/4652/overview) — skip slow Amazon marketplace listings |

Wire opto collectors to the banana plugs; see [README.md](README.md).

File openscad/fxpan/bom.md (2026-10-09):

# Bill of materials — FXPAN 65

The camera as built is the Nikkor-W stack. Its buy list and assembly are
[../../bom.md](../../bom.md). This file is the longer list: the EL-Nikkor
180/5.6N stem, the plate substitutions, and the anamorphic clamps.

Two D800 bodies behind one taking lens and a **50 × 75 × 1 mm** 50/50 plate
at 45°. Stitch is 64.80 × 23.9 mm, 2.711:1, 65.1 MP. On the EL-Nikkor the
path is **179.5 … 193.5 mm**, infinity at 17.5 mm of M62 helicoid travel.
The Nikkor-W's flange is 178.8 mm and it focuses on the M65 helicoid.

The stitch is shot from **f/5.6 to f/22**. The Nikkor-W covers it wide
open. f/8.4 is only the stop where the 44 mm mouth passes the last corner
ray. The two items below are what change that, and the rest is fasteners.

Nothing on this list needs measuring except your own cameras: the F register
stands 16 mm off the chassis face so a D800's front panel, which reaches
about 13 mm past its own flange, has room to come in and twist on. If yours
measures more than 16, set `D800_PROUD` before you print anything.

- **75 mm across the fold, 50 along it — and not a square.** At 45° a plate
  presents only `size/√2` in its plane of incidence, and that is the direction
  the 64.80 mm stitch has to cross: it needs 44.4 mm there at f/5.6, 75 mm
  gives 53.03, and the 50 mm square you already own gives 35.36 and clips
  until f/11 — clipping the long axis of the panorama, not just the corners.
  Along the fold nothing is foreshortened and nothing is being carried but the
  23.9 mm sensor height, so 50 mm is already +72% and a square plate is 25 mm
  of chassis height bought for a margin nobody will ever spend.
- **Metal reverse rings, not the printed bayonet — still the default.** The ring keeps the real
  44 mm F throat, which is what sets the f/8.4 limit. The printed Archive-663 mouth is
  43.5 mm (f/9.2) after the lips are bored; close, not equal.

Why: [PLAN.md](PLAN.md). How: [README.md](README.md).

## Optics

| Qty | Item | Why | Link |
|-----|---|-----|---|
| 1 | **Edmund #37201** (stock #35-947) — 50 × 75 × 1.0 mm 50R/50T VIS plate beamsplitter | Takes the plate off the list of things that limit this body: **75 goes across the fold**, presenting 53.03 mm against the 44.39 mm the frame needs, **+19.5% at f/5.6** and more as you stop down. The 50 runs along the fold, where nothing is foreshortened and 29.05 mm is all that is asked, so it is +72% and it is the dimension that sets chassis height — which is why this is the right rectangle rather than the 75 × 75. S1 is 50/50 ±5% at 550 nm, ±10% over 400–700. S2 is broadband AR, Ravg ≤1%. 1.0 mm thick, which is the other thing that has to be right. Do not cut it. Edmund marks the coated face with a **black dot**: that dot faces the lens, and the 75 goes horizontal. | [Edmund #37201](https://www.edmundoptics.com/p/50-x-75mm-50-50rt-vis-plate-beamsplitter/37201/) |
| 1 | **EL-Nikkor 180 mm f/5.6N** (or Componon-S 180, Rodagon 180) | Taking lens. 5×7 image circle, so the 64.80 mm stitch is nowhere near the edge of coverage. `EL_FOCAL = 180` is what the whole path budget is solved against. Barrel is **M62**, not L39 — it threads into the helicoid directly. Used $200–500. | [eBay EL-Nikkor 180](https://www.ebay.com/sch/i.html?_nkw=el-nikkor+180mm+f%2F5.6) · [Componon-S 180](https://www.ebay.com/sch/i.html?_nkw=componon-s+180) · [Rodagon 180](https://www.ebay.com/sch/i.html?_nkw=rodagon+180) |
| 1 | **M62×1 helicoid, 17–31 mm** | Focus. Male bottoms into the stem's 8 mm female boss; female takes the lens. Infinity lands at 17.5 mm, near collapsed, and the full 14 mm of travel reaches 2.6 m. **Do not substitute a longer one** — the 17 mm collapsed length is inside the path budget and anything taller pushes infinity out of reach. | Search **M62 focusing helicoid 17-31**. An M65×1 17–31 ([Pixco](https://www.amazon.com/Pixco-Adjustable-Focusing-Helicoid-Shooting/dp/B01N1GOL39)) is the same travel, but both ends are M65×1. Amazon has no M65×1↔M62×1 ring. A filter step ring is 0.75 mm pitch and 6–7 mm tall, and infinity only has 0.5 mm to spare. |
| 1 | **M65×1 male to M62×1 female, flangeless** (only with the M65 helicoid) | Lens end. The 180's rear is M62×1; the M65 helicoid's front female is M65×1. Added length is **0 mm**, so the flange still seats where the path budget says it does. Do not put a ring on the stem side — print `stem_m65` so the helicoid male still bottoms on the cookie. The STEP is the finished threads, M65×1 outside and M62×1 inside, 8 mm long. | [RafCamera, flangeless, 0 mm](https://rafcamera.com/adapter-m65x1m-to-m62x1f-flangeless). Ships from Belarus, not Prime. CNC: [`sendcutsend/m65_m62_flangeless.step`](sendcutsend/m65_m62_flangeless.step). |
| 1 | Printed `m65_ring` | Stand-in until that ring arrives. Plastic has no wall between an M65 male and an M62 female, so the lens thread sits in a collar in front of a shoulder and the ring **adds 8 mm**. Collapsed focus is about **4.5 m**, not infinity. Face the 6 mm male shorter if the shoulder does not seat. Take the ring off when the metal one lands. Do not shorten the stem to make up the 8 mm — shims only add, and the metal ring is 0 mm. | `PART=m65_ring` in `WATCH_ME.scad`. Lens seat up. Print `stem_m65` with it. |
| 2 | **Fotodiox Nikon F reverse ring, 52 mm** | The camera mouths. Threads into the arms' M52×0.75 female, presents an F bayonet with the **real 44 mm throat**. That throat is what sets the body's f/8.4 limit, and 44 mm is as wide as an F mount gets — so this is both the recommended mouth and the ceiling. `ARM_MOUNT = 0` is the default for it. **Buy them before you print the arms** — you need one in hand to read the ring gauge. | [Fotodiox 52 mm F reverse](https://www.amazon.com/Fotodiox-Reverse-Adapter-Compatible-Cameras/dp/B001G4NBSC) |
| 2 | **M52 female to M42 male focusing helicoid, 17–31 mm** | One per camera, on `arm_r_hw` / `arm_t_hw`, instead of shimming the bodies. Amazon does not list an M52-to-M52. This is the Pixco/Fotasy unit the search returns: **M52 female in front, M42 male in the rear**, 17 mm collapsed to 31 mm. The M42 male screws into the cookie. A metal M52-male F ring screws into the front female. Collapsed sits inside focus; the travel moves that camera out, and the tripod screw locks it. Measured: body **69.05 mm**, 16.68 mm collapsed past a 4.67 mm M42 male, front does not rotate. Its male bottoms on a lip in the cookie. Take the **17–31**, not the 10–15. Confirm the photo: 42 mm male toward the cookie, 52 mm female toward the camera. | [Amazon: M52 to M42 helicoid 17–31](https://www.amazon.com/s?k=M52+to+M42+helicoid+17-31) |

### Which way round it goes, and what else fits

The plate is not square, so it can be fitted wrong. **75 mm horizontal,
across the fold.** The tray slot is keyed for it, but the slot will not stop
you turning the glass over in your hand first.

| | across the fold | along the fold |
| --- | --- | --- |
| what it carries | the 64.80 mm stitch, foreshortened by √2 | the 23.9 mm sensor height, not foreshortened |
| needs at f/5.6 | 44.39 mm | 29.05 mm |
| `BS_W` = 75 → 53.03 | **+19.5%** | — |
| `BS_H` = 50 | — | **+72.1%** |
| sets | nothing else | `BOX_Z`, and therefore the chassis |

Substitutions, in order of preference:

| plate | stock # | thickness | verdict |
| --- | --- | --- | --- |
| **#37201, 50 × 75** | 35-947 | **1.00** | the build. $303, in stock. |
| [#37202](https://www.edmundoptics.com/p/75-x-75mm-50-50rt-vis-plate-beamsplitter/37202/), 75 × 75 | 35-948 | 1.00 | optically identical and the original pick — it went to *Contact Us*, which is why the body is drawn around the rectangle. Set `BS_H = 75` and `BOX_Z` grows back to 108 by itself. $338 for 25 mm more chassis and no more picture. |
| [**#17536**](https://www.edmundoptics.com/p/50-x-75mm-50r50t-vis-plate-beamsplitter/17536/), 50 × 75 | 62-882 | **3.00** | **the trap.** Same size, same family, same page title, same $303, and 20+ in stock while the right one may not be. Three stops of astigmatism (below) and it will not go in the slot. **Check the thickness, not the size.** |
| [#43-359](https://www.edmundoptics.com/p/50-x-50mm-50r50t-plate-beamsplitter/4985/), 50 × 50 | — | 1.00 | S2 uncoated, and only 50 across the fold — see the f/11 table below. |
| [#45-854](https://www.edmundoptics.com/p/50-x-50mm-50r50t-vis-plate-beamsplitter/6281/), 50 × 50 | — | 3.00 | both faults at once. No. |

If all you have is a 50 mm square, `BS_W = 50` still builds and costs nothing
in chassis height. It is a real fallback, just an honest **f/11 one**:

| f-stop | need across the fold | 50 mm gives 35.36 |
| --- | --- | --- |
| 5.6 | 44.39 mm | clips |
| 8 | 38.36 mm | clips |
| 11 | 34.53 mm | +2.4% |
| 16 | 31.33 mm | +12.9% |

### Why 1 mm and why AR

Neither of these is a preference; both are the difference between sharp and
not. A tilted plate puts its errors on the **transmit path only** — S1 faces
the lens, so the reflected light never enters glass.

**Astigmatism** from the tilt, against depth of focus at c = 0.020 mm:

| thickness | astigmatism | verdict |
| --- | --- | --- |
| 1.0 mm | 0.172 mm | inside the 0.224 mm depth of focus at **f/5.6** |
| 3.0 mm | 0.516 mm | needs **f/16** before it hides |

So a 3 mm plate costs you three stops of usable aperture on one of the two
cameras, and it will not drop into the tray slot either.

**Back-surface ghost.** Light reflecting off S2 lands **0.743 mm** from the
real image, which is **152 px** on a D800 — far enough to read as a distinct
double, close enough to sit inside the subject.

| S2 | ghost intensity |
| --- | --- |
| uncoated | 4.0% of the T image |
| broadband AR | 1.0% |

Only the T camera gets it, which is worse than it sounds: the stitch would
have a ghost on one side of the seam and none on the other. #37201 is AR
coated, so this costs nothing on the recommended build.

## Anamorphic adapter (optional)

Not required. Spherical FXPAN is already XPan's 2.71:1 at 20.3°. A cylinder
on the **front** of the 180 is how you go wider without changing the chassis.
Rear M62 is already in the helicoid; `EL180_LENS_OD` is 76 mm and there is
no useful front filter thread, so everything clamps onto the barrel. Measure
that OD on your own 180 before you order a clamp.

Same Tuscany still as [`docs/kraken/fxpan_anamorph_scene.png`](../../docs/kraken/fxpan_anamorph_scene.png): 1.5× is 30.1° / 26.9 m / 4.07:1; 1.33× is 26.8° / 23.9 m; 2× is 39.5° / 35.9 m / 5.42:1.

**This build is 2× HD.** Compact Gold / Iscorama / SLR Magic below stay as
the unused families. **Do not keep** the red spherical taking lens, and do
not confuse this with ISCO Ultra-Star HD Plus **60 mm integrated** (stock
**748.50.06**) — that is a 60 mm f/2.1 projector lens, BFL 36 mm, 21.3 × 18.2
mm Scope gate, one barrel, does not unscrew into an adapter.

| Qty | Item | Why | Link |
|-----|---|-----|---|
| 1 | **Schneider 1101111** — ISCORAMA 54 CU-1.5× (MFR **08-1101111**) | The stills pick. 1.5×, rear **M77×0.75** female, 1.4 m close focus, 1/4-20 support bracket in the box, M77/M72 SLIM already mounted. $4,950 new. Vintage **Iscorama 54** (ISCO-Göttingen, same 77 mm rear) is the used equivalent, usually cheaper, dual-focus. Schneider **1104267** M77/M62 is the *wrong* M62 — that is the 180's rear, already occupied. | [Duclos 08-1101111](https://www.ducloslenses.com/products/iscorama-54) · [Schneider IDs](https://schneiderkreuznach.com/en/cine-optics/lenses/isco-family) · used [Iscorama 54](https://www.ebay.com/sch/i.html?_nkw=iscorama+54) |
| 1 | **RafCamera custom: 76 mm ID clamp → M77×0.75 male** | So the Iscorama's female rear can screw onto the 180. Stock [76 mm → M77 female](https://rafcamera.com/clamp-76mm-to-m77x0-75f-od80mm) is a filter ring, wrong gender. Print a collar if you would rather. Measure first. | [RafCamera custom](https://rafcamera.com/custom-adapter) |

1.33× if you want new, light, and in-catalogue rather than the extra 9°:

| Qty | Item | Why | Link |
|-----|---|-----|---|
| 1 | **SLR Magic SLRA65133X** — Anamorphot-65 1.33× | Rear **82 mm**, takes a 65 mm front element (the 180's pupil is 32 mm). B&H **SLMA13365A**. Anamorphot-40/50 are 52/62 mm rear and will not reach a 76 mm barrel. | [B&H SLRA65133X](https://www.bhphotovideo.com/c/product/1413511-REG/sigma_slra65133x_anamorphot_65_1_33x_anamorphic_adapter.html) |
| 1 | **RafCamera custom: 76 mm ID clamp → M82×0.75 male** | Same job as the M77 collar, one step up. | [RafCamera custom](https://rafcamera.com/custom-adapter) |

2× cinema (5.42:1). **Bought:** ISCO Ultra-Star **HD Cinemascope attachment**
(the large gold/orange cylinder). Unscrew the red **HD Plus** spherical
(`f=xx mm`, marked **1.85**) — threads are often glued; tap the joint, do
**not** undo the ring of six screws. Keep only the front piece. Caliper its
**rear tube** before you order the clamp: this unit is the US turret —
**70.6 mm** rear tube, **67 mm** rear thread OD (KuSeRa lists **~72 mm**
tube / **~68 mm** thread for other batches).

| Qty | Item | Why | Link |
|-----|---|-----|---|
| 1 | **ISCO Ultra-Star HD Cinemascope attachment** | Owned. 2× afocal, **70.6 mm** rear tube / **67 mm** rear thread (US turret). 180 mm pupil is 32 mm so coverage is the easy case. Theater focus (often 5–150 m) is fine at 50 m. | (bought) |
| 1 | **RafCamera 71 mm clamp → M77×0.75 male** | **This unit.** Clamp ID 70.65, made for Cinelux / US turret. | [71 mm / M77 M](https://rafcamera.com/clamp-71mm-to-m77x0-75m) |
| *or* 1 | **RafCamera custom: 72 mm clamp → M77×0.75 male** | Only if a different batch measures **72 mm** rear tube. | [custom](https://rafcamera.com/custom-adapter) |
| 1 | **RafCamera 76 mm clamp → M77×0.75 female** | On the 180. Measure `EL180_LENS_OD` first. Then: 180 → 76 mm clamp → M77 → attachment clamp. | [76 mm / M77 F](https://rafcamera.com/clamp-76mm-to-m77x0-75f-od80mm) |
| 1 | **1/4-20 support** (15 mm rod from the chassis, or a ~77–90 mm collar) | This one is a kilo. Hang it off the chassis **1/4-20**, not the M62 helicoid. Compact Iscorama brackets (**1101470** / **1103882**) will not fit the 90 mm front. | rail from the box 1/4-20 |

Compact Gold / Studio / Red (~52.5 mm rear) and Kowa 16-H / 8-Z are the
small 2× class. Not this build. Hang any adapter off the chassis **1/4-20**,
not the M62 helicoid — a kilo of glass on the printed boss is how it fails.

## Cameras and sync

| Qty | Item | Why | Link |
|-----|---|-----|---|
| 2 | **Nikon D800** bodies, no lenses | 36 × 23.9 mm, 7360 × 4912, 46.5 mm register. Both sit **upright and landscape** — the seam is horizontal and `cam/pano.py` requires it. | (you have these) |
| 1 | **10-pin dual release** | The D800 uses the **10-pin** remote terminal, not MC-DC2 — a lead from the D7000 bodies will not fit. Both shutters have to fire together or the stitch tears on anything moving. | [10-pin Y splitter](https://www.ebay.com/sch/i.html?_nkw=nikon+10+pin+dual+camera+shutter+release) · [MC-30A](https://www.amazon.com/s?k=Nikon+MC-30A) |

`cam/` is D7000 USB only. Fire the D800s from the 10-pin lead and pull the
files afterwards.

## Print and hardware

| Qty | Item | Why | Link |
|-----|---|-----|---|
| ~1.5 spool | **PETG or ABS**, dark | Chassis, lid, tray, arms, stem, base, cradles. Not PLA — the M52 mouths and the cookie screws both see real load, and a 1 kg body hanging on a brittle mouth is how you break a D800. | [Amazon PETG](https://www.amazon.com/s?k=PETG+filament+1.75) |
| scraps | 4 accent colours | Only if you want the FXPAN badge in filament rather than paint: gold (FX), off-white (PAN), red (outline + stripe), grey (spec). A few grams each. | — |
| 12 | **M3 × 12 countersunk** (DIN 7991) + 12 **M3 nuts** | Port cookies, 4 per cookie into wall nut traps — two above the bore, two below. Three cookies: stem, arm R, arm T. Countersunk, not cap head: there is no wall outboard of a cookie any more, so its face is the outside of the camera and the D800 comes right up to it. | [M3 screws](https://www.amazon.com/s?k=M3+socket+head+cap+screw+assortment) · [M3 nuts](https://www.amazon.com/s?k=M3+hex+nuts) |
| 2 | **M3 × 20** + 2 **M3 nuts** | Lid to chassis, at the two +Y corners. Nuts slide into the slots from the chamber before the tray goes in; the tray closes them. | as above |
| 8 | **M3 × 16–20** + 8 **M3 nuts** | Cradle to base, 4 per cradle. Heads sink into the plinth top, nuts sit under the base. | as above |
| 4 | **M3 × 6 grub screws** + 4 **M3 nuts** | Two per arm mouth, pinching the reverse-ring barrel. These hold your **roll alignment** — without them the ring can creep and one camera's horizon walks off the other's. The nuts sit in lugs *outboard* of the M52 thread rather than in pockets cut through it, and go in from the mouth end before the ring does; the ring's flange then closes over them. Headless, because the lug face is inside the space the D800's front panel occupies. | [M3 set screws](https://www.amazon.com/s?k=M3+set+screw+kit) |
| 2 | **1/4-20 heat-set insert, short 6.4 mm** | One in the chassis floor pad, one in the base tripod pad. Ø8.1 mm wells. Iron in **from the bed face** and leave the 1.2 mm keep so they stay blind. | [CNC Kitchen 1/4-20×6.4](https://cnckitchenus.store/products/heat-set-insert-1-4-20x6-4-camera-thread-short-version-20-pieces) · [Amazon](https://www.amazon.com/s?k=1/4-20+heat+set+insert) |
| 1 | **1/4-20 knurled thumbscrew** | Chassis onto the base origin pad, through the Ø24 mm counterbore. Hand-tight, no tool. | [1/4-20 camera thumbscrew](https://www.amazon.com/s?k=1%2F4-20+camera+thumbscrew+knurled) |
| 2 | **1/4-20 × 25 mm** | Up through the base slot and the cradle slot into each body's tripod socket. 18 mm of printed stack plus ~6 mm into the camera — **check the depth on your own bodies before you crank it down.** | [1/4-20 camera screw](https://www.amazon.com/s?k=1%2F4-20+camera+screw) |
| 1 | **1/4-20 tripod screw** | Into the base insert at the combined centre of mass. Tripod goes there, **not** in the chassis. | as above |
| 1 sheet | **Flocking paper** or flat black paint | Chamber, tray faces, arm bores, and the F throats. The throats matter most: they are deliberately **unlined**. The throat is the tightest aperture in the body — 1.3 mm clear of the frame corners even at f/11 — so a 1.6 mm liner in there would vignette outright. | [camera flocking paper](https://www.amazon.com/s?k=camera+flocking+paper) |
| 2 | **TPU or cork pads**, ~1 mm | Optional, on the bare cradle tops so a body cannot creep on the plinth. Cut from sheet. | [cork sheet](https://www.amazon.com/s?k=2mm+cork+sheet+adhesive) |

## Print-only alternatives

Both of these work and both cost you something. Neither is the recommended
build.

| Part | Instead of | What it costs |
|---|---|---|
| `stem_el180_inf` | the M62 helicoid + short `stem` | One-piece cookie, 17.5 mm boss, 180 flange at infinity. **No focus travel.** Female M62 in the outer 8 mm. Same path as the helicoid at 17.5 mm, so it tracks `BOX_XY`. Print a second at +0.5 mm if the first lands long; shims can only add. |
| `m65_ring` | the flangeless M65→M62 ring, until it arrives. **EL-Nikkor only.** | Adds **8 mm**. Collapsed focus is about 4.5 m. Print `stem_m65` with it. |
| `stem_nw_m65` | the M62 Nikkor-W nose, on the M65 helicoid | Same Copal board, M65 male, **0 mm** added. Do not put the W on `m65_ring`. |
| `el180_adapter` | the M62 helicoid, keeping short `stem` | Two-piece stand-in: printed male into the 8 mm boss. Prefer `stem_el180_inf`. |
| `arm_r_f` / `arm_t_f` (`ARM_MOUNT = 1`) | the 52 mm reverse rings | Archive-663 male F. The lip is the mesh as shipped (40 mm). Plastic lugs still should not carry a D800 — the cradles take the weight. Dry-fit clocking with `F_MOUNT_CLOCK`. |
| `arm_r_focus` | `arm_r_fw`, and the R helicoid on the Nikkor-W | Same printed F and the same R cookie as `arm_r_fw`, including the W 8 mm, then 0.77 mm shorter so the bayonet is in focus when `arm_t_fw` is. Stamped `fxp_rw_focus`. |
| `arm_r_wl` / `arm_t_wl` | the camera helicoids, focusing the Nikkor-W on its M65 lens helicoid | Printed F, no rings and no camera helicoids. Registers 23.00 (R) and 22.62 (T): T from the field infinity on `stem_nw_direct` less the 16.58 mm lens helicoid, R from where the first prints peaked on the lens helicoid. Use with `stem_m65` + M65 helicoid + `stem_nw_m65`. |
| `arm_r_hw` / `arm_t_hw` | `arm_r_focus` / `arm_t_fw` and the shims | Nikkor-W. Needs the **M52-female / M42-male 17–31 helicoid** above and a **metal M52-to-F ring**, two of each. Cookie is the M42 female. The male's tip bottoms on a lip in the cookie; the body floats 0.4 mm off the face. On the measured 1.93 mm ring, collapsed is 25.51: R dials out 1.72 to focus, T 2.19. |

## Export

```
./export_fxpan.sh              # 35 STLs -> stls/fxpan/
./export_fxpan.sh chassis lid  # just these
```

Wraps `./export_stls.sh --fxpan`. Each part is stamped `fxp_<name>` plus the
render minute, so a part on the bench can always be traced to the export that
made it.

Print list and bed orientations: [README.md](README.md#print-list).

To check the optics rather than trust this file:

```
pip install -r ../../kraken/requirements.txt
python ../../kraken/fxpan_paths.py
```

It ray traces the body and exits non-zero if the stitch, the shift senses or
the apertures stop matching `params.scad`.

## Notes

- **f/5.6 is usable.** The extreme corners sit at 0.84 of full illumination
  and the long axis stays at 1.00, so it reads as a mild shade. f/8.4 is
  where the last corner ray clears the 44 mm mouth. That number is the
  mount, not the Nikkor-W.

- **S1 faces the lens** — the face with the black dot. Backwards puts the glass path on the
  reflect leg while the T arm's 0.303 mm compensation is still shortening the
  transmit leg — both legs then disagree by 0.6 mm and no shim stack fixes it
  cleanly.
- **Do not swap the arms.** T (+Y, straight back) is shorter than R (+X) by
  `bs_t_comp = 0.303 mm`. Flanges are engraved **▲ R** and **▲ T**. There is
  no tube toe on this body — each bore is translated 14.4 mm instead of tilted,
  so the arrow is for identification, not aiming.
- **The plinth carries, the bayonet locates.** A D800 is about 1 kg. Every
  printed F mount in this project is a weak point when it takes load; here it
  should never feel any. The cradles have no uprights — the bayonet fixes yaw
  far better than a 46 mm-wide flange could, and an upright would only stand
  in the way of bringing the body in and twisting it on.
- **This body's bore is not the others'.** `TUBE_ID` 46 and `F_BORE` 44.0
  against 52 and 40.3 elsewhere. Arms, stem and cookies are not
  interchangeable with `hybrid_shift` parts even where they look similar —
  which is why everything is stamped `fxp_`.
- **20.4° horizontal.** XPan's aspect ratio, not XPan's angle of view. 65 mm
  at 180 mm of focal length is a telephoto panorama. A 1.5× adapter on the
  front of the 180 takes that to 30.1° / 4.07:1 without touching the path.
- The two 50 mm first-surface mirrors are not used here. Keeping the stitch
  axis off every fold's foreshortened dimension forces all folds coplanar, and
  coplanar folds cannot make two bodies parallel. They stay with the V body.

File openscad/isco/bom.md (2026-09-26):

# Bill of materials — ISCO clamps

Hardware for the printed (or CNC) collars in
[`isco_mount.scad`](isco_mount.scad). Assembly notes:
[`clamps.md`](clamps.md).

You need **one** taking-lens clamp (M62, Nikkor-W, or EF 100L) plus the ISCO
attachment itself. The bench stand is optional.

## Taking lens (pick one path)

| Qty | Item | Clamp | Why | Link |
| --- | --- | --- | --- | --- |
| 1 | **EL-Nikkor 180 mm f/5.6N** | M62 | External **M62×1** on the front barrel, Ø76 shoulder behind the thread. | [eBay EL-Nikkor 180](https://www.ebay.com/sch/i.html?_nkw=el-nikkor+180mm+f%2F5.6) |
| *or* 1 | **Nikkor-W 180 mm f/5.6** (Copal No. 1) | Nikkor-W | **Ø73** barrel land, **1.1 mm** groove at the shutter, **M67×0.75** filter. FFD **178.8 mm** on the FXPAN helicoid stack. | [eBay Nikkor-W 180](https://www.ebay.com/sch/i.html?_nkw=nikkor-w+180mm+f%2F5.6) |
| *or* 1 | **Canon EF 100mm f/2.8L Macro IS USM** | EF 100L | Female **67 mm** filter. Max Ø77.7 × 123 mm. Hood **ET-73** comes off. | [Canon EF 100L Macro](https://www.usa.canon.com/shop/p/ef-100mm-f-2-8l-macro-is-usm) |

## ISCO attachment

| Qty | Item | Why | Link |
| --- | --- | --- | --- |
| 1 | **ISCO Ultra-Star HD Cinemascope attachment** | 2× afocal front piece from the HD Plus turret. **Ø70.6 mm** rear tube, **Ø67 mm** rear thread (US turret — caliper yours). | (bought) |

Caliper the rear tube before you trust the clamp ID. RafCamera lists
**71 mm** clamps for this batch; the model uses **71.0 mm** ID on the ISCO
collar and **73.4 mm** on the Nikkor-W land.

## Clamp body (pick one)

| Qty | Item | Why | Link |
| --- | --- | --- | --- |
| 1 | **`isco_clamp`** | EL-Nikkor path. ~115 × 84 × 38 mm. | Print [`stls/isco/isco_clamp.stl`](../../stls/isco/isco_clamp.stl) or CNC [`sendcutsend/isco_clamp.step`](sendcutsend/isco_clamp.step) |
| *or* 1 | **`isco_clamp_nw`** | Nikkor-W path. ~117 × 84 × 64 mm, dual collar. | Print [`stls/isco/isco_clamp_nw.stl`](../../stls/isco/isco_clamp_nw.stl) or CNC [`sendcutsend/isco_clamp_nw.step`](sendcutsend/isco_clamp_nw.step) |
| *or* 1 | **`isco_clamp_ef100`** | EF 100L path. Male M67×0.75 into the filter, ISCO collar in front. | Print [`stls/isco/isco_clamp_ef100.stl`](../../stls/isco/isco_clamp_ef100.stl) |

**Print:** PETG, ABS, or PCTG, 40%+ infill, ears up, inserts from the top
face. See [`clamps.md`](clamps.md).

**CNC:** STEP bores are plain cylinders — tap **M62×1** on the EL clamp
yourself if you cut metal.

## Fasteners

| Qty | Item | M62 | W | EF | Why | Link |
| --- | --- | ---: | ---: | --- | --- |
| — | **M3 heat-set insert, 4 mm × 5 mm** | 4 | 8 | 4 | Ø4 × 5 mm long. Press into the +Y ear face; the bore is through for the screw. (6×5 and 8×5 are too wide for the 16 mm ears.) | [M3 heat-set inserts](https://www.amazon.com/s?k=M3+heat+set+insert) |
| — | **M3 × 12–14 mm socket cap** | 4 | 8 | 4 | Close the split collars — ISCO only on the M62 and EF clamps; lens + ISCO on the W. | [M3 screw kit](https://www.amazon.com/s?k=M3+socket+head+cap+screw+assortment) |

## Bench stand (optional)

| Qty | Item | Why | Link |
| --- | --- | --- | --- |
| 1 | **`isco_stand`** | Cradle under the Ø90 barrel at 70 mm axis height. | [`stls/isco/isco_stand.stl`](../../stls/isco/isco_stand.stl) · [`sendcutsend/isco_stand.step`](sendcutsend/isco_stand.step) |
| 1 | **1/4-20 heat-set insert, 6.4 mm** (Ø8.1 well) | Tripod foot, same as the FXPAN chassis. | [CNC Kitchen 1/4-20×6.4](https://cnckitchenus.store/products/heat-set-insert-1-4-20x6-4-camera-thread-short-version-20-pieces) |
| 1 | **1/4-20 tripod screw** | Into the foot insert. | [1/4-20 camera screw](https://www.amazon.com/s?k=1%2F4-20+camera+screw) |

## Not on this clamp

| Item | Why |
| --- | --- |
| RafCamera 71 mm → M77 collar | Bought adapter path for the EL-180 when you are **not** printing this clamp. See [`../fxpan/bom.md`](../fxpan/bom.md). |
| M62 helicoid / FXPAN stem | In-body focus for the Nikkor-W — separate from this bench clamp. |
| 1/4-20 chassis support for the ISCO mass | On the FXPAN body, hang the kilo off the **chassis** insert, not the printed stem boss. |

## Export

```bash
./export_stls.sh --isco isco_clamp isco_clamp_nw isco_stand
```

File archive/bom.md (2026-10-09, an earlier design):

# Bill of materials — Nikon Dual T

Path target: **PATH_TOTAL ≈ 173.5 mm** with current defaults (`D_LENS_TO_KNIFE=55`, `D_KNIFE_TO_MOUNT=72`). See [OPTICS.md](OPTICS.md). Buy **first-surface** mirrors only.

## Optics (order these)

| Qty | Item | Why | Link |
|-----|---|-----|---|
| 2 | **50×50 mm first-surface mirror** (enhanced Al or protected Ag) | Field splitter at 45° | [Edmund 50×50 mm Silver 4–6λ](https://www.edmundoptics.com/p/50-x-50mm-silver-4-6lambda-mirror/31994/) · cheaper DIY: [Amazon “first surface mirror” search](https://www.amazon.com/s?k=first+surface+mirror+50mm) · craft sheet to cut: [Amazon 6×8" front surface sheet](https://www.amazon.com/s?k=front+surface+mirror+6x8) |
| 1 | **M42–M42 focusing helicoid** (12–19 mm) | Fine focus on stem | [Fotasy 12–19 mm](https://www.amazon.com/Fotasy-Helicord-Focusing-Helicoid-Extention/dp/B01N5V1QAC) · [Pixco 12–19 mm](https://www.amazon.com/Pixco-Adjustable-Focusing-Helicoid-Shooting/dp/B01IGGQR7Y) |
| 1 | **Longer M42 helicoid or M42 extension tubes** (optional stack) | Extra travel if infinity is short | [Amazon M42 helicoid 25–55](https://www.amazon.com/s?k=M42+focusing+helicoid+25-55) · [M42 extension tube set](https://www.amazon.com/s?k=M42+extension+tube+set) |
| 1 | **M39→M42 adapter** (if using enlarger lens) | Enlarger lenses are often M39 | Printed `elnikkor_adapter` (L39×26 TPI) for the El-Nikkor 50/2.8 Japan, or [Amazon M39 to M42](https://www.amazon.com/s?k=M39+to+M42+adapter) |
| 1 | **El-Nikkor 50 mm f/2.8** (you have this) | Stand-in taking lens — close-up only on this path | Rear is **L39 × 26 TPI**. Print `elnikkor_adapter`. |

## Cameras / sync

| Qty | Item | Link |
|-----|---|---|
| 2 | Nikon D7000 bodies (no lenses) | (you have these) |
| 2 | **Fotodiox Nikon F reverse ring, 52 mm** | [Fotodiox reverse adapter](https://www.amazon.com/Fotodiox-Reverse-Adapter-Compatible-Cameras/dp/B001G4NBSC) (pick **52 mm**; screws into the printed 52×0.75 mouths) |
| 1 | MC-DC2-compatible remote | [Kiwifotos MC-DC2](https://www.amazon.com/Kiwifotos-MC-DC2-Remote-Shutter-Release/dp/B071D9Y331) |
| 1 | Dual-camera sync path | Prefer [FlashZebra #0236](http://flashzebra.com/products/0236/) (2.5 mm TRS, splitter-ready) + [FlashZebra #0216](https://flashzebra.com/products/0216/index.shtml) Y (or Amazon [MyCableMart 3-conductor](https://www.amazon.com/dp/B0C7WHDT5P) / [Wideskall 2.5 mm stereo](https://www.amazon.com/dp/B01CRXGEDY)) + **2×** 2.5 mm→DC2 pigtails ([LGSHOP N10-DC2](https://www.amazon.com/dp/B076FV2WDB) · [HAPPYTOPSTAR](https://www.amazon.com/dp/B08ZJ3GD7T)). Must be **2.5 mm TRS (3-pole)**, not 3.5 mm and not 4-pole TRRS. |
| 1 | 10.1″ Pi HDMI touch (HAMTYSAN HCIK101V.CC) | Field UI. Ghost + drawings in [`docs/monitor/`](../docs/monitor/). | [Amazon B0B9M5SCG4](https://www.amazon.com/dp/B0B9M5SCG4) |

## Print / hardware
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

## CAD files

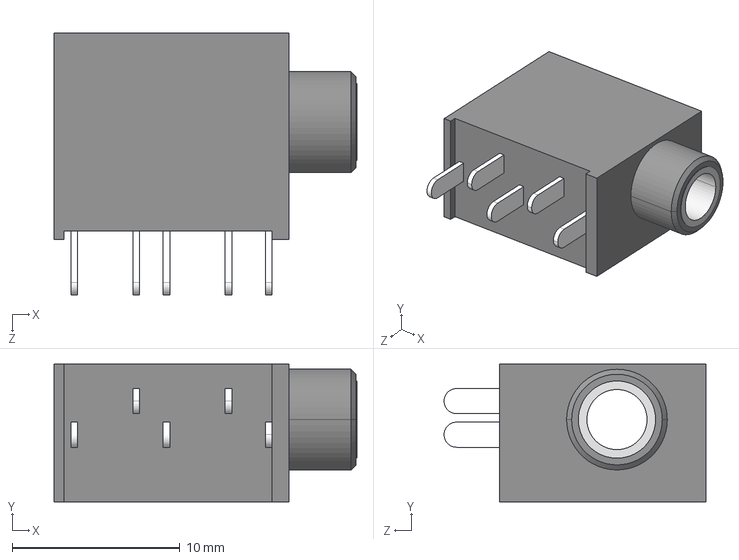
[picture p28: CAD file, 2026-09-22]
gpio_trigger/kicad/3d/SJ1-3535NG.step
18.1 x 8.20 x 15.6 mm

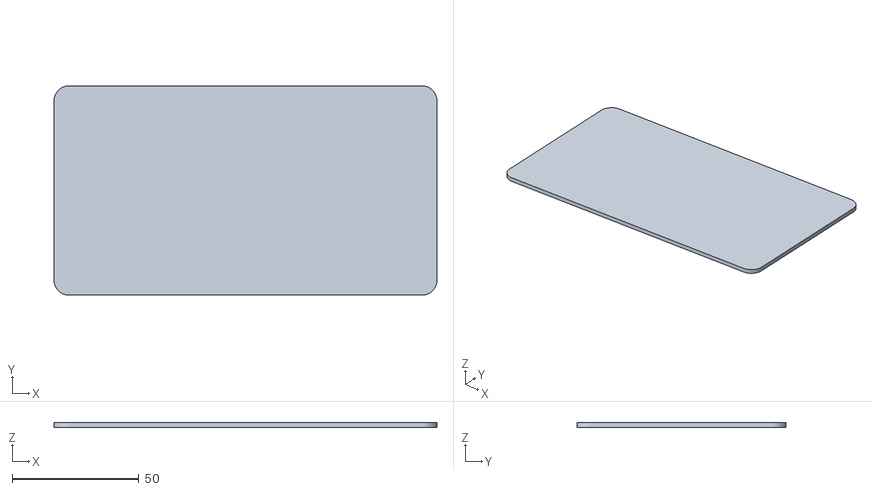
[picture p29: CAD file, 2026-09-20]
logos/fxpan_backer_optional.stl
151.4 x 82.8 x 2.00

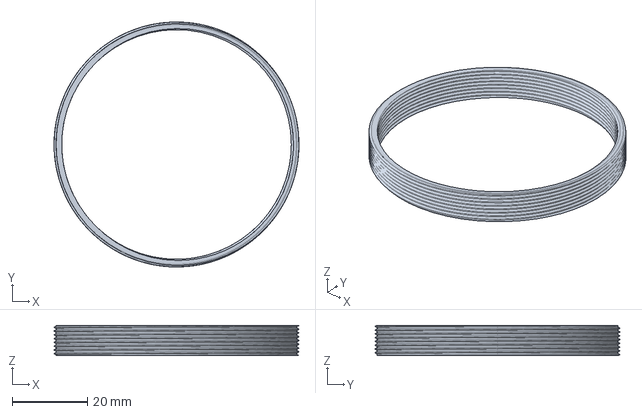
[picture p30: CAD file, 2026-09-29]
openscad/fxpan/sendcutsend/m65_m62_flangeless.step
65.0 x 65.0 x 8.00 mm

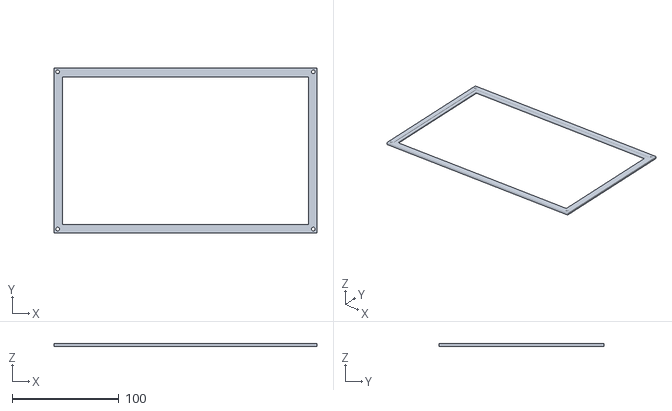
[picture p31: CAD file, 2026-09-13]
openscad/monitor/bezel.stl
246.1 x 154.0 x 2.48

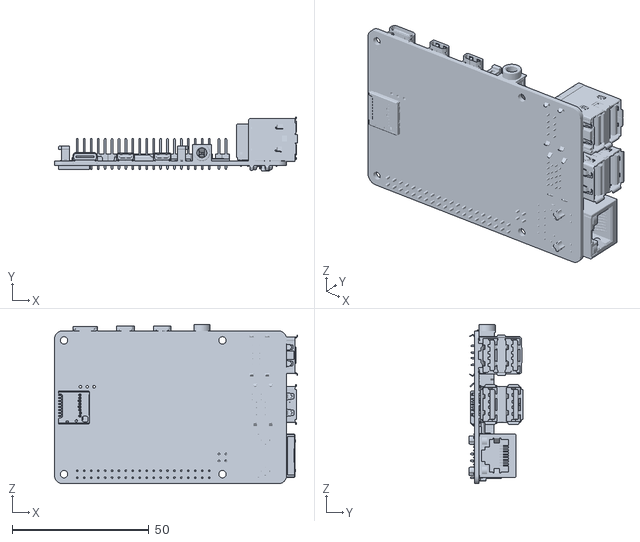
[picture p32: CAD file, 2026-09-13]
openscad/pi4_body.stl
89.0 x 19.9 x 58.4

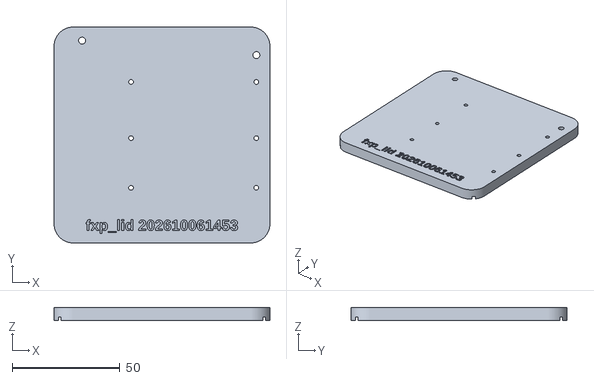
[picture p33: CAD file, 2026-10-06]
stls/fxpan/lid_outer.stl
100.0 x 100.0 x 6.00

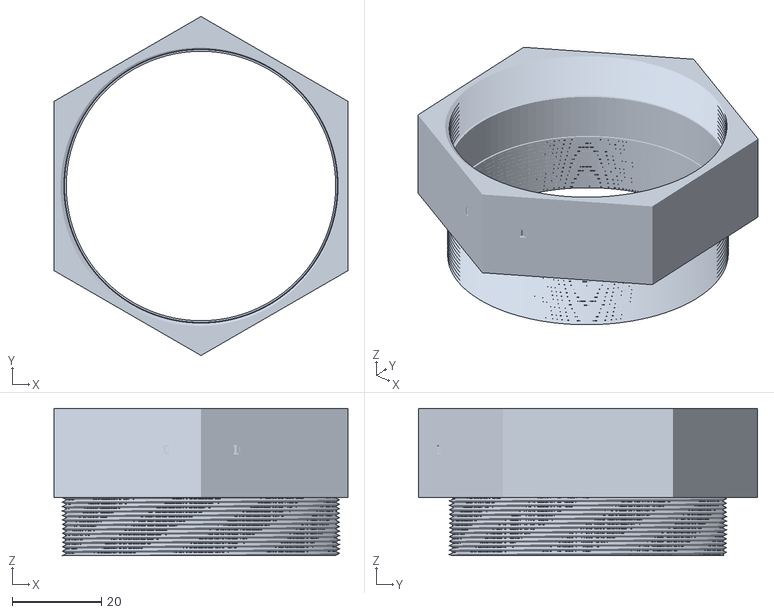
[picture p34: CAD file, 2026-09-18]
stls/hybrid_shift/el180_adapter.stl
65.8 x 76.0 x 33.0

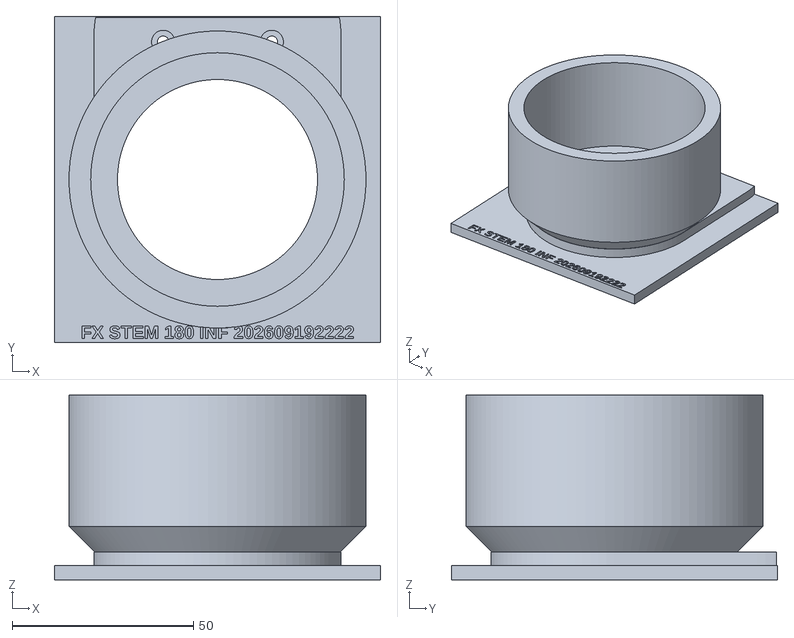
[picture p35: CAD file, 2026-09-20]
stls/hybrid_shift_fx/stem_el180_inf_outer.stl
90.0 x 90.0 x 51.0

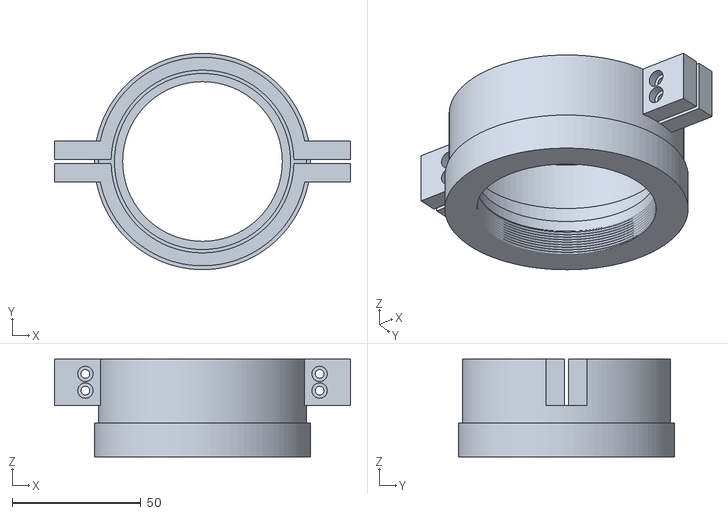
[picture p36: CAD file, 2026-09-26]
stls/isco/isco_clamp.stl
115.0 x 84.0 x 38.0

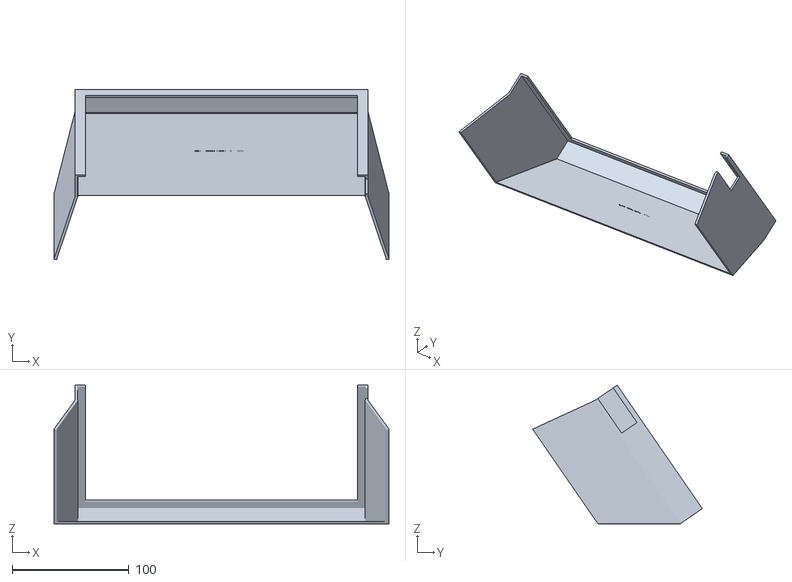
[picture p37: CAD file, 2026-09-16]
stls/monitor/sunshade.stl
286.9 x 145.3 x 118.8

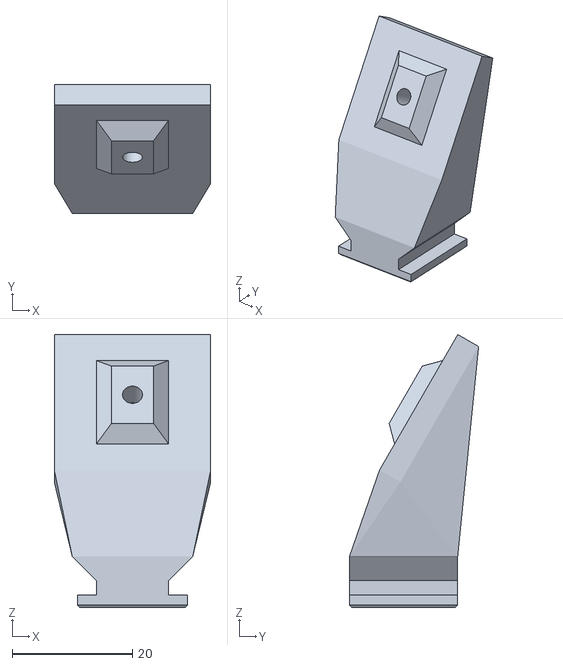
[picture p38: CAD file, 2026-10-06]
stls/phone/pm17_shoe.stl
26.0 x 21.5 x 45.4

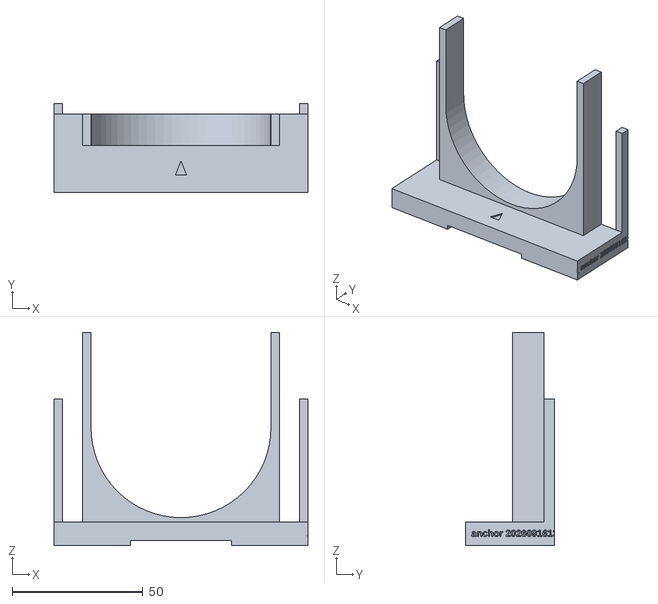
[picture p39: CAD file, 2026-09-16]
stls/tools/focus_anchor.stl
97.0 x 34.0 x 81.3

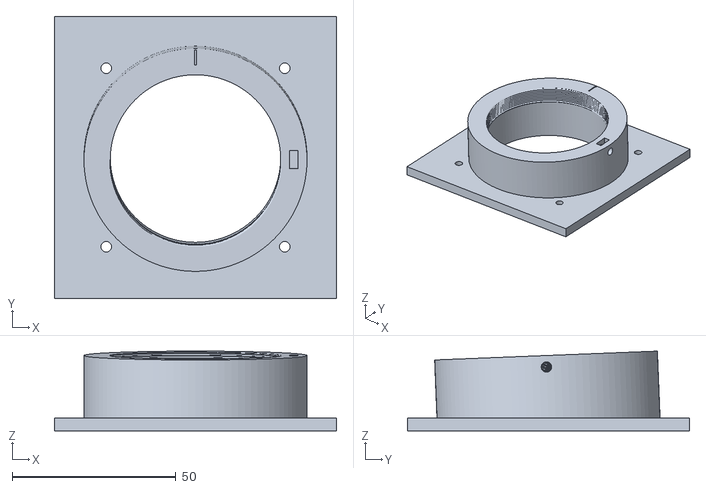
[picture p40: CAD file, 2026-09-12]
stls/v/arm_l.stl
86.0 x 86.0 x 24.3

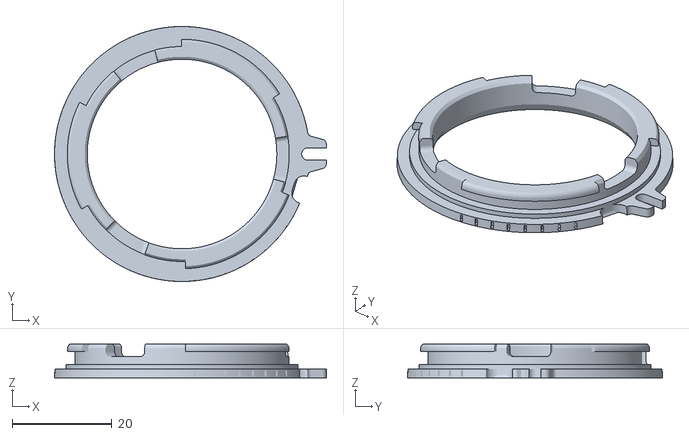
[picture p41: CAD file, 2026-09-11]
f-mount_raw.stl
54.5 x 51.2 x 6.75

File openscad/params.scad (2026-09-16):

// Nikon Dual T — shared parameters
// Optical path: P = D_LENS_TO_KNIFE + D_KNIFE_TO_MOUNT + FLANGE_F

FLANGE_F = 46.5;          // mm, D7000 internal mount→sensor (fixed)

// Field-splitter fold — arms long enough that F-mounts sit clear of the box
D_LENS_TO_KNIFE  = 55;    // helicoid register → knife
D_KNIFE_TO_MOUNT = 72;    // knife → camera F-mount register face
PATH_FOLD        = D_LENS_TO_KNIFE + D_KNIFE_TO_MOUNT;
PATH_TOTAL       = PATH_FOLD + FLANGE_F;  // ~173.5 mm

// Stitch overlap: each camera looks across the knife by this fraction of
// a D7000 frame. Glasses cross past the axis by the same field mapped to
// the knife. Tune OVERLAP_FRAC; 0.20 ≈ 4.7 mm / ~1000 px on each body.
SENSOR_W      = 23.6;
OVERLAP_FRAC  = 0.20;
function path_after_knife()   = D_KNIFE_TO_MOUNT + FLANGE_F;
function overlap_at_sensor()  = SENSOR_W * OVERLAP_FRAC;
function overlap_cross()      = overlap_at_sensor() * path_after_knife() / PATH_TOTAL;
function arm_toe()            = atan(overlap_at_sensor() / path_after_knife());

// First-surface mirrors
MIRROR_SIZE   = 50;
MIRROR_THICK  = 3;
MIRROR_CLEAR  = 0.4;

// Junction / tubes
TUBE_ID       = 52;
TUBE_OD       = 68;
WALL          = (TUBE_OD - TUBE_ID) / 2;
JUNCTION_BOX  = 90;

// Detachable ports: flange + tube, print flange on the bed, bolt onto the flat wall
PORT_PATCH     = 86;      // flange square (sits on the face, no wall pocket)
PORT_PATCH_T   = 4;       // flange thickness
PORT_SCREW_R   = 38.5;    // 4× M3 at 45° so adjacent faces do not share a corner
PORT_SCREW_D   = 3.2;
PORT_NUT_AF    = 5.7;     // M3 hex, across flats
PORT_NUT_T     = 2.6;     // hex trap in the inner wall (no chamber boss)

// Helicoid stem (M42×1)
HELICOID_MAJOR = 42;
HELICOID_PITCH = 1.0;
HELICOID_LEN   = 28;
HELICOID_TOL   = 0.45;    // ScrewHole extra clearance for FDM
STEM_FLANGE_T  = 6;

// Temporary El-Nikkor 50/2.8 (Japan): rear is Leica L39 × 26 TPI, not M39×1.
// Printed ring: male M42 into the stem / helicoid, female L39 for the lens.
// 50 mm will not reach infinity on PATH_TOTAL — close-up only until a longer lens.
EL_M39_MAJOR   = 39;
EL_M39_PITCH   = 25.4 / 26;
EL_M39_LEN     = 6;
EL_M39_TOL     = 0.45;
EL_M42_LEN     = 7;
EL_ADAPTER_HEX = 4;
EL_ADAPTER_OD  = 50;
EL_BORE        = 34;

// Fotodiox-style Nikon F reverse ring: male F-bayonet + male 52 mm filter
// thread. ARM_MOUNT=0 arms are female M52×0.75; the ring screws on, bodies
// bayonet on. ARM_MOUNT=1 prints the bayonet on the tube (no ring).
// ISO 60°: male major 52.000, pitch 0.750, pitch Ø 51.513, minor 51.080.
// Female cut = difference(ScrewThread) at F_REV_MAJOR; inner PETG owns it.
// https://www.amazon.com/Fotodiox-Reverse-Adapter-Compatible-Cameras/dp/B001G4NBSC
F_REV_MAJOR    = 52.0;    // M52×0.75 mating male major (mm)
F_REV_PITCH    = 0.75;
F_REV_LEN      = 8;       // female thread length in the tube wall
F_REV_STACK    = 8;       // ring seat → F-register
F_REV_TOL      = 0.12;    // PETG female clearance (ScrewThread adds 0.25×tol)
F_BORE         = 40.3;
F_FMOUNT_STACK = 1.75;    // printed bayonet back → F-register (f-mount_raw.stl)
F_REGISTER_T   = F_REV_STACK;


// 1/4-20 heat-set in the chassis floor (print floor on the bed).
// CNC Kitchen short camera insert: 1/4-20 × 6.4 mm, hole Ø8.1.
TRIPOD_INSERT_D = 8.1;
TRIPOD_INSERT_L = 6.4;
TRIPOD_KEEP     = 1.2;
function tripod_hole_h() = min(WALL - TRIPOD_KEEP, TRIPOD_INSERT_L + 1.0);

SHIM_RANGE     = 2.0;
SHIM_STEPS     = [0.2, 0.5, 1.0];

BODY_W = 132;
BODY_H = 105;
BODY_D = 77;

$fn = 96;
EXPLODED = 0;             // 1 = pull arms + lift mirror cartridges for drop-in view
SHOW_LID = 0;             // 0 = hide lid so you can see mirrors / grooves
SHOW_GHOSTS = 0;
SHOW_CRADLES = 0;
PART = is_undef(PART) ? "assembly" : PART;  // assembly | chassis | stem | arm_l | arm_r | lid | mirror_tray | shims | elnikkor_adapter | f_mount

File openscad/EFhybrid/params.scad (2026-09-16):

// Canon Dual — hybrid pano L (toed FF + one 50/50 plate)
// 5D Mark III bodies, EF mount. Each FF body is aimed at a different
// half of a ~64.8 mm image (sensor_shift / field_toe). That is the panorama.
// One uncut 50×50 plate at the origin: R → +X, T → +Y.
// https://www.edmundoptics.com/p/50-x-50mm-50r50t-plate-beamsplitter/4985/

FLANGE_F = 44.0;          // Canon EF register

D_LENS_TO_PLATE  = 55;
D_PLATE_TO_MOUNT = 72;
PATH_FOLD        = D_LENS_TO_PLATE + D_PLATE_TO_MOUNT;
PATH_TOTAL       = PATH_FOLD + FLANGE_F;

// 5D Mark III
SENSOR_W      = 36.0;
SENSOR_H      = 24.0;
OVERLAP_FRAC  = 0.20;
function path_after_knife()   = D_PLATE_TO_MOUNT + FLANGE_F;
function overlap_at_sensor()  = SENSOR_W * OVERLAP_FRAC;
function overlap_cross()      = overlap_at_sensor() * path_after_knife() / PATH_TOTAL;
function sensor_shift()       = SENSOR_W / 2 * (1 - OVERLAP_FRAC);
function field_toe()          = atan(sensor_shift() / path_after_knife());
function stitch_w()           = SENSOR_W * (2 - OVERLAP_FRAC);

BS_SIZE    = 50;
BS_THICK   = 1.0;
BS_CLEAR   = 0.35;
BS_N       = 1.52;
function bs_t_comp() =
    let (ti = 45, tt = asin(sin(ti) / BS_N))
        BS_THICK * (BS_N / cos(tt) - 1 / cos(ti));

TUBE_ID       = 52;
TUBE_OD       = 68;
WALL          = (TUBE_OD - TUBE_ID) / 2;
JUNCTION_BOX  = 90;

PORT_PATCH     = 86;
PORT_PATCH_T   = 4;
PORT_SCREW_R   = 38.5;
PORT_SCREW_D   = 3.2;
PORT_NUT_AF    = 5.7;
PORT_NUT_T     = 2.6;

HELICOID_MAJOR = 42;
HELICOID_PITCH = 1.0;
HELICOID_LEN   = 28;
HELICOID_TOL   = 0.45;
STEM_FLANGE_T  = 6;

EL_M39_MAJOR   = 39;
EL_M39_PITCH   = 25.4 / 26;
EL_M39_LEN     = 6;
EL_M39_TOL     = 0.45;
EL_M42_LEN     = 7;
EL_ADAPTER_HEX = 4;
EL_ADAPTER_OD  = 50;
EL_BORE        = 34;

// Female 58×0.75 in the tube mouth — Canon EF reversing ring.
EF_REV_MAJOR    = 58.0;
EF_REV_PITCH    = 0.75;
EF_REV_LEN      = 8;
EF_REV_STACK    = 8;
EF_REV_TOL      = 0.12;

// Printed male EF (camera bayonets on). Wiki: 54 throat / 65 OD / 44 flange.
EF_THROAT       = 54.0;
EF_BORE         = 54.0;
EF_FLANGE_OD    = 61.0;
EF_LUG_OD       = 65.0;
EF_LUG_T        = 1.8;
EF_LUG_SWEEP    = 48;
EF_REGISTER_T   = 2.0;
EF_FMOUNT_STACK = EF_REGISTER_T;

// 1/4-20 heat-set in the chassis floor (print floor on the bed).
// CNC Kitchen short camera insert: 1/4-20 × 6.4 mm, hole Ø8.1.
TRIPOD_INSERT_D = 8.1;
TRIPOD_INSERT_L = 6.4;
TRIPOD_KEEP     = 1.2;
function tripod_hole_h() = min(WALL - TRIPOD_KEEP, TRIPOD_INSERT_L + 1.0);

SHIM_STEPS = [0.2, 0.5, 1.0];

// 5D Mark III CIPA body, no battery grip
BODY_W = 152.0;
BODY_H = 116.4;
BODY_D = 76.4;

$fn = 96;
EXPLODED = 0;
SHOW_GHOSTS = 0;
PART = is_undef(PART) ? "assembly" : PART;
// assembly | chassis | stem | arm_r | arm_t | lid | hybrid_tray | shims | elnikkor_adapter

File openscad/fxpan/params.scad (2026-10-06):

// Nikon Dual — FXPAN 65: two D800 behind one EL-Nikkor 180/5.6 and a
// 50×75×1 50/50 plate. 64.80 × 23.9 mm stitch, 2.711:1 (XPan is 2.708:1),
// 13248 × 4912 = 65.1 MP. Infinity inside the helicoid's travel, and the
// frame corner-to-corner clean from f/8.4.
// Lens −Y. Plate at the origin: R → +X, T → +Y. No tube toe.
// https://www.edmundoptics.com/p/50-x-75mm-50-50rt-vis-plate-beamsplitter/37201/
//
// Four things drive every number here, and they pull against each other.
// kraken/fxpan_paths.py ray traces all of it and fails loudly if any of these
// stops holding.
//
// 1. A plate tilted 45° presents only size/√2 across its plane of incidence,
//    and cam/pano.py needs landscape sensors with a horizontal seam, so the
//    wide stitch axis is forced onto exactly that foreshortened dimension.
//    The 65 mm frame needs 44.4 mm there at f/5.6, so BS_W has to be 75:
//    53.03 presented, a 19% margin that grows as you stop down. 50 there
//    gives 35.36 and clips the stitch axis until f/11.
//
// 2. The F throat has to pass the frame CORNERS, and mostly can't — this is
//    the constraint that actually limits the body. 44 mm is the real Nikon F
//    throat and no printed part beats it, against the 46.8 mm the corners
//    need at f/5.6. So the frame is fully lit from f/8.4, not f/5.6; wide of
//    that the corners shade while the stitch axis stays clean. See need_bore()
//    for why this must be worked at the corner and not along the stitch axis.
//
// 3. PATH_TOTAL — lens flange to sensor along the fold — has to land on the
//    EL-Nikkor's 158.5 mm flange focal distance. 180 mm is the focal length,
//    used for the bundle, not the register. The seats are recessed into the
//    lens wall and the camera cookies sit CAM_RECESS deeper, so the path is
//    the seat position plus the shortened camera stack, not a boss standing
//    on the skin. BOX_Z carries BS_H and nothing else; BOX_XY stays on the
//    port floor. Shrinking it does not reach the register.
//
// 4. A D800 is not flat at its flange. Its front panel stands D800_PROUD
//    past the register, and it goes on by pushing that panel at the chassis
//    and twisting to lock. So the register has to stand off the chassis face
//    by at least that much or the body simply cannot be fitted — and the
//    body is wider than the chassis, so there is nowhere to relieve locally.
//    The standoff is ARM_TUBE + F_REV_STACK and nothing else, which is why
//    ARM_TUBE is solved from the camera and BOX_XY gets what is left.
//
// BS_W = 50 still builds — the tray follows it — but it clips the stitch axis
// itself until f/11, which is worse than the corner shading above because it
// eats the ends of the panorama. BS_H = 50 costs nothing. See bom.md.

FLANGE_F = 46.5;
EL_FOCAL = 180.0;   // focal length: bundle, baffles, mouth. Not the register.
EL_FFD   = 158.5;   // flange focal distance, sheet. Path target.

// D800 FX only. 20% overlap lands the stitch on the XPan aspect.
SENSOR_W      = 36.0;
SENSOR_H      = 23.9;
SENSOR_PX_W   = 7360;
SENSOR_PX_H   = 4912;
function overlap_frac()  = 0.20;
function sensor_shift()  = SENSOR_W / 2 * (1 - overlap_frac());   // 14.40
function stitch_w()      = SENSOR_W * (2 - overlap_frac());       // 64.80
function stitch_px()     = round(SENSOR_PX_W * (2 - overlap_frac()));
function stitch_aspect() = stitch_w() / SENSOR_H;                 // 2.711
// Untilted tubes; each bore is translated by sensor_shift() instead.
function field_toe()     = 0;

// --- tubes -----------------------------------------------------------------
// TUBE_ID passes the 48.2 mm the frame corners need at the box wall from
// f/6.95, so it is never the binding aperture -- the 44 mm F throat is.
TUBE_ID  = 46;
TUBE_OD  = 58;
WALL     = (TUBE_OD - TUBE_ID) / 2;   // 6

PORT_PATCH_T   = 4;
function patch_t() = PORT_PATCH_T;

// --- beamsplitter ----------------------------------------------------------
// Edmund #37201 (stock #35-947), 50 × 75 × 1.0, 50/50 VIS, S2 AR.
//
// The plate's two directions do completely different jobs, so it does not
// want to be square. Across the plane of incidence it is foreshortened by
// √2 and that is the direction the 64.80 mm stitch has to cross: 75 there
// presents 53.03. Along the fold there is no foreshortening and nothing to
// carry but the 23.9 mm sensor height, which needs 29.05 at f/5.6, so 50 is
// already +72%. Edmund cut it for exactly this — their note on the
// rectangular plates is that they square up at 45°, and 75/√2 = 53.0 ≈ 50.
//
// BS_H is the one that costs: it sets BOX_Z, and the 75 × 75 was carrying
// 25 mm of chamber height for a margin nothing needed.
//
// 1.00 mm only. A tilted plate puts astigmatism on the transmit path alone
// (S1 faces the lens, so the reflect path never enters glass): 0.172 mm at
// 1 mm, inside the 0.224 mm depth of focus at f/5.6. A 3 mm plate is
// 0.515 mm and would need f/16, and Edmund's 50 × 75 in the other family
// (#17536) is exactly that — check the thickness, not just the size.
BS_W     = 75;    // across the plane of incidence; carries the stitch
BS_H     = 50;    // along the fold; carries the sensor height, and BOX_Z
BS_THICK = 1.0;
BS_CLEAR = 0.35;
BS_N     = 1.52;
function bs_in_plane() = BS_W / sqrt(2);
function bs_t_comp() =
    let (ti = 45, tt = asin(sin(ti) / BS_N))
        BS_THICK * (BS_N / cos(tt) - 1 / cos(ti));   // 0.303 mm
// Where a ray through this plate actually focuses. S1 toward the lens,
// n = 1.52, 45°. Both foci land further from the plate than the reflect
// image: sagittal 0.336 mm, tangential 0.605 mm. The midpoint is the
// circle of least confusion. bs_t_comp() is the optical-path difference,
// not this shift, and the T tube is shortened by it, so a T that has been
// focused has pulled the reflect image this far inside the design R register.
BS_FOCUS_SAG = 0.336;
BS_FOCUS_TAN = 0.605;
function bs_focus_mid() = (BS_FOCUS_SAG + BS_FOCUS_TAN) / 2;   // 0.470 mm
function r_focus_pull() = bs_t_comp() + bs_focus_mid();        // 0.773 mm
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

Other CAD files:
logos/fxpan_fx_gold.stl
openscad/monitor/case-bottom.stl
openscad/taking_lens.stl
stls/fxpan/lid.stl
openscad/Ehybrid/params.scad
archive/openscad/EFhybrid/5dmk3_body.scad
archive/openscad/EFhybrid/WATCH_ME.scad
archive/openscad/EFhybrid/ef_mount_male.scad
archive/openscad/EFhybrid/hybrid_tray.scad
archive/openscad/EFhybrid/shims.scad
archive/openscad/Ehybrid/WATCH_ME.scad
archive/openscad/Ehybrid/a7_body.scad
archive/openscad/Ehybrid/e_mount_male.scad
archive/openscad/Ehybrid/hybrid_tray.scad
archive/openscad/Ehybrid/params.scad
archive/openscad/Ehybrid/shims.scad
archive/openscad/bsplit/WATCH_ME.scad
archive/openscad/bsplit/bs_tray.scad
archive/openscad/bsplit/params.scad
archive/openscad/bsplit/shims.scad
archive/openscad/hybrid/WATCH_ME.scad
archive/openscad/hybrid/hybrid_tray.scad
archive/openscad/hybrid/params.scad
archive/openscad/hybrid/shims.scad
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

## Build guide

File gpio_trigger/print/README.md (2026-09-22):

# Dual-filament silkscreen plate (Bambu H2C)

Two STLs, same origin — load **both** into Bambu Studio:

| File | Filament | Notes |
|---|---|---|
| `board.stl` | 1 (e.g. matte green) | 1.6 mm PCB outline with holes |
| `silk.stl` | 2 (e.g. white) | Top silk, 0.25 mm wider + 0.4 mm tall |

Silk is buffered outward before extrusion so thin text survives the slicer.

## Slicer

1. **Add** both STLs to one plate (they should align without moving).
2. Assign **filament 1** to `board.stl`, **filament 2** to `silk.stl`.
3. Print **face up** (silk on top). No supports needed.
4. Suggested: 0.2 mm layers, 0.4 mm nozzle, 3–4 top layers on the silk.
5. If Bambu still drops detail, turn off **filter out tiny areas** (or similar)
   in the slicer, or bump `SILK_SPREAD` in `export_print.py`.

Regenerate from KiCad: `python3 export_print.py`

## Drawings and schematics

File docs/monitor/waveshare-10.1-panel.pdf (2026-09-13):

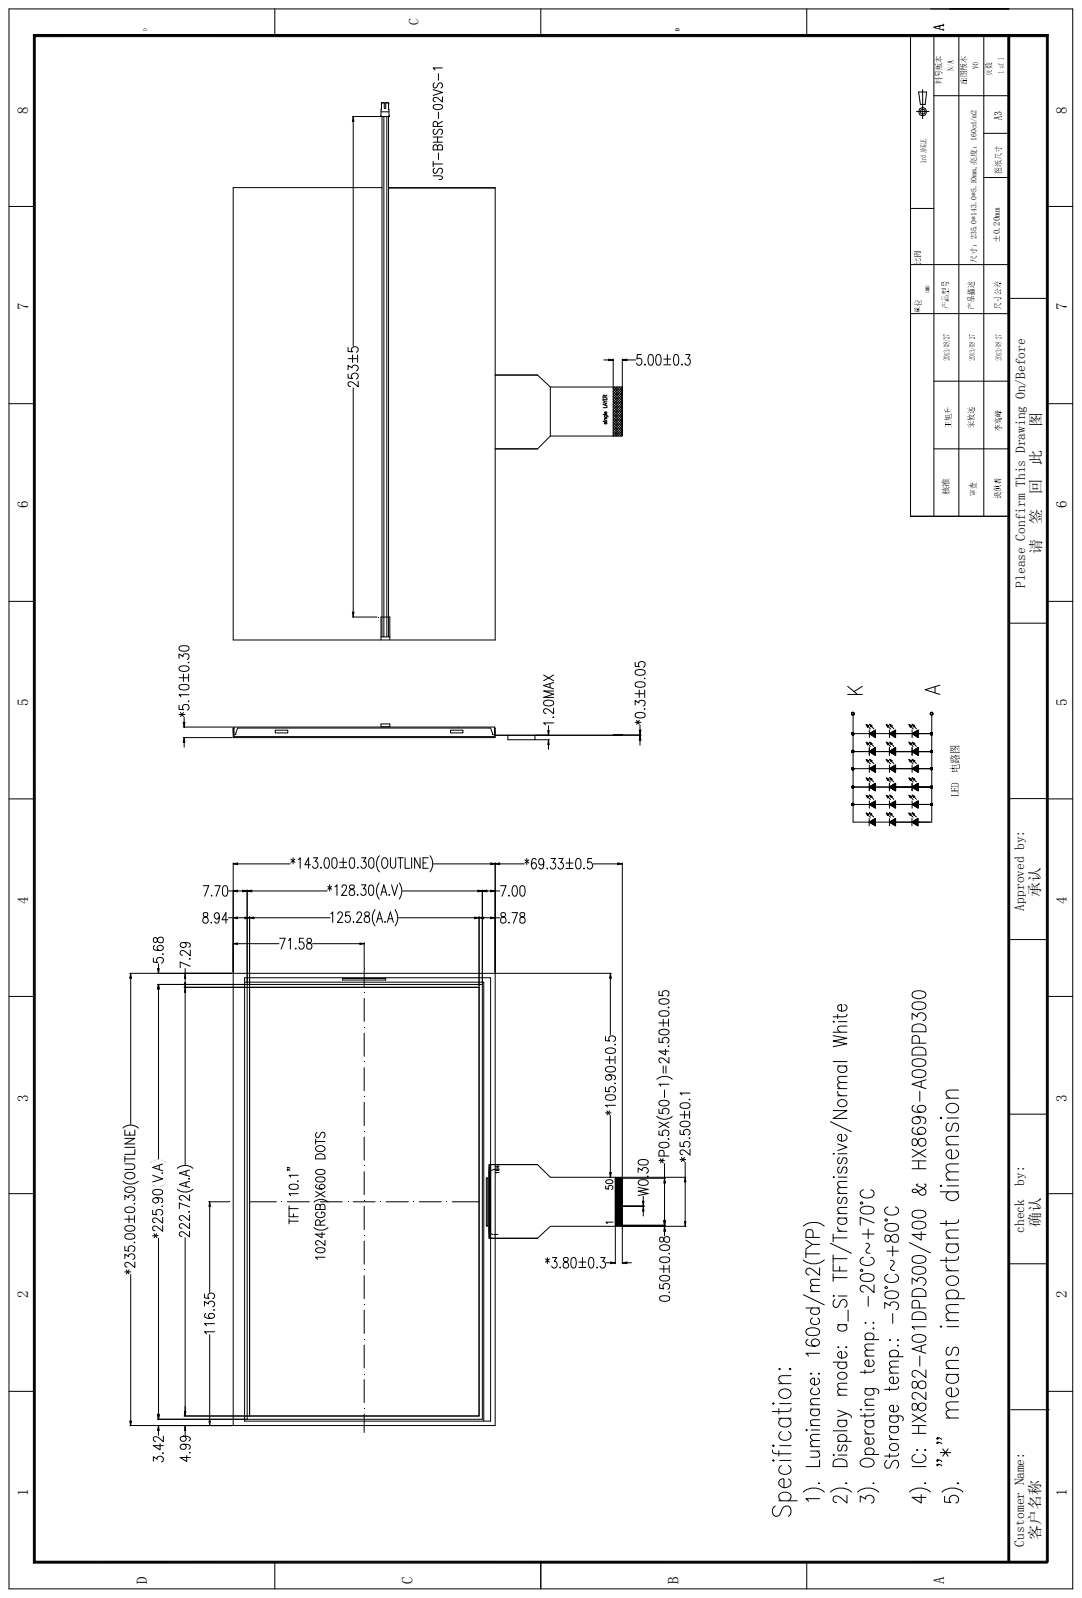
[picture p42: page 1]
确认 客户名称 请 签 回 此 图; Approved by:

check by: Customer Name: Please Confirm This Drawing On/Before

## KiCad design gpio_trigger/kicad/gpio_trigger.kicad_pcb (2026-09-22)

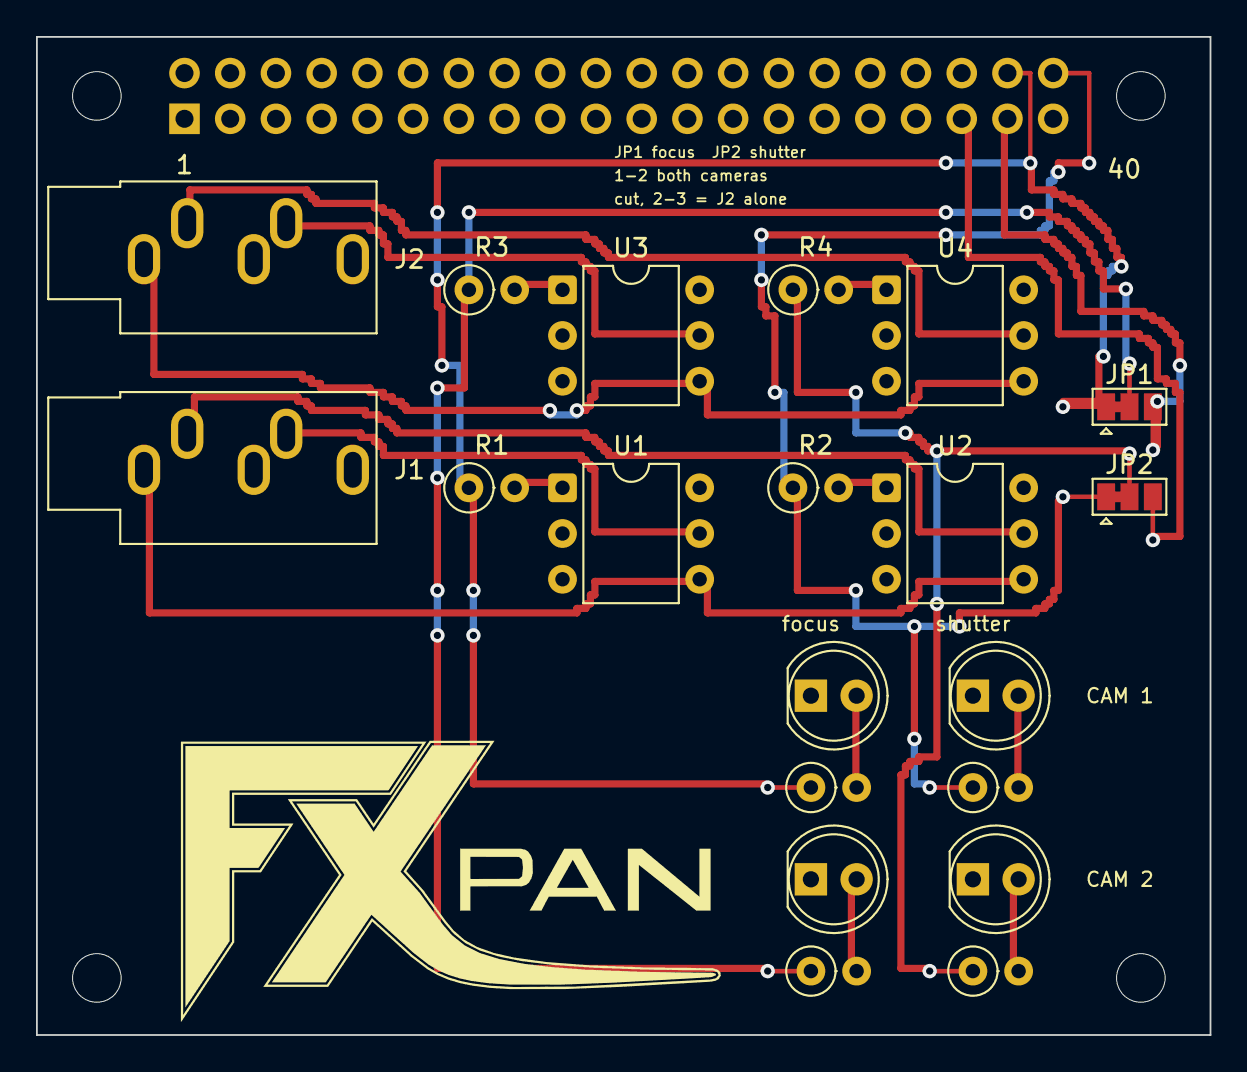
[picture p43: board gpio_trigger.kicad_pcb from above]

Board: 2 copper layers, 65.2 x 55.5 mm, 25 parts (1 on the bottom side), 21 nets.

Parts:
D1: 1 focus; LED_D5.0mm
D2: 1 shutter; LED_D5.0mm
D3: 2 focus; LED_D5.0mm
D4: 2 shutter; LED_D5.0mm
H1, H2, H3, H4: M2.5; MountingHole_2.7mm_M2.5
J1: TRS_CAM_A; Jack_3.5mm_CUI_SJ1-3535NG_Horizontal
J2: TRS_CAM_B; Jack_3.5mm_CUI_SJ1-3535NG_Horizontal
J3: Pi_GPIO; PinSocket_2x20_P2.54mm_Vertical
JP1: J2_focus; SolderJumper-3_P1.3mm_Bridged12_Pad1.0x1.5mm
JP2: J2_shutter; SolderJumper-3_P1.3mm_Bridged12_Pad1.0x1.5mm
R1, R2, R3, R4, R5, R6, R7, R8: 330; R_Axial_DIN0207_L6.3mm_D2.5mm_P2.54mm_Vertical
U1, U2, U3, U4: 4N35; DIP-6_W7.62mm

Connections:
B_FOCUS: J3.37, JP1.3
B_SHUTTER: J3.35, JP2.3
D1_A: D1.2, R5.2
D2_A: D2.2, R6.2
D3_A: D3.2, R7.2
D4_A: D4.2, R8.2
FOCUS: J3.38, JP1.1, R1.1, R5.1
GND: D1.1, D2.1, D3.1, D4.1, J3.6, J3.9, J3.14, J3.20, J3.25, J3.30, J3.34, J3.39, U1.2, U2.2, U3.2, U4.2
J1_RING: J1.R, U1.5
J1_SLEEVE: J1.S, U1.4, U2.4
J1_TIP: J1.T, U2.5
J2_FOCUS: JP1.2, R3.1, R7.1
J2_RING: J2.R, U3.5
J2_SHUTTER: JP2.2, R4.1, R8.1
J2_SLEEVE: J2.S, U3.4, U4.4
J2_TIP: J2.T, U4.5
R1_LED: R1.2, U1.1
R2_LED: R2.2, U2.1
R3_LED: R3.2, U3.1
R4_LED: R4.2, U4.1
SHUTTER: J3.40, JP2.1, R2.1, R6.1

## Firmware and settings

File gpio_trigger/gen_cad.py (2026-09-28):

#!/usr/bin/env python3
"""Generate schematic SVG, board layouts, and KiCad project for gpio_trigger."""

from __future__ import annotations

import heapq
import json
import math
import re
import subprocess
import textwrap
import uuid
from pathlib import Path

ROOT = Path(__file__).resolve().parent
KICAD_ROOT = Path("/Applications/KiCad/KiCad.app/Contents/SharedSupport")
SHEET_UUID = "60b82a67-605d-4edc-a527-425f55d0316b"
PROJECT_NAME = "gpio_trigger"


def uid() -> str:
    return str(uuid.uuid4())


def write_schematic_svg(path: Path) -> None:
    svg = """<?xml version="1.0" encoding="UTF-8"?>
<svg xmlns="http://www.w3.org/2000/svg" viewBox="0 0 1100 720" font-family="ui-monospace, Menlo, Consolas, monospace" font-size="13">
  <defs>
    <marker id="arrow" markerWidth="8" markerHeight="8" refX="6" refY="3" orient="auto">
      <path d="M0,0 L6,3 L0,6 z" fill="#333"/>
    </marker>
    <style>
      .wire { stroke:#1a1a1a; stroke-width:2; fill:none }
      .bus { stroke:#0b5; stroke-width:2.5; fill:none }
      .iso { stroke:#c33; stroke-width:2; stroke-dasharray:8 6; fill:none }
      .box { fill:#f8f8f8; stroke:#333; stroke-width:1.5 }
      .pi { fill:#e8f4ff; stroke:#2563eb; stroke-width:2 }
      .cam { fill:#fff7ed; stroke:#c2410c; stroke-width:2 }
      .lbl { fill:#111 }
      .sub { fill:#555; font-size:11px }
      .title { font-size:20px; font-weight:bold; fill:#111 }
    </style>
  </defs>
  <rect width="1100" height="720" fill="#fff"/>
  <text x="40" y="36" class="title">Pi dual TRS Nikon trigger — electrical schematic</text>
  <text x="40" y="58" class="sub">3.5 mm TRS × 2 · BCM 20/21 both cameras, or cut JP1/JP2 and use BCM 26/19 for camera B</text>

  <!-- Pi -->
  <rect x="40" y="90" width="170" height="150" class="pi" rx="8"/>
  <text x="58" y="118" class="lbl" font-weight="bold">Raspberry Pi GPIO</text>
  <text x="58" y="142" class="lbl">BCM 20 (pin 38) — FOCUS</text>
  <text x="58" y="166" class="lbl">BCM 21 (pin 40) — SHUTTER</text>
  <text x="58" y="190" class="lbl">GND (pin 39) · J2 alt: pin 37 focus, pin 35 shutter</text>
  <text x="58" y="220" class="sub">3.3 V logic · no battery</text>

  <!-- isolation barrier -->
  <line x1="320" y1="70" x2="320" y2="650" class="iso"/>
  <text x="328" y="88" class="sub" fill="#c33">optical isolation — Pi GND ≠ camera GND</text>

  <!-- focus bus -->
  <line x1="210" y1="138" x2="300" y2="138" class="bus"/>
  <text x="230" y="128" class="sub" fill="#0b5">FOCUS</text>

  <!-- shutter bus -->
  <line x1="210" y1="162" x2="300" y2="162" class="bus"/>
  <text x="228" y="152" class="sub" fill="#0b5">SHUTTER</text>

  <!-- gnd bus -->
  <line x1="210" y1="186" x2="300" y2="186" class="wire"/>
  <line x1="300" y1="186" x2="300" y2="600" class="wire"/>
  <text x="218" y="176" class="sub">GND</text>

  <!-- channel template positions -->
"""

    channels = [
        ("U1", "R1", "J1", "CAM A", 110, "focus", "RING"),
        ("U2", "R2", "J1", "CAM A", 190, "shutter", "TIP"),
        ("U3", "R3", "J2", "CAM B", 270, "focus", "RING"),
        ("U4", "R4", "J2", "CAM B", 350, "shutter", "TIP"),
    ]

    def opto_block(x: int, y: int, name: str, rname: str, jack: str, role: str, contact: str) -> str:
        gpio_y = 138 if role == "focus" else 162
        parts = [
            f'  <line x1="300" y1="{gpio_y}" x2="{x}" y2="{gpio_y}" class="bus"/>',
            f'  <rect x="{x}" y="{y}" width="28" height="14" fill="#fff" stroke="#333"/>',
            f'  <text x="{x+4}" y="{y+11}" font-size="10">{rname}</text>',
            f'  <text x="{x+34}" y="{y+11}" class="sub">330Ω</text>',
            f'  <line x1="{x+28}" y1="{y+7}" x2="{x+90}" y2="{y+7}" class="wire"/>',
            # 4N35 box
            f'  <rect x="{x+90}" y="{y-30}" width="120" height="90" class="box" rx="4"/>',
            f'  <text x="{x+98}" y="{y-12}" font-weight="bold">{name} 4N35</text>',
            f'  <text x="{x+98}" y="{y+4}" class="sub">1 anode ← {rname}</text>',
            f'  <text x="{x+98}" y="{y+20}" class="sub">2 cathode → GND</text>',
            f'  <text x="{x+98}" y="{y+36}" class="sub">4 emitter → {jack} SLEEVE</text>',
            f'  <text x="{x+98}" y="{y+52}" class="sub">5 collector → {jack} {contact}</text>',
            f'  <line x1="{x+90}" y1="{y+7}" x2="{x+98}" y2="{y+7}" class="wire"/>',
            f'  <line x1="{x+98}" y1="{y+7}" x2="{x+98}" y2="{y+4}" class="wire"/>',
            f'  <line x1="{x+210}" y1="{y+52}" x2="895" y2="{y+52}" class="wire"/>',
            f'  <text x="{x+285}" y="{y+48}" class="sub">{jack}.{contact}</text>',
            f'  <line x1="{x+98}" y1="{y+20}" x2="300" y2="186" class="wire"/>',
        ]
        return "\n".join(parts)

    body = []
    for u, r, j, cam, y, role, contact in channels:
        body.append(opto_block(340, y, u, r, j, role, contact))

    # Jacks
    jacks = """
  <rect x="900" y="180" width="150" height="120" class="cam" rx="8"/>
  <text x="918" y="208" font-weight="bold">J1 — 3.5 mm TRS</text>
  <text x="918" y="232" class="lbl">TIP ← U2 (shutter)</text>
  <text x="918" y="252" class="lbl">RING ← U1 (focus)</text>
  <text x="918" y="272" class="lbl">SLEEVE ← U1E + U2E</text>
  <text x="918" y="292" class="sub">→ D800 top (T)</text>

  <rect x="900" y="380" width="150" height="120" class="cam" rx="8"/>
  <text x="918" y="408" font-weight="bold">J2 — 3.5 mm TRS</text>
  <text x="918" y="432" class="lbl">TIP ← U4 (shutter)</text>
  <text x="918" y="452" class="lbl">RING ← U3 (focus)</text>
  <text x="918" y="472" class="lbl">SLEEVE ← U3E + U4E</text>
  <text x="918" y="492" class="sub">→ D800 right (R)</text>

  <rect x="40" y="560" width="1020" height="130" fill="#fafafa" stroke="#ccc"/>
  <text x="58" y="588" font-weight="bold">Sequence (gpio_seq.py)</text>
  <text x="58" y="612" class="lbl">1. FOCUS high → ring→sleeve on both jacks</text>
  <text x="58" y="634" class="lbl">2. wait 50–200 ms</text>
  <text x="58" y="656" class="lbl">3. SHUTTER high → tip→sleeve · pulse · release shutter · release focus</text>
  <text x="560" y="612" class="sub">Nikon 10-pin: pin 9 focus, pin 4 shutter, pin 6 ground</text>
  <text x="560" y="634" class="sub">If tip/ring swapped on cable, swap GPIO 20/21 at Pi only</text>
"""
    path.write_text(svg + "\n".join(body) + jacks + "\n</svg>\n")


def write_layout_perf(path: Path) -> None:
    """50×70 mm perfboard inside Hammond 1591TBK — component placement."""
    w, h = 900, 620
    lines = [
        '<?xml version="1.0" encoding="UTF-8"?>',
        f'<svg xmlns="http://www.w3.org/2000/svg" viewBox="0 0 {w} {h}" font-family="ui-monospace, Menlo, Consolas, monospace" font-size="12">',
        "<defs><style>.grid{stroke:#ddd;stroke-width:0.5}.hole{fill:#fff;stroke:#999;stroke-width:0.8}"
        ".comp{fill:#eef;stroke:#333;stroke-width:1.2}.jack{fill:#fed;stroke:#c2410c;stroke-width:1.5}"
        ".wire-f{stroke:#0a7;stroke-width:2;fill:none}.wire-s{stroke:#06c;stroke-width:2;fill:none}"
        ".wire-g{stroke:#333;stroke-width:2;fill:none}.encl{fill:none;stroke:#666;stroke-width:2;stroke-dasharray:6 4}"
        ".dim{stroke:#888;stroke-width:1;marker-end:url(#a)}</style>"
        '<marker id="a" markerWidth="6" markerHeight="6" refX="5" refY="3" orient="auto"><path d="M0,0 L6,3 L0,6 z" fill="#888"/></marker></defs>',
        f'<rect width="{w}" height="{h}" fill="#fff"/>',
        '<text x="30" y="32" font-size="18" font-weight="bold">Perfboard layout — top view (mm)</text>',
        '<text x="30" y="52" fill="#555">50×70 mm veroboard · 2.54 mm pitch · fits Hammond 1591TBK</text>',
    ]
    # enclosure 120x80 outline (scaled 3 px/mm), offset
    ox, oy, scale = 80, 80, 3
    ex, ey = 120 * scale, 80 * scale
    lines.append(f'<rect x="{ox}" y="{oy}" width="{ex}" height="{ey}" class="encl" rx="4"/>')
    lines.append(f'<text x="{ox+8}" y="{oy+16}" fill="#666">1591TBK 120×80 mm</text>')

    # perfboard 50x70 centered
    pb_w, pb_h = 50 * scale, 70 * scale
    pbx = ox + (ex - pb_w) / 2
    pby = oy + 30
    lines.append(f'<rect x="{pbx}" y="{pby}" width="{pb_w}" height="{pb_h}" fill="#f5f5f0" stroke="#333" stroke-width="1.5"/>')
    lines.append(f'<text x="{pbx+4}" y="{pby-6}" font-weight="bold">Perfboard 50×70</text>')

    # grid holes
    for row in range(0, 28):
        for col in range(0, 20):
            cx = pbx + 4 + col * 2.54 * scale
            cy = pby + 4 + row * 2.54 * scale
            if cx > pbx + pb_w - 4 or cy > pby + pb_h - 4:
                continue
            lines.append(f'<circle cx="{cx:.1f}" cy="{cy:.1f}" r="1.8" class="hole"/>')

    def place(name: str, cx_mm: float, cy_mm: float, cw_mm: float, ch_mm: float, cls: str = "comp") -> None:
        x = pbx + cx_mm * scale
        y = pby + cy_mm * scale
        lines.append(
            f'<rect x="{x:.1f}" y="{y:.1f}" width="{cw_mm*scale:.1f}" height="{ch_mm*scale:.1f}" class="{cls}" rx="2"/>'
        )
        lines.append(f'<text x="{x+3:.1f}" y="{y+ch_mm*scale/2+4:.1f}" font-size="10">{name}</text>')

    # component positions in mm from perfboard top-left
    place("U1", 4, 8, 7.6, 10)
    place("U2", 4, 28, 7.6, 10)
    place("U3", 4, 48, 7.6, 10)
    place("U4", 4, 58, 7.6, 10)
    for i, u in enumerate(["R1", "R2", "R3", "R4"], 1):
        place(u, 14, 6 + (i - 1) * 17, 3, 6)

    # J1 → top camera: right wall, plug faces out (+X)
    jx_r = ox + ex + 8
    lines.append(f'<rect x="{jx_r:.1f}" y="{oy+35:.1f}" width="36" height="54" class="jack" rx="3"/>')
    lines.append(f'<text x="{jx_r+4:.1f}" y="{oy+65:.1f}" font-size="11">J1 TRS → D800 top</text>')
    # J2 → right camera: left wall, plug faces out (-X)
    jx_l = ox - 44
    lines.append(f'<rect x="{jx_l:.1f}" y="{oy+120:.1f}" width="36" height="54" class="jack" rx="3"/>')
    lines.append(f'<text x="{jx_l+4:.1f}" y="{oy+150:.1f}" font-size="11">J2 TRS → D800 right</text>')

    # harness
    lines.append(f'<rect x="{ox-50}" y="{oy+100}" width="40" height="30" fill="#e8f4ff" stroke="#2563eb"/>')
    lines.append(f'<text x="{ox-46}" y="{oy+120}" font-size="10">Pi harness</text>')
    lines.append(f'<text x="{ox-46}" y="{oy+134}" font-size="9">38 39 40</text>')

    # legend
    leg_y = 480
    lines += [
        f'<text x="30" y="{leg_y}" font-weight="bold">Wire routing (see netlist.csv)</text>',
        f'<line x1="30" y1="{leg_y+20}" x2="80" y2="{leg_y+20}" class="wire-f"/><text x="88" y="{leg_y+24}">FOCUS (GPIO 20)</text>',
        f'<line x1="30" y1="{leg_y+40}" x2="80" y2="{leg_y+40}" class="wire-s"/><text x="88" y="{leg_y+44}">SHUTTER (GPIO 21)</text>',
        f'<line x1="30" y1="{leg_y+60}" x2="80" y2="{leg_y+60}" class="wire-g"/><text x="88" y="{leg_y+64}">GND (LED cathodes only)</text>',
        f'<text x="30" y="{leg_y+95}" fill="#555">Drill 6 mm panel holes for jacks on short wall · keep camera-side leads short</text>',
        "</svg>",
    ]
    path.write_text("\n".join(lines) + "\n")


def write_layout_pcb(path: Path) -> None:
    """PCB outline is a 78×45 mm stepped board. Socket tab stays clear of Ethernet."""
    scale = 6
    bw, bh = 78, 45
    ox, oy = 60, 60
    lines = [
        '<?xml version="1.0" encoding="UTF-8"?>',
        f'<svg xmlns="http://www.w3.org/2000/svg" viewBox="0 0 800 700" font-family="ui-monospace, Menlo, Consolas, monospace" font-size="11">',
        "<style>.brd{fill:#1a472a;stroke:#0f2d1a;stroke-width:2}.cu{fill:#c9a227;opacity:.35}"
        ".pad{fill:#c9a227;stroke:#8a6d12}.silk{fill:none;stroke:#fff;stroke-width:.8}"
        ".outline{fill:none;stroke:#333;stroke-width:2}.hole{fill:#222}</style>",
        '<rect width="800" height="700" fill="#2d5016"/>',
        '<text x="60" y="36" fill="#fff" font-size="18" font-weight="bold">PCB layout — plugs onto Pi GPIO (78×45 mm, stepped)</text>',
        '<text x="60" y="54" fill="#ccc">J1 and J2 exit the pin-1 end, away from Ethernet · 2×20 socket on the bottom · D1–D4 camera lamps</text>',
        f'<rect x="{ox}" y="{oy}" width="{bw*scale}" height="{bh*scale}" class="brd" rx="3"/>',
        f'<rect x="{ox}" y="{oy}" width="{bw*scale}" height="{bh*scale}" class="outline" rx="3"/>',
    ]

    def mm(x: float, y: float, w: float, h: float, label: str, pad: bool = True) -> None:
        px, py = ox + x * scale, oy + y * scale
        cls = "pad" if pad else "silk"
        lines.append(f'<rect x="{px:.1f}" y="{py:.1f}" width="{w*scale:.1f}" height="{h*scale:.1f}" class="{cls}" rx="1"/>')
        lines.append(f'<text x="{px+2:.1f}" y="{py+h*scale/2+3:.1f}" fill="#fff" font-size="9">{label}</text>')

    # 4N35 footprints DIP-6 7.62mm
    for i, name in enumerate(["U1", "U2", "U3", "U4"]):
        mm(4, 6 + i * 12, 7.62, 10, name)

    for i, name in enumerate(["R1", "R2", "R3", "R4"]):
        mm(16, 7 + i * 12, 5, 2.5, name)

    mm(2, 16, 16, 10, "← J1")
    mm(2, 4, 16, 10, "← J2")
    mm(22, 2, 54, 8, "J3 Pi 2x20  pin1 left", pad=True)
    mm(62, 28, 5, 5, "1 focus", pad=True)
    mm(70, 28, 5, 5, "1 shutter", pad=True)
    mm(62, 36, 5, 5, "2 focus", pad=True)
    mm(70, 36, 5, 5, "2 shutter", pad=True)
    lines.append(f'<text x="{ox}" y="{oy+bh*scale+24}" fill="#fff">J3: 1=GND 2=FOCUS 3=SHUTTER · 2.54 mm header · mount on board edge to Pi dupont</text>')
    lines.append(f'<text x="{ox}" y="{oy+bh*scale+42}" fill="#ccc">Gerbers: open kicad/gpio_trigger.kicad_pcb in KiCad → File → Fabrication Outputs</text>')
    lines.append("</svg>")
    path.write_text("\n".join(lines) + "\n")


def write_netlist(path: Path) -> None:
    rows = [
        "net,from,to",
        "FOCUS,GPIO20,R1.1",
        "FOCUS,GPIO20,JP1.1",
        "J2_FOCUS,JP1.2,R3.1",
        "B_FOCUS,JP1.3,GPIO26",
        "FOCUS,R1.2,U1.1",
        "J2_FOCUS,R3.2,U3.1",
        "SHUTTER,GPIO21,R2.1",
        "SHUTTER,GPIO21,JP2.1",
        "J2_SHUTTER,JP2.2,R4.1",
        "B_SHUTTER,JP2.3,GPIO19",
        "SHUTTER,R2.2,U2.1",
        "J2_SHUTTER,R4.2,U4.1",
        "GND,GPIO_GND,U1.2",
        "GND,GPIO_GND,U2.2",
        "GND,GPIO_GND,U3.2",
        "GND,GPIO_GND,U4.2",
        "CAM_GND_A,U1.4,J1.SLEEVE",
        "CAM_GND_A,U2.4,J1.SLEEVE",
        "CAM_GND_B,U3.4,J2.SLEEVE",
        "CAM_GND_B,U4.4,J2.SLEEVE",
        "J1_RING,U1.5,J1.RING",
        "J1_TIP,U2.5,J1.TIP",
        "J2_RING,U3.5,J2.RING",
        "J2_TIP,U4.5,J2.TIP",
        "FOCUS,GPIO20,R5.1",
        "FOCUS,R5.2,D1.A",
        "GND,D1.K,GPIO_GND",
        "SHUTTER,GPIO21,R6.1",
        "SHUTTER,R6.2,D2.A",
        "GND,D2.K,GPIO_GND",
        "J2_FOCUS,R7.1,D3.A",
        "D3_A,R7.2,D3.A",
        "GND,D3.K,GPIO_GND",
        "J2_SHUTTER,R8.1,D4.A",
        "D4_A,R8.2,D4.A",
        "GND,D4.K,GPIO_GND",
    ]
    path.write_text("\n".join(rows) + "\n")


def _extract_symbol_block(text: str, name: str) -> str:
    pattern = re.compile(rf'\(symbol "{re.escape(name)}"(\s|\))')
    match = pattern.search(text)
    if not match:
        raise ValueError(f"symbol {name} not found")
    idx = match.start()
    depth = 0
    for i in range(idx, len(text)):
        if text[i] == "(":
            depth += 1
        elif text[i] == ")":
            depth -= 1
            if depth == 0:
                return text[idx : i + 1]
    raise ValueError(f"unterminated symbol {name}")


def _indent(text: str, spaces: int) -> str:
    pad = " " * spaces
    return "\n".join(pad + line if line else line for line in text.splitlines())


def _build_lib_symbols() -> str:
    needed = [
        ("Device", "R"),
        ("Device", "LED"),
        ("Jumper", "SolderJumper_3_Bridged12"),
        ("Isolator", "4N25"),
        ("Connector_Audio", "AudioJack3"),
        ("Connector", "Raspberry_Pi_4"),
        ("Simulation_SPICE", "VPWL"),
        ("Simulation_SPICE", "VDC"),
    ]
    blocks: list[str] = []
    sym_dir = KICAD_ROOT / "symbols"
    for lib, name in needed:
        raw = (sym_dir / f"{lib}.kicad_sym").read_text()
        body = _extract_symbol_block(raw, name)
        body = body.replace(f'(symbol "{name}"', f'(symbol "{lib}:{name}"', 1)
        if name == "VPWL":
            body = body.replace(
                '(property "Sim.Params" "pwl=\\"0 -1 50n -1 51n 0 97n 1 171n -1 200n -1\\""',
                '(property "Sim.Params" ""',
                1,
            )
        if name == "4N25":
            body = body.replace(
                '\t\t(symbol "4N25_0_1"',
                "\t\t(property \"Sim.Device\" \"SUBCKT\"\n"
                "\t\t\t(at 0 0 0)\n"
                "\t\t\t(effects (font (size 1.27 1.27)) (hide yes))\n"
                "\t\t)\n"
                "\t\t(property \"Sim.Pins\" \"1=A 2=K 4=E 5=C\"\n"
                "\t\t\t(at 0 0 0)\n"
                "\t\t\t(effects (font (size 1.27 1.27)) (hide yes))\n"
                "\t\t)\n"
                "\t\t(property \"Sim.Library\" \"${KIPRJMOD}/4n35.lib\"\n"
                "\t\t\t(at 0 0 0)\n"
                "\t\t\t(effects (font (size 1.27 1.27)) (hide yes))\n"
                "\t\t)\n"
                "\t\t(property \"Sim.Name\" \"4N35\"\n"
                "\t\t\t(at 0 0 0)\n"
                "\t\t\t(effects (font (size 1.27 1.27)) (hide yes))\n"
                "\t\t)\n"
                '\t\t(symbol "4N25_0_1"',
                1,
            )
        blocks.append(_indent(body, 2))
    return "(lib_symbols\n" + "\n".join(blocks) + "\n)"


def _sch_symbol(
    lib_id: str,
    ref: str,
    value: str,
    x: float,
    y: float,
    angle: int = 0,
    footprint: str = "",
    pins: list[str] | None = None,
    hide_ref: bool = False,
    dnp: bool = False,
    sim: bool = True,
    board: bool = True,
    bom: bool = True,
    extra: list[tuple[str, str]] | None = None,
) -> str:
    pin_uuids = {p: uid() for p in (pins or [])}
    pin_lines = "\n".join(f'    (pin "{p}" (uuid {pin_uuids[p]}))' for p in pin_uuids)
    ref_effects = "(hide yes)" if hide_ref else ""
    dnp_flag = "yes" if dnp else "no"
    sim_flag = "no" if sim else "yes"
    board_flag = "yes" if board else "no"
    bom_flag = "yes" if bom else "no"
    extra_lines = ""
    for key, val in extra or []:
        extra_lines += (
            f'\n    (property "{key}" "{val}"\n'
            f'      (at {x} {y} {angle})\n'
            f'      (effects (font (size 1.27 1.27)) (hide yes))\n'
            f'    )'
        )
    return f"""  (symbol
    (lib_id "{lib_id}")
    (at {x} {y} {angle})
    (unit 1)
    (exclude_from_sim {sim_flag})
    (in_bom {bom_flag})
    (on_board {board_flag})
    (dnp {dnp_flag})
    (uuid {uid()})
    (property "Reference" "{ref}"
      (at {x} {y - 5.08} {angle})
      (effects (font (size 1.27 1.27)) {ref_effects})
    )
    (property "Value" "{value}"
      (at {x} {y + 5.08} {angle})
      (effects (font (size 1.27 1.27)))
    )
    (property "Footprint" "{footprint}"
      (at {x} {y} {angle})
      (effects (font (size 1.27 1.27)) (hide yes))
    )
    (property "Datasheet" "~"
      (at {x} {y} {angle})
      (effects (font (size 1.27 1.27)) (hide yes))
    ){extra_lines}
{pin_lines}
    (instances
      (project "{PROJECT_NAME}"
        (path "/{SHEET_UUID}"
          (reference "{ref}")
          (unit 1)
        )
      )
    )
  )"""


def _sch_wire(x1: float, y1: float, x2: float, y2: float) -> str:
    return (
        f'  (wire (pts (xy {x1} {y1}) (xy {x2} {y2}))'
        f' (stroke (width 0) (type default)) (uuid {uid()}))'
    )


def _sch_label(name: str, x: float, y: float, angle: int = 0) -> str:
    return f"""  (label "{name}"
    (at {x} {y} {angle})
    (effects (font (size 1.27 1.27)) (justify left bottom))
    (uuid {uid()})
  )"""


def _fmt(n: float) -> str:
    s = f"{n:.4f}".rstrip("0").rstrip(".")
    return "0" if s in ("", "-0") else s


def _pins_in(block: str) -> list[tuple[str, float, float]]:
    pins: list[tuple[str, float, float]] = []
    for chunk in block.split("(pin ")[1:]:
        at = re.search(r"\(at\s+([-\d.]+)\s+([-\d.]+)", chunk)
        num = re.search(r'\(number\s+"([^"]+)"', chunk)
        if at and num:
            pins.append((num.group(1), float(at.group(1)), float(at.group(2))))
    return pins


def _glabel(name: str, x: float, y: float) -> str:
    return f"""  (global_label "{name}"
    (shape bidirectional)
    (at {_fmt(x)} {_fmt(y)} 0)
    (effects (font (size 1.27 1.27)) (justify left))
    (uuid {uid()})
  )"""


def _sch_no_connect(x: float, y: float) -> str:
    return f"  (no_connect (at {_fmt(x)} {_fmt(y)}) (uuid {uid()}))"
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

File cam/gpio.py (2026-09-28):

#!/usr/bin/env python3
"""10-pin release: focus held, then shutter, on both camera jacks.

BCM 20 and 26 are focus (J1, and J2 when JP1 is bridged 2–3).
BCM 21 and 19 are shutter the same way. Live view has to be down
first: a D800 ignores the 10-pin remote while USB is claimed.
"""

from __future__ import annotations

import json
import subprocess
import time
from pathlib import Path

import dual

PIN = 21
PULSE_S = 0.3
FOCUS_LEAD_S = 0.1
# J1 is always 20/21. J2 follows those while the solder jumpers are
# bridged 1–2, and these when they are cut and bridged 2–3.
FOCUS_PINS = (20, 26)
SHUTTER_PINS = (21, 19)
CONSUMER = "nikonduals"
SIM_PATH = Path(__file__).resolve().parent / "gpio.json"


def board_model(path=None):
    paths = (path,) if path is not None else (
        Path("/proc/device-tree/model"),
        Path("/sys/firmware/devicetree/base/model"),
    )
    for item in paths:
        item = Path(item)
        if not item.is_file():
            continue
        return item.read_bytes().split(b"\x00", 1)[0].decode("utf-8", "replace").strip()
    return ""


def on_pi(path=None):
    return "raspberry pi" in board_model(path).lower()


def sim_on():
    if not SIM_PATH.is_file():
        return False
    try:
        return bool(json.loads(SIM_PATH.read_text()).get("sim"))
    except (OSError, json.JSONDecodeError):
        return False


def set_sim(on):
    SIM_PATH.write_text(json.dumps({"sim": bool(on)}) + "\n")
    return snapshot()


def snapshot():
    sim = sim_on()
    pi = on_pi()
    return {
        "available": pi or sim,
        "sim": sim,
        "pi": pi,
        "pin": PIN,
        "pulse_ms": int(round(PULSE_S * 1000)),
        "focus_ms": int(round(FOCUS_LEAD_S * 1000)),
        "focus": list(FOCUS_PINS),
        "shutter": list(SHUTTER_PINS),
    }


def find_chip(devices=Path("/sys/bus/gpio/devices")):
    """RP1 on Pi 5 is gpiochip4; gpiochip0 is the legacy header on many images."""
    ranked = []
    root = Path(devices)
    if root.is_dir():
        for sys in root.glob("gpiochip*"):
            label = ""
            lab = sys / "label"
            if lab.is_file():
                try:
                    label = lab.read_text().strip().lower()
                except OSError:
                    label = ""
            score = 0
            if "pinctrl" in label or "rp1" in label:
                score = 3
            elif label.startswith("bcm") or "brcm" in label:
                score = 2
            num = int(sys.name.replace("gpiochip", "") or "0")
            # Unlabeled Pi 5 images expose many gpiochips; only 4 and 0 carry
            # the 40-pin header. Do not pick the highest chip number by default.
            pref = {4: 2, 0: 1}.get(num, 0)
            ranked.append((score, pref, num, sys.name))
        ranked.sort(reverse=True)
        if ranked:
            return f"/dev/{ranked[0][3]}"
    return "/dev/gpiochip0"


def _pulse(set_level, pulse_s):
    set_level(1)
    try:
        time.sleep(pulse_s)
    finally:
        set_level(0)


def _drive_gpiod(pin, pulse_s):
    import gpiod

    chip = find_chip()
    if hasattr(gpiod, "request_lines"):
        from gpiod.line import Direction, Value

        with gpiod.request_lines(
            chip,
            consumer=CONSUMER,
            config={
                pin: gpiod.LineSettings(
                    direction=Direction.OUTPUT, output_value=Value.INACTIVE
                )
            },
        ) as req:
            _pulse(
                lambda v: req.set_value(pin, Value.ACTIVE if v else Value.INACTIVE),
                pulse_s,
            )
        return "gpiod"

    name = chip[5:] if chip.startswith("/dev/") else chip
    line_chip = gpiod.Chip(name)
    try:
        line = line_chip.get_line(pin)
        line.request(consumer=CONSUMER, type=gpiod.LINE_REQ_DIR_OUT, default_val=0)
        try:
            _pulse(line.set_value, pulse_s)
        finally:
            line.release()
    finally:
        line_chip.close()
    return "gpiod"


def _drive_lgpio(pin, pulse_s):
    import lgpio

    chip = find_chip()
    num = int(Path(chip).name.replace("gpiochip", "") or "0")
    handle = lgpio.gpiochip_open(num)
    try:
        lgpio.gpio_claim_output(handle, pin, 0)
        _pulse(lambda v: lgpio.gpio_write(handle, pin, v), pulse_s)
    finally:
        lgpio.gpiochip_close(handle)
    return "lgpio"


def _drive_rpi(pin, pulse_s):
    import RPi.GPIO as GPIO

    GPIO.setmode(GPIO.BCM)
    GPIO.setwarnings(False)
    GPIO.setup(pin, GPIO.OUT, initial=GPIO.LOW)
    _pulse(lambda v: GPIO.output(pin, bool(v)), pulse_s)
    return "RPi.GPIO"
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

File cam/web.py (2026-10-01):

#!/usr/bin/env python3
"""Field + lab control pages for the two bodies.

  python3 cam/web.py
  iPhone (same Wi-Fi):  http://<lan-ip>:8787/
  laptop debugger:      http://127.0.0.1:8787/lab
"""

from __future__ import annotations

import atexit
import json
import os
import re
import shutil
import socket
import subprocess
import sys
import time
from http.server import BaseHTTPRequestHandler, ThreadingHTTPServer
from pathlib import Path
from urllib.parse import parse_qs, urlparse

sys.path.insert(0, str(Path(__file__).resolve().parent))
import brightness
import dual
import gpio
import link
import live
import pano
import settings
import wifi

HERE = Path(__file__).resolve().parent
LIVE = live.Live()
LINK = link.Link(LIVE)
PORT = 8787
KIOSK_CHROME = "--class=duals-kiosk-chromium"


def _shutdown():
    LINK.stop()
    wifi.WATCH.stop()
    LIVE.stop()
    dual.ptp_hold(False)


atexit.register(_shutdown)


def lan_ips():
    found = []
    try:
        sock = socket.socket(socket.AF_INET, socket.SOCK_DGRAM)
        sock.connect(("1.1.1.1", 80))
        found.append(sock.getsockname()[0])
        sock.close()
    except OSError:
        pass
    try:
        for info in socket.getaddrinfo(socket.gethostname(), None, socket.AF_INET):
            ip = info[4][0]
            if ip and not ip.startswith("127."):
                found.append(ip)
    except socket.gaierror:
        pass
    out = []
    for ip in found:
        if ip not in out:
            out.append(ip)
    return out


def urls_for(port):
    return [f"http://127.0.0.1:{port}/lab"] + [f"http://{ip}:{port}/" for ip in lan_ips()]


def _json(handler, code, payload):
    body = json.dumps(payload).encode()
    handler.send_response(code)
    handler.send_header("Content-Type", "application/json")
    handler.send_header("Cache-Control", "no-store")
    handler.send_header("Content-Length", str(len(body)))
    handler.end_headers()
    handler.wfile.write(body)


def _html(handler, name):
    body = (HERE / name).read_bytes()
    handler.send_response(200)
    handler.send_header("Content-Type", "text/html; charset=utf-8")
    handler.send_header("Cache-Control", "no-store")
    handler.send_header("Content-Length", str(len(body)))
    handler.end_headers()
    handler.wfile.write(body)


def _svg(handler, path):
    body = path.read_bytes()
    handler.send_response(200)
    handler.send_header("Content-Type", "image/svg+xml; charset=utf-8")
    handler.send_header("Cache-Control", "no-store")
    handler.send_header("Content-Length", str(len(body)))
    handler.end_headers()
    handler.wfile.write(body)


def _read_json(handler):
    n = int(handler.headers.get("Content-Length") or 0)
    if n == 0:
        return {}
    return json.loads(handler.rfile.read(n))


def _stop_live():
    LINK.set_live(False)


def _live_message(snap):
    if not snap["roles"]:
        return "live view off"
    bits = []
    for role, info in snap["roles"].items():
        if info["alive"]:
            bits.append(f"{role} {info['frames']}f")
        else:
            bits.append(f"{role} stopped" + (f" ({info['error']})" if info["error"] else ""))
    return "  ".join(bits)


def _kiosk_stop_path():
    runtime = os.environ.get("XDG_RUNTIME_DIR") or f"/run/user/{os.getuid()}"
    return Path(runtime) / "duals-kiosk.stop"


def _kiosk_running():
    return subprocess.run(
        ["pgrep", "-f", "--", KIOSK_CHROME],
        stdout=subprocess.DEVNULL,
        stderr=subprocess.DEVNULL,
    ).returncode == 0


def _kiosk_enabled():
    return os.environ.get("DUALS_KIOSK") == "1" or _kiosk_running()


def _exit_kiosk():
    path = _kiosk_stop_path()
    try:
        path.parent.mkdir(parents=True, exist_ok=True)
        path.write_text("1\n")
    except OSError as exc:
        raise dual.CamError(f"cannot write kiosk stop file: {exc}") from exc
    subprocess.run(["pkill", "-f", "--", KIOSK_CHROME], check=False)
    return {"ok": True, "message": "desktop"}


def _maybe_sync(have, prefs):
    if not prefs.get("sync", True) or len(have) < 2:
        return ""
    try:
        return dual.copy_from_master(have, prefs.get("master") or "T").get("message") or ""
    except dual.CamError as exc:
        return str(exc)


def _gpio_shoot(shot_json, prefs, assignments):
    """Align over USB, release, pulse GPIO, pull over USB again."""
    from datetime import datetime
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

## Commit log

2026-09-11 Add infinity-capable dual D7000 panoramic T chassis in OpenSCAD.
    Single solid chassis with fused F-mounts, roof field-splitter mirrors oriented for lens→camera paths, and a linked BOM for FSM/helicoid/sync hardware.
    [WATCH_ME.scad, f-mount_raw.stl, f_mount_male.scad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]
2026-09-11 Simplify helicoid nut bore to avoid detached preview geometry.
    [WATCH_ME.scad]
2026-09-11 Restore outward F-mounts and add M42 threads via rcolyer library.
    Bayonets were rotated into the hollow chamber and erased; they are now unioned after boring. Stem uses ScrewHole for printable M42×1, arms lengthened so mounts clear the junction.
    [WATCH_ME.scad, f_mount_male.scad, params.scad]
2026-09-11 Use f-mount_raw.stl for the camera bayonets instead of a hand-rolled mount.
    Import and center the provided F-mount mesh on each arm, fuse with a tube boss, and point the bayonet faces outward at the D7000s.
    [WATCH_ME.scad, f_mount_male.scad, params.scad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]
2026-09-11 Show bare f-mount_raw.stl on each arm; remove mount clutter.
    Drop cradles/fat bosses/ghosts by default, stop arm tubes short of the bayonet, and stop boolean-cutting the imported mesh so the F-mounts stay visible.
    [WATCH_ME.scad, f_mount_male.scad, params.scad]
2026-09-11 Optional lid, top-drop mirror grooves, and corrected center knife roof.
    Lid defaults off (SHOW_LID=0). Mirror cartridges slide in from the top; coatings face into the V and meet at the box center; lid lip light-traps when enabled.
    [WATCH_ME.scad, mirror_tray.scad, params.scad]
2026-09-11 Make the mirror mount a single L-cartridge with both coatings facing in.
    One printable V/L locks the 90° included angle, webs both wings to a center spine, and places left and right glasses on the inner faces for top-drop assembly.
    [WATCH_ME.scad, mirror_tray.scad]
2026-09-11 Invert only the right mirror wing so both coatings face into the V.
    Left wing stays as-is; right wing glass/frame flip fixes the side that was facing the camera port.
    [mirror_tray.scad]
2026-09-11 Park the mirror V on the back wall with coatings facing out of the V.
    Apex sits on the blank +Y wall; both glasses face the chamber/lens the same way; top-drop grooves follow the cartridge.
    [WATCH_ME.scad, mirror_tray.scad]
2026-09-11 Seat the mirror V flush on the blank back wall with out-facing coatings.
    Apex on +Y; both wings use the same coating-out recipe; chamber opens toward the lens.
    [mirror_tray.scad]
2026-09-11 Fix back-wall V: apex on blank +Y, both coatings out via mirrored right wing.
    Left is mirror() of a chamber-facing right blade so neither glass sits on the wrong face.
    [mirror_tray.scad]
2026-09-11 Put the V on the blank back wall with both coatings facing out of the V.
    Back plate flush to +Y; glasses on the outer chamber-facing sides; left mirrored from right.
    [mirror_tray.scad]
2026-09-11 Rebuild back-wall V with both coatings on the outer faces.
    Apex on blank +Y; open toward lens; left/right built with opposite out signs (no mirror()).
    [mirror_tray.scad]
2026-09-11 Flip both mirror pockets onto the outer faces of the back-wall V.
    Local +X after ±135° points into the crease; out signs inverted so coatings face out.
    [mirror_tray.scad]
2026-09-11 Make the mirror V a fixed center-joined cartridge toward the back wall.
    Tip at origin; arms to blank +Y; coatings out; drop the stray back plate so it cannot be seated backwards.
    [WATCH_ME.scad, mirror_tray.scad]
2026-09-11 Rebuild the V as a center-tip cartridge with no back plate.
    Knife joins at the box middle; arms to the blank back wall; coatings out on both wings; floor is wing strips only.
    [mirror_tray.scad]
2026-09-11 Join the V at a thin center knife with outer-face coatings only.
    Drop the fat spine block and back plate; tip stays at the box middle with arms toward the blank wall.
    [mirror_tray.scad]
2026-09-11 Clear the open V and put both coatings on the outer faces.
    Flip out-signs after ±45°; carve out the leftover back-wall slab; keep a thin center knife only.
    [mirror_tray.scad]
2026-09-11 Keep the V cartridge inside the box and pin it with lid forks.
    Clip the one-piece out-facing V to the chamber, locate it in floor pockets, and drop the F-mount STL offset so the bayonets sit on the arm bores.
    [WATCH_ME.scad, f_mount_male.scad, mirror_tray.scad]
2026-09-11 Toe the arms and cross the glasses for about 20% stitch overlap.
    Each camera looks across the knife by OVERLAP_FRAC of a D7000 frame; the V still cannot duplicate full-brightness rays without a beamsplitter.
    [WATCH_ME.scad, mirror_tray.scad, params.scad]
2026-09-11 Cut the 1/4-20 tripod thread into the chassis floor.
    Blind socket in the existing floor so the bottom stays flat and can print on the bed.
    [WATCH_ME.scad, params.scad]
2026-09-11 Thicken the V cartridge and drop the under-mirror feet.
    Solid 4.5 mm wings sit on the chamber floor so the cartridge prints as one chunk.
    [mirror_tray.scad]
2026-09-11 Split the T into a box and three bolt-on tubes with wall cookies.
    Each port prints cookie-down; M3 screws and hex nuts clamp the tubes into recesses on the junction box.
    [WATCH_ME.scad, params.scad]
2026-09-11 Seat the arm cookies flat and use 52 mm reverse-ring mouths.
    [WATCH_ME.scad, mirror_tray.scad, params.scad]
2026-09-11 Toe the arm tubes toward the lens and sink the port nuts in the wall.
    [WATCH_ME.scad, mirror_tray.scad, params.scad]
2026-09-11 Keep the box walls solid and add a script that exports print STLs.
    [WATCH_ME.scad, params.scad]
2026-09-11 Add 50/50 and hybrid L forks plus the El-Nikkor stem adapter.
    The V remains the hard-split panorama; bsplit is same-frame amplitude split; hybrid parks one plate at the knife so the cameras see different halves with overlap.
    [WATCH_ME.scad, bs_tray.scad, hybrid_tray.scad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]
2026-09-11 Seat the hybrid 50/50 on center and toe each DX at a different image half.
    The extra FSM holder was not an optic. Kraken traces the El-Nikkor at the close-up conjugate this path forces.
    [WATCH_ME.scad, hybrid_tray.scad, params.scad]
2026-09-11 Seat the hybrid plate chassis in the box corners and trace rays on the print STLs.
    The cartridge drops in from above; the 50/50 slides into an open-top slot. Kraken draws T through the slot and R off the plate on the chassis and tray meshes.
    [WATCH_ME.scad, hybrid_tray.scad]
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2026-09-11 Seat a blind Pi hole pattern on the hybrid lid and show the lid.
    The 58×49 pockets stop 1.5 mm short of the inner face, and the M3 lid screws sit in the box rim instead of the lip.
    [WATCH_ME.scad, params.scad]
2026-09-11 Mark the hybrid arms and add a local camera control page.
    Cookies get an arrow plus R/T, ./export_hybrid.sh writes stls/hybrid, and cam/web.py is the PTP control UI.
    [WATCH_ME.scad, params.scad]
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2026-09-12 Let camera tubes print as reverse-ring mouths or a clocked F-bayonet.
    Keep the F-register fixed when the mount stack changes, and export both arm STLs so a set-screw ring or an indexed printed mount is a slicer choice.
    [WATCH_ME.scad, f_mount_male.scad, params.scad]
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2026-09-12 Give PANO real stitch modes and keep status on the T/R pair.
    A guessed overlap plus a default R-flop was smearing the hybrid frames, and errors only hit the log.
    [pano.py, test_dual.py, web.py]
2026-09-12 Let USB assign T and R by tapping a body, not twin dropdowns.
    A select change posted a full replace and could wipe the other role, and both D7000s looked identical.
    [dual.py, test_dual.py, web.py]
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2026-09-12 Add EF and E hybrid L forks so a 5D III or α7 pair can run the same 50/50 stitch.
    README and BOM cover reverse rings, assembly, and the 135/5.6 countryside sims.
    [5dmk3_body.scad, WATCH_ME.scad, a7_body.scad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]
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2026-09-12 Use a 1/4-20 heat-set in the chassis floor instead of a printed thread.
    An 8 mm wall cannot hold a cut UNC; the short 6.4 mm insert in an Ø8.1 well does.
    [WATCH_ME.scad, chassis.stl, params.scad]
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2026-09-12 Reinforce the printed F-mounts and mark the reverse-ring clock.
    Add a backing collar and tine pads behind the register, and engrave a shallow radial tick on the tube-end seat so a reverse ring can be lined up with the body pin.
    [WATCH_ME.scad, arm_l.stl, arm_l_f.stl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]
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2026-09-13 Show the 180 landscape stitch at 50 m, and ship the short F-50 camera tubes with the fused stem cookie.
    [WATCH_ME.scad, arm_r_s.stl, arm_r_sf.stl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]
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2026-09-14 Add the shifted-DX hybrid kit and document fuzzy skin on the cartridge.
    Keep tubes square to the image plane, line the light path in PETG, and paint Bambu fuzzy skin on the tray inner walls only so the cup still slips into the box.
    [WATCH_ME.scad, arm_r.stl, arm_r_f.stl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]
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2026-09-16 Align FX bodies and reinforce hybrid shift chassis
    [WATCH_ME.scad, arm_r.stl, arm_r_f.stl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]
2026-09-16 Reinforce FX cookie edges and corner supports
    [WATCH_ME.scad, arm_r_f.stl, arm_r_f_inner.stl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]
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2026-09-16 Replace corner bars with integrated gussets
    [WATCH_ME.scad, chassis.stl, chassis_inner.stl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]
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2026-09-16 Ship the M62 180 stem and FX print STLs.
    Replace the too-small M42 180 stack with a female M62 nut plus a 17 mm spacer (stand-in for a 17–31 mm helicoid), mark the FX chassis D1440, and refresh hybrid_shift / hybrid_shift_fx meshes for printing.
    [WATCH_ME.scad, arm_r.stl, arm_r_f.stl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]
2026-09-16 Fix first-print issues so F pads, glare plates, D-mark, and brace heads actually work.
    Close the pin-fork gap, fuse glare masks to the tube wall, space the chassis D-number for clean slices, and open brace pockets for knurled 1/4-20 thumbscrews.
    [WATCH_ME.scad, arm_r_f.stl, arm_t_f.stl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]
2026-09-16 Clear the R battery door and flash nose without eating the brace pad or tube bore.
    Pull the R–T web off the EN-EL15 corner, and add a short camera-up bevel at the F-mouth so the pentaprism clears the 68 mm OD.
    [WATCH_ME.scad, arm_r_f.stl, arm_t_f.stl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]
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2026-09-17 Show USB link speed and stitch flopped R on the left of T.
    Magick identify was dying on -limit-before-subcommand, and the hybrid
    compose had T/R swapped versus live preview.
    [dual.py, link.py, pano.py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]
2026-09-17 Align Open mode with a translation SIFT instead of an affine warp.
    Hybrid T/R is a lateral shift; AffineStitcher’s 6-DOF match was shearing
    the pano even after the frames were on the correct sides.
    [pano.py, test_dual.py]
2026-09-17 Leave live view off until START, and show PANO frames larger.
    Kiosk was opening both streams on boot and draining the bodies; thumbs
    also sat in a short three-up row that cropped away usable height.
    [link.py, pano.py, test_dual.py]
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2026-09-18 Trace the D3 Nikon FX badge for the chassis wordmark and export it as a gold inlay STL.
    Replace FXPan with a photo-traced badge plus separate Pan, mp, rule, and spec layers so each filament color gets its own drop-in.
    [WATCH_ME.scad, chassis.stl, chassis_logo.stl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]
2026-09-18 Break logo plug faces off the pocket so the slicer can resolve them
    The colour plugs were the same solid that cut the pocket, so every face —
    wall, floor and sides — landed exactly on the chassis. Loaded together the
    slicer had nothing to resolve and rendered the badge as speckle.
    Plugs now swell 0.08 into the pocket walls and floor and carry a 0.06 lip
    outside the wall face. The pocket keeps its own depth, so the chassis is
    unchanged apart from the logo art.
    [WATCH_ME.scad, chassis.stl, chassis_logo.stl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]
2026-09-18 Add FXPAN 65, a 65 mm FX panoramic body, clean at f/8 not f/5.6.
    Two D800 behind one EL-Nikkor 180/5.6 and a 75x75x1 50/50 plate. Stitch is
    64.80 x 23.9 mm, 2.711:1, 13248 x 4912 = 65.1 MP; XPan is 65 x 24 and
    2.708:1. Infinity lands at 17.5 mm of the helicoid's 17..31 travel.
    The chamber is not a cube. PATH counts BOX_XY once but spans both legs, so
    every millimetre of chassis costs two of budget, and a cube tall enough for a
    75 mm plate on its diagonal puts the shortest path at 207 mm. BOX_Z carries
    the plate, BOX_XY comes out of the path budget, and the stem is an 8 mm M62
    boss instead of hybrid_shift's 20 mm nut for the same reason.
    kraken/fxpan_paths.py ray traces it and overturned th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
    [WATCH_ME.scad, arm_r.stl, arm_r_f.stl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]
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2026-09-19 Stitch FXPAN pairs with a SIFT similarity warp and enblend.
    Translation-only blend cannot absorb the ~1.5° roll between the two bodies; Hugin mode now estimates scale+rotation+shift in the overlap and multiband-blends.
    [pano.py, settings.py, test_dual.py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]
2026-09-19 Replace magick/enblend Hugin stitches with in-memory OpenCV, clip the rotated wedges, and show how long each stitch took.
    [pano.py, settings.py, test_dual.py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]
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2026-09-19 Document afocal anamorphic adapters on FXPAN 65, not the 60 mm Ultra-Star.
    The countryside sim compares 1.33× / 1.5× / 2× on the EL-Nikkor 180 against one D800; 1.5× is the stills pick and the integrated projector lens is the wrong class.
2026-09-20 Give hybrid_shift FX a one-piece EL180 infinity stem and truncated M52 arm mouths.
    The printed adapter cannot take the 180 in tension, so seat the lens at collapsed-helicoid length until the bought helicoid arrives, and stop the reverse rings falling through a full-height V.
    [WATCH_ME.scad, arm_r.stl, arm_r_inner.stl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]
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2026-09-20 Add FXPAN logo artwork: web SVG and colour-separated STLs
    fxpan_gen.py builds the mark from one geometry definition and emits both
    the web SVG and four STL parts (gold FX + sweep, white PAN, red outline,
    optional backer plate) at 145 mm overall width. Parts share an origin and
    do not interpenetrate, so a slicer can load them as one object.
    Also fixes svglogo3.svg (bad xmlns, truncated N path) and genfxpan.py
    (spline/expand calls that do not exist in CadQuery 2.8).
    [fxpan_backer_optional.stl, fxpan_fx_gold.stl, fxpan_outline_red.stl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]
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2026-09-21 FXPAN tray: supportless cup walls and plate frame
    Drop the flared plate-frame lip, replace the skirt step with a separate
    floor slab and uniform wall thickness, and run the V-grooves through the
    top so the rib valleys are not capped by an overhanging rim.
    [fxp_tray.scad]
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2026-09-22 Add an OpenSCAD soldering jig for the GPIO trigger board.
    Per-part support pockets hold topside components flush when flipped,
    with a corner U-groove former for vertical 1/4 W resistor bends.
    [solder_jig.scad]
2026-09-22 Rework the GPIO trigger solder jig for flipped soldering and deck branding.
    Align component wells to TRS jack anchors on the pin-1 wall, replace the
    resistor cradle with a through-hole vertical bender, and add a pocketed
    multipart FXPAN inlay with separate color STL exports.
    [solder_jig.scad]
2026-09-22 Fix the EL180 infinity stem bore and thicken the solder-jig FXPAN outline.
    Use a straight cylindrical boss with a 60 mm barrel clearance so the lens
    seats without disconnecting the cookie, and boost the jig logo outline to
    0.42 mm so it prints on a 0.4 mm nozzle.
    [WATCH_ME.scad, solder_jig.scad, stem_el180_inf.stl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]
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2026-09-23 Seat the EL-Nikkor on its 158.5 mm flange and flush the chassis skin to the cookies.
    The old path treated 180 mm as flange distance, so the lens was stuck at macro. The infinity stem is fixed on the register, the helicoid stem reaches it just off the collapsed stop, and the outer shell comes in to that same face.
    [WATCH_ME.scad, arm_r.stl, arm_r_f.stl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]
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2026-09-24 Add tray filament pins so the beamsplitter stays put when the body is inverted.
    Each cheek gets a 2 mm bore that crosses the slot just above the glass for a 1.75 mm scrap.
    [fxp_tray.scad, fxp_tray.stl]
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2026-09-24 Add Nikkor-W stem, longer arms, and ISCO clamp with groove lip.
    Rebudget 8 mm of the W register into arm_*_w tubes, seat the stem cookie flush with the chassis skin, and fix the ISCO collar so it locks in the barrel groove instead of sliding on the Ø73 land.
    [WATCH_ME.scad, arm_r_fw.stl, arm_r_fw_inner.stl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]
2026-09-26 Add a screw-in FXPAN logo panel and correct the ISCO clamp bores.
    The badge face is now its own cookie, so a logo change does not reprint the chassis. The EL clamp bore matches the M62, and the clamp screws are through-holes for M3 4x5 inserts.
    [WATCH_ME.scad, isco_clamp.stl, isco_clamp_nw.stl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]
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2026-09-26 Add an FXPAN design review for the Nikkor-W and printed-F build.
    Capture blocking mechanical and optical issues, H2C print guidance, and fix steps for follow-up work.
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2026-09-27 Default FXPAN OS kiosk with Wi-Fi join fixes and lighter PTP traffic.
    Run fxos on 8790 alongside web.py, polish UI (logo, live toggle, playback scroll, hotspot QR), rename AP to FXPAN with NM polkit, batch gphoto2 status/set to reduce LCD blink, and harden deploy/restart scripts.
    [dual.py, link.py, system.js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]
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2026-09-28 Pack camera settings into one gphoto2 session and stop auto-starting web.py.
    A missing widget is remembered instead of retried per key, and the kiosk no longer launches the camera API on 8787 by itself.
    [dual.py, test_dual.py, web.py]
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2026-09-28 Shoot GPIO frames through camera RAM and stop the buffer from jamming.
    Recording Media stuck on SDRAM after USB captures sent 10-pin frames to
    the camera buffer instead of the card; once the buffer filled, the body
    refused every release. GPIO shots now arm RAM, spill any leftover frames
    to captures/recovered_ram/, fire, and pull the new frame by event
    (about 6 s for both bodies instead of 15 s of card polling).
    Save to gains Pi (via RAM, default), Pi + cards (keep_card) and Cards
    only. Also: folder-local file numbers for --get-file, live view pauses
    around a GPIO shot instead of forcing USB, popup message history in
    System, and USB link speed on the camera cards.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
    [capture.js, dims.js, dual.py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]
2026-09-28 Stitch from RAW: develop both NEFs alike and blend them in 16-bit.
    Drive gains "Stitch from" (Camera JPEG / RAW). RAW develops T and R
    with rawpy using T's white balance, one shared gain matched to T's
    camera JPEG, and a highlight shoulder instead of a clip, then runs the
    SIFT + multiband stitch on the 16-bit frames. A SIFT miss falls back
    to the profile overlap on the same frames rather than the JPEG feather.
    The blender keeps 14 bits so bright edges cannot wrap in its int16
    pyramid.
    RAM pulls rename the JPEG before the NEF and let the camera file replace
    an extracted preview, so a shot no longer ends up as *_ram1.jpg.
    [dims.js, dual.py, model.js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]
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2026-09-29 Start web.py with the kiosk so every boot is a usable rig.
    The kiosk loop and bounce-web.sh bring the camera API on 8787 back up
    with FXPAN OS, reversing the earlier change that left the UI running
    without the backend after reboot.
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2026-09-30 Give the Nikkor-W a fixed R bayonet that focuses with the T arm.
    [WATCH_ME.scad, arm_r_focus.stl, params.scad]
2026-10-01 Fix Playback during stitches and add a plate keeper for slot rock.
    Reuse shot tiles while the capture list refreshes, warm T/R thumbs before auto-stitch, and defer the R flop until the frame loads so R is not a mirrored T. Add the 75×50 plate_key card, docs, and STL export.
    [WATCH_ME.scad, fxp_tray.scad, plate_key.stl]
2026-10-01 Centre the beamsplitter with ribs in the tray slot instead of loose cards.
    Opposite ribs at each end of both cheeks leave 1.10 mm for the 1.0 mm glass, so it sits where the R arm was cut for it and cannot lean. Drop plate_key.
    [WATCH_ME.scad, fxp_tray.scad, fxp_tray.stl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]
2026-10-01 Fit the camera helicoid cookies to the measured helicoid and metal F rings.
    The bought helicoid's 69 mm body is wider than the cookie, so its M42 tip
    now bottoms on a lip and the body floats 0.4 mm off the face. On the 1.93 mm
    ring the Nikkor-W cookies collapse inside focus, with R dialling out 1.55 mm
    and T 2.0 mm. CAM_HELI_CLOCK_R/T turn the thread start to correct roll.
    The EL helicoid cookies and printed F mounts can no longer reach focus with
    this helicoid, so they are out of the export.
    [WATCH_ME.scad, arm_r_h.stl, arm_r_h_inner.stl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]
2026-10-02 Add the FXPAN iPad app so both bodies can be driven and stitched over USB.
    The top bar uses the wordmark plus battery and Wi-Fi, and T/R assignment updates when the roles are swapped.
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2026-10-02 Finish Hugin stitches on device instead of getting killed, and keep the result inspectable while it runs.
    A body that disappears while the app is away is dropped, and the short background hold is released as soon as nothing is stitching.
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2026-10-02 Put the Nikkor-W shutter controls on top, and add a printed stand-in F ring.
    STEM_W_CLOCK turns the W stems' helicoid thread start 90° counter-clockwise
    facing the cookie, so the bottomed helicoid, nose and Copal stop a quarter
    turn round. temp_f_ring is an M52 male and F bayonet faced to the metal
    ring's 1.93 mm, for a camera helicoid whose ring has gone missing.
    [WATCH_ME.scad, params.scad, stem_m65.stl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]
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2026-10-06 Focus the Nikkor-W on its lens helicoid: fixed arms sized from the field focus, a chassis relief so the helicoid seats on the cookie, a tray stop that prints on the logo sill, and lid nuts captured i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
    [WATCH_ME.scad, arm_r_wl.stl, arm_r_wl_inner.stl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]
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2026-10-06 Mount the GPIO trigger stack on the lid and drop the monitor-rail hardware.
    Blind M2.5 standoff holes on the lid top hold the Zero and trigger board with jacks toward R; remove display-mount nut traps from the FXPAN export. Tighten phone hot-shoe feet slightly for a snugger D800 fit.
    [WATCH_ME.scad, display_mount.stl, duo_shoe.stl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]
2026-10-06 Shoot to camera RAM and download that frame, so a missing card cannot stall the release.
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2026-10-06 Match color in bands down the frame, so the trees' correction cannot pull the blue out of the sky.
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2026-10-09 Document the printed Nikkor-W FXPAN, and show how it goes together.
    The model notes still walked through reverse-ring mouths and the EL-Nikkor. This camera is the printed F arms and the Nikkor-W.
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2026-10-14 Fork FXPAN into a one-piece DXPAN chassis so the 50 mm plate, short M65 lip, and lid are one print and the saved millimetres sit on the tubes.
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2026-10-15 Let the helicoid seat on the DXPAN chassis and fix the 50 mm plate holder.
    Add a logo-wall relief matching the M65 hole, lengthen the slot for a full plate drop-in, and brace the holder into the logo wall without nibbling the channel.
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2026-10-15 Redesign the DXPAN plate slot so the coated face registers on R and the glass drops in without bowing.
    Pads and spring fingers clamp across the thickness instead of pinching the cheeks, with a clear channel and re-exported chassis STLs.
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2026-10-16 Hold the DXPAN plate at both top corners and open the F pin catch to 2.00 mm.
    A single top spring let the coated face tip, which walks the R frame off T, and the 1.99 mm pin slot was too tight for the lock pin to seat.
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

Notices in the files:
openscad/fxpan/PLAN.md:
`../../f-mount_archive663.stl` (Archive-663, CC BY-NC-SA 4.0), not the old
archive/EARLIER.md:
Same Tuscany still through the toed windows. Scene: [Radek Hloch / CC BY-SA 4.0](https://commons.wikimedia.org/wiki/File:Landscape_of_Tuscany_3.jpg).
